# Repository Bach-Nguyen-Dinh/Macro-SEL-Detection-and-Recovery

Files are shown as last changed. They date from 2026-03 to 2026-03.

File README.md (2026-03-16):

# Macro-SEL Detection and Recovery

A **hardware-only, autonomous protection system** for an ARM Cortex-A72 Edge Computer in LEO orbit. Detects and recovers from Macro Single Event Latchup (MacroSEL) events across 6 power rails — no firmware, no supervisory controller.

---

## Functional Overview

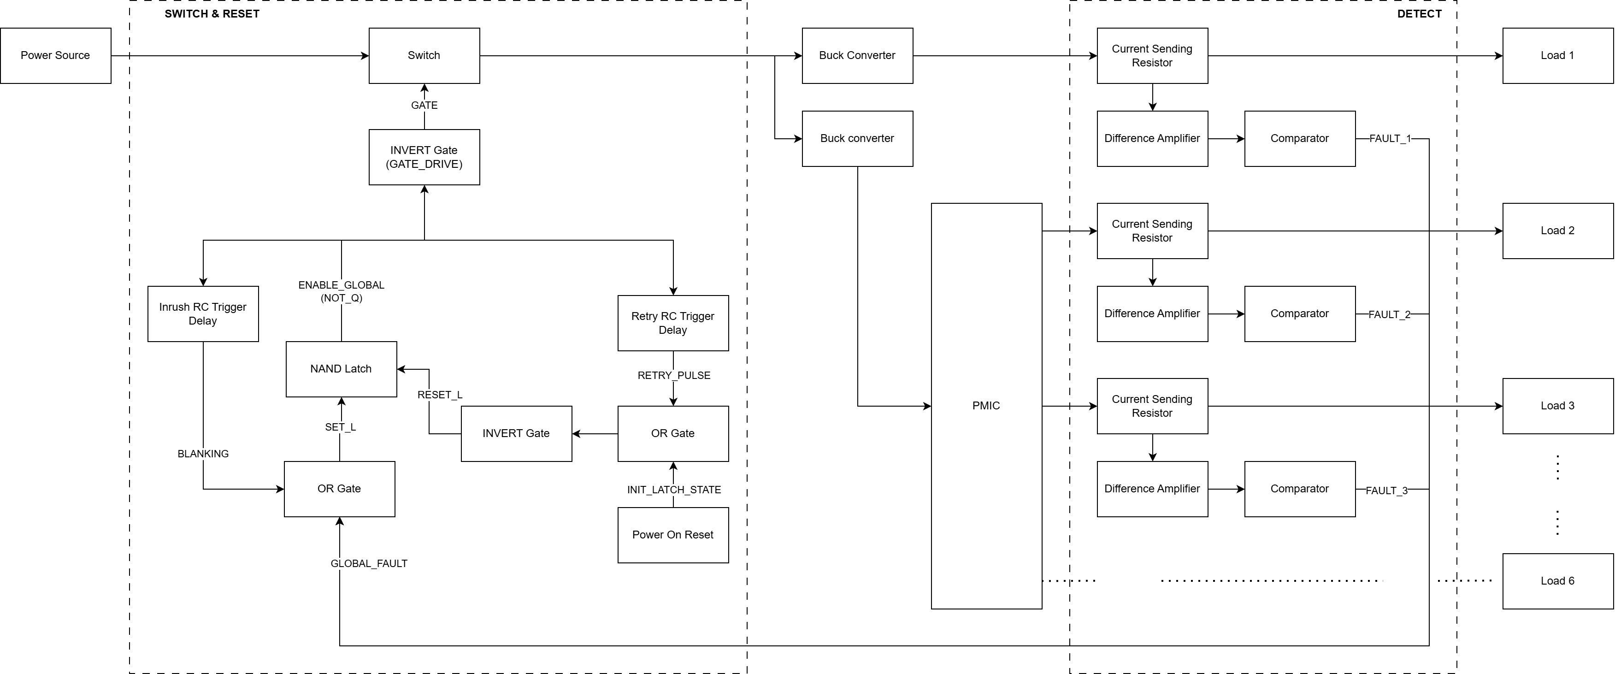
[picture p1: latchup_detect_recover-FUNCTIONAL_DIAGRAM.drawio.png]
Functional Diagram


On a latchup event, current on any protected rail exceeds 150% of its rated value. The protection system detects this within **3.64 µs**, latches the fault, cuts power via a master P-FET, and automatically retries after ~1 second.

---

## Mission Profile

| Parameter | Value |
|---|---|
| Orbit | LEO ~400 km |
| Mission life | 3-year minimum |
| TID environment | ~3–15 krad/year (shielding-dependent) |
| All-IC TID rating | ≥ 30 krad(Si) |
| LET hardness | 43–46 MeV·cm²/mg |

---

## Protected Power Rails

Trip threshold: **150% of rated current** on each rail.

| Rail | Voltage | Rated Current | Load | Shunt | Trip Current |
|---|---|---|---|---|---|
| 1 | 3.3 V | 5 A | AI Core #1 | 10 mΩ | 7.5 A |
| 2 | 3.3 V | 5 A | AI Core #2 | 10 mΩ | 7.5 A |
| 3 | 1.2 V | 3 A | CPU + DDR4 | 10 mΩ | 4.5 A |
| 4 | 1.35 V | 400 mA | CPU | 50 mΩ | 0.6 A |
| 5 | 1.8 V | 2 A | CPU + eMMC | 10 mΩ | 3.0 A |
| 6 | 2.5 V | 1 A | CPU + DDR4 | 10 mΩ | 1.5 A |

> Rail 4 uses 50 mΩ instead of 10 mΩ to achieve 300 kHz bandwidth (1.16 µs rise time) without excessive amplifier gain.

---

## Signal Flow

1. **Shunt resistor** — converts rail current to a millivolt-level differential voltage
2. **Stage 1: Difference amplifiers** (OPA4H838-SEP) — amplify shunt voltage to ~988 mV at trip point
3. **Stage 2: Comparators** (TLV1704-SEP, open-drain) — compare amplified signal to V_ref; pull shared wired-AND bus LOW on fault
4. **Wired-AND bus** — any single fault drives GLOBAL_FAULT LOW
5. **Blanking timer** (SN54SC6T17-SEP, 12–18 ms) — masks inrush false faults at startup
6. **SR latch** (SN54SC4T00-SEP) — latches fault state; holds ENABLE_GLOBAL LOW even after rails collapse
7. **Retry timer** (SN54SC6T17-SEP, τ = 2.2 s) — fires RETRY_PULSE ~0.79 s after fault, resets latch, attempts recovery
8. **Gate driver** (SN54SC6T14-SEP) — drives master P-FET gate; fail-safe OFF if driver loses power
9. **Master FET** (BUP06CP038F-01, P-channel) — switches all protected rails simultaneously

### Total Fault Response Time: 3.64 µs

| Stage | Delay |
|---|---|
| Amplifier rise (worst case, Rail 6) | 2.30 µs |
| Comparator propagation | 0.56 µs |
| Logic gates (OR + SR latch + inverter) | ~0.03 µs |
| P-FET turn-off (worst-case 3τ) | 0.75 µs |

---

## Bill of Materials

| Ref | Part | Function | Qty |
|-----|---|---|-----|
| Q1 | BUP06CP038F-01 | Master P-FET (−35 A cont., −140 A pulsed, 38 mΩ R_DS(on)) | 1 |
| U_AMP_A/B | OPA4H838-SEP | Quad op-amp — current sense amplifier | 2 |
| U_CMP_A/B | TLV1704-SEP | Quad comparator — open-drain output | 2 |
| U_LATCH | SN54SC4T00-SEP | Quad NAND — SR latch | 1 |
| U_OR | SN54SC4T32-SEP | Quad OR — SET_L + RESET_L logic | 1 |
| U_SCH | SN54SC6T17-SEP | Hex Schmitt — blanking timer + retry timer | 1 |
| U_INV | SN54SC6T14-SEP | Hex Schmitt inverter — gate driver + reset logic | 1 |
| Q_dis | JANSR2N3700UB | NPN — retry timer capacitor discharge | 1 |
| R_shunt (×5) | WSL2512R0100FEA | 10 mΩ ±1%, 2 W, Kelvin 4-wire | 5 |
| R_shunt (×1) | WSL2512R0500FEA | 50 mΩ ±1%, 2 W, Kelvin 4-wire (Rail 4) | 1 |

**Power**: Single 5 V spacecraft bus rail. Total consumption ~6.5 mA @ 5 V = **33 mW** (0.13% of 25 W system budget).

---

## Repository Structure

```
latchup_design/
├── AICRAFT_latchup_detect_recover.pdf       # Formal design document (authoritative)
├── MacroSEL_v4_Complete.docx                # Supporting reference
├── latchup_detect_recover.drawio            # draw.io source
├── latchup_detect_recover-*.drawio.png      # Sub-block diagrams
├── latchup_v4.0/                            # Component datasheets (flight parts)
│   ├── application_notes/                   # Referenced app notes
│   └── prototype_commercial_parts/          # Commercial equivalents for lab testing
└── latchup_v3.1/                            # Historical datasheets (v3.1)
```

### Circuit Diagrams

| File | Sub-block |
|---|---|
| `latchup_detect_recover-FUNCTIONAL_DIAGRAM.drawio.png` | Top-level system overview |
| `latchup_detect_recover-current_sense_amplifier.drawio.png` | Stage 1 difference amplifier |
| `latchup_detect_recover-comparator.drawio.png` | Stage 2 comparator |
| `latchup_detect_recover-Wired_AND_bus.drawio.png` | Open-drain fault aggregation |
| `latchup_detect_recover-NAND_SR_latch.drawio.png` | Fault state memory |
| `latchup_detect_recover-reference_voltage.drawio.png` | V_ref resistor divider |
| `latchup_detect_recover-power_on_reset.drawio.png` | Power-on reset |
| `latchup_detect_recover-delay_startup.drawio.png` | Startup blanking timer |
| `latchup_detect_recover-delay_retry.drawio.png` | Retry timer |
| `latchup_detect_recover-retry_pulse_gen.drawio.png` | Retry pulse generator |
| `latchup_detect_recover-set_fault_latched.drawio.png` | Set/reset OR logic |
| `latchup_detect_recover-gate_driver.drawio.png` | P-FET gate driver |
| `latchup_detect_recover-test_bench.drawio.png` | Test bench |

---

## Design Philosophy

- **Hardware-only** — no microcontroller, no firmware, no single point of software failure
- **Fail-safe OFF** — master FET turns off if gate driver loses power (10 kΩ pull-up to 5 V)
- **Every component justifies its existence** — no redundant logic, no speculative features
- **Single power domain** — all protection circuits powered from 5 V spacecraft bus, independent of protected rails

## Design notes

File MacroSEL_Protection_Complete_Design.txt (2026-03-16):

================================================================================
MACRO-SEL PROTECTION SYSTEM - COMPLETE DESIGN PACKAGE
Space-Qualified Edge Computer for LEO Orbit
================================================================================

Document Version: 1.0
Date: February 2026
Application: ARM Cortex-A72 Edge Computer with AI Cores, DDR4, eMMC
Mission Profile: LEO, 1+ year, 10 krad/year TID
Design Philosophy: Hardware-only, interconnected shutdown, 5 retry attempts

================================================================================
TABLE OF CONTENTS
================================================================================

1. SYSTEM ARCHITECTURE OVERVIEW
2. DETAILED SCHEMATIC: SINGLE RAIL PROTECTION CIRCUIT
3. GLOBAL LOGIC & RETRY CONTROLLER SCHEMATIC
4. FULL 6-RAIL SYSTEM INTEGRATION
5. COMPLETE BILL OF MATERIALS (BOM)
6. PCB LAYOUT GUIDELINES
7. TESTING & VALIDATION PROCEDURES
8. FAILURE MODE & EFFECTS ANALYSIS (FMEA)
9. DESIGN VERIFICATION CHECKLIST

================================================================================
1. SYSTEM ARCHITECTURE OVERVIEW
================================================================================

PROTECTION STRATEGY:
- 6 independent protection circuits (one per power rail)
- Interconnected shutdown: ANY rail fault → ALL rails shut down
- Hardware-only auto-retry: 5 attempts with 100ms delay
- After 5 failures: Permanent latch-off until power cycle
- 300ms startup delay from PMIC PGOOD signal

PROTECTED RAILS:
Rail #1: 3.3V @ 5A  (AI Core #1)
Rail #2: 3.3V @ 5A  (AI Core #2)
Rail #3: 1.2V @ 3A  (CPU + DDR4 RAM)
Rail #4: 1.35V @ 400mA (CPU)
Rail #5: 1.8V @ 2A  (CPU + eMMC)
Rail #6: 2.5V @ 1A  (CPU + DDR4 RAM)

RESPONSE TIME TARGET: <20µs (well within macro-SEL damage threshold of ~100µs)

RADIATION TOLERANCE: All protection components rated 50-100+ krad TID

================================================================================
2. DETAILED SCHEMATIC: SINGLE RAIL PROTECTION CIRCUIT (TYPICAL)
================================================================================

This schematic applies to ONE rail. Replicate 6 times with component values
adjusted per rail specifications.

Example: Rail #3 (1.2V @ 3A - CPU + DDR4 RAM)

┌────────────────────────────────────────────────────────────────────────┐
│                     SINGLE RAIL PROTECTION CIRCUIT                      │
│                          (Typical - 1.2V 3A Rail)                       │
└────────────────────────────────────────────────────────────────────────┘

INPUT (from PMIC)                                   OUTPUT (to Load - CPU/RAM)
    │                                                        │
    ├─────[R_SENSE: 20mΩ, 2W]─────┬──────[P_FET]──────────┤
    │                              │       Q1               │
    │                              │                        │
    │  ┌──[R1: 10kΩ]──┬──────────┤GATE                    │
    │  │              │            │                        │
    │  │              │            │SOURCE                  │
    │  │              └────────────┤                        │
    │  │                           │                        │
    │  │                           │DRAIN                   │
    │  │                           └────────────────────────┤
    │  │                                                    │
    │  │  CURRENT SENSE AMPLIFIER (OP07)                   │
    │  │                                                    │
    │  │      V_SENSE+              V_SENSE-               │
    │  │          │                     │                  │
    │  │          ↓                     ↓                  │
    │  │      ┌───────────────────────────┐               │
    │  │      │         OP07              │               │
    │  │      │    (Diff Amplifier)       │               │
    │  │      │      Gain = 20            │               │
    │  │      └──────────┬────────────────┘               │
    │  │                 │ V_AMP (0-2V range)             │
    │  │                 │                                │
    │  │                 │                                │
    │  │      COMPARATOR & LATCH                          │
    │  │                 │                                │
    │  │                 ↓                                │
    │  │      ┌───────────────────────┐                   │
    │  │      │     LM139AJ           │                   │
    │  │  ┌───┤+  (Threshold: 70mV×20 │                   │
    │  │  │   │      = 1.4V)          │                   │
    │  │  │V_REF -                    │                   │
    │  │  │   └─────────┬─────────────┘                   │
    │  │  │             │ FAULT_RAW                       │
    │  │  │             │                                 │
    │  │  │             ↓                                 │
    │  │  │   ┌──────────────────────┐                   │
    │  │  │   │   CD4013BE           │                   │
    │  │  │   │   D Flip-Flop        │                   │
    │  │  └───┤D                     Q├───┐               │
    │  │      │                       │   │ FAULT_LATCHED │
    │  │  ┌───┤CLK              /Q    │   │ (to Global OR)│
    │  │  │   │                       │   │               │
    │  │  │   │         RESET ────────┤───┘               │
    │  │  │   └───────────────────────┘   │               │
    │  │  │                               │               │
    │  │  │                               │               │
    │  │  │   GATE DRIVER LOGIC           │               │
    │  │  │                               │               │
    │  │  │   ENABLE_GLOBAL ──┐           │               │
    │  │  │                   │           │               │
    │  │  │                   ↓           │               │
    │  │  │            ┌─────────────┐    │               │
    │  │  │            │  CD4081BE   │    │               │
    │  │  │            │  (AND gate) │    │               │
    │  │  └────────────┤             │    │               │
    │  │               └──────┬──────┘    │               │
    │  │                      │ GATE_CTRL │               │
    │  │                      └───────────┴───[R2: 100Ω]──┘
    │  │
    │  └──────────────────────────────────────────────[R3: 10kΩ to VIN]
    │
    └───────────────────────────[Bulk Cap: 100µF]─────────GND

COMPONENT VALUES FOR RAIL #3 (1.2V @ 3A):

R_SENSE:  20mΩ, 2W (Vishay WSL2512 or equivalent)
          Normal: 3A × 20mΩ = 60mV
          Trip: 3.5A × 20mΩ = 70mV

Q1:       IRHLUC7970Z4 (P-channel MOSFET, rad-hard, 100V, 30mΩ RDS(on))
          or IRH8S9N50R (alternative)

U1:       OP07CP (Bipolar op-amp, 100+ krad TID, QML available)
          Configured as differential amplifier, Gain = 20
          Output: 60mV × 20 = 1.2V (normal), 70mV × 20 = 1.4V (trip)

U2:       LM139AJ/883C (Quad comparator, 100+ krad TID, QML)
          V_REF = 1.3V (set by voltage divider)
          Hysteresis: 50mV via positive feedback

U3:       CD4013BE/883B (Dual D Flip-Flop, 100+ krad TID, CMOS)
          Latches fault condition until RESET pulse

U4:       CD4081BE/883B (Quad 2-input AND gate, 100+ krad TID, CMOS)
          Gates ENABLE with latched fault signal

R1:       10kΩ (pull-up for P-FET gate)
R2:       100Ω (gate drive resistor, limits dI/dt)
R3:       10kΩ (pull-down when FET should be off)

All resistors: Metal film, 1%, 0.1W minimum
All capacitors: Ceramic C0G/NP0 or tantalum, space-qualified

SENSE RESISTOR & TRIP THRESHOLD TABLE FOR ALL 6 RAILS:

┌─────────┬────────────┬────────┬─────────┬──────────┬────────────┬──────────┐
│  Rail   │  Voltage   │ Normal │  Trip   │ R_SENSE  │  V_SENSE   │  V_AMP   │
│         │            │ Current│ Current │          │  @ Trip    │  @ Trip  │
├─────────┼────────────┼────────┼─────────┼──────────┼────────────┼──────────┤
│ AI #1   │ 3.3V       │ 5.0A   │ 5.8A    │ 10mΩ, 2W │ 58mV       │ 1.16V    │
│ AI #2   │ 3.3V       │ 5.0A   │ 5.8A    │ 10mΩ, 2W │ 58mV       │ 1.16V    │
│ CPU/RAM │ 1.2V       │ 3.0A   │ 3.5A    │ 20mΩ, 2W │ 70mV       │ 1.40V    │
│ CPU     │ 1.35V      │ 0.4A   │ 0.5A    │ 100mΩ, 1W│ 50mV       │ 1.00V    │
│ CPU/eMMC│ 1.8V       │ 2.0A   │ 2.3A    │ 30mΩ, 1W │ 69mV       │ 1.38V    │
│ CPU/RAM │ 2.5V       │ 1.0A   │ 1.2A    │ 50mΩ, 1W │ 60mV       │ 1.20V    │
└─────────┴────────────┴────────┴─────────┴──────────┴────────────┴──────────┘

Note: Amplifier gain = 20 for all rails
      Comparator V_REF adjusted per rail (trip voltage × 20)

SIGNAL NAMES & INTERCONNECTIONS:

Per-Rail Signals:
- FAULT_LATCHED_n (where n = 1 to 6): Goes to Global OR gate
- ENABLE_GLOBAL: Comes from Global Logic, enables all protection circuits

Power Connections:
- VIN_n: Input from PMIC for each rail
- VOUT_n: Output to load for each rail
- VDD_LOGIC: +5V for logic ICs (from main 5V bus)
- GND: Common ground

================================================================================
3. GLOBAL LOGIC & RETRY CONTROLLER SCHEMATIC
================================================================================

This circuit manages:
1. 300ms startup delay from PMIC PGOOD
2. Fault aggregation from all 6 rails
3. Retry counter (5 attempts)
4. 100ms inter-retry delay
5. Permanent latch-off after 5 failures

┌────────────────────────────────────────────────────────────────────────┐
│                   GLOBAL LOGIC & RETRY CONTROLLER                       │
└────────────────────────────────────────────────────────────────────────┘

SECTION A: STARTUP DELAY (300ms from PMIC PGOOD)

PMIC_PGOOD ──┬─────[R4: 1MΩ]───┬───────┐
             │                  │       │
             │                  │       ↓
             │              [C1: 330nF] │  ┌──────────────────┐
             │                  │       │  │   CD4093BE       │
             │                  │       └──┤  Schmitt Trigger │
             │                  │          │   (Buffer)       │
             └──────────────────┴──────────┤                  ├──→ PGOOD_DELAYED
                                            └──────────────────┘

Time constant: τ = R4 × C1 = 1MΩ × 330nF = 330ms

SECTION B: FAULT AGGREGATION (6-input OR gate)

FAULT_LATCHED_1 ──┐
FAULT_LATCHED_2 ──┤
FAULT_LATCHED_3 ──┤  ┌──────────────────┐
FAULT_LATCHED_4 ──┼──┤   CD4072BE       │
FAULT_LATCHED_5 ──┤  │   (Dual 4-input  │
FAULT_LATCHED_6 ──┘  │    OR gate)      ├───→ GLOBAL_FAULT
                     └──────────────────┘

Note: Use 2× CD4072BE to implement 6-input OR
      (each CD4072BE has dual 4-input OR gates)

SECTION C: RETRY TIMER (100ms delay generator)

GLOBAL_FAULT ──→ Trigger

                 ┌──────────────────────┐
                 │      LM555CN         │
                 │  (Monostable timer)  │
                 │                      │
   VDD ──[R5]────┤DISCH        OUT      ├───→ RETRY_PULSE (100ms pulse)
          │      │                      │
          │      │                      │
       [C2]──────┤THRESH         GND    │
          │      │                      │
          │      │TRIG                  │
          │      └──────────────────────┘
          │          ↑
          │          │
        [R6]─────────┴──── GLOBAL_FAULT (inverted trigger)
          │
         GND

Component Values:
R5 = 1MΩ
C2 = 100nF
R6 = 10kΩ (trigger resistor)

Time delay: t = 1.1 × R5 × C2 = 1.1 × 1MΩ × 100nF = 110ms

SECTION D: RETRY COUNTER (counts fault events, max = 5)

RETRY_PULSE ──→ CLK

                 ┌──────────────────────┐
                 │      CD4017BE        │
                 │   (Decade Counter)   │
                 │                      │
   RETRY_PULSE ──┤CLK              Q0   ├───→ (unused)
                 │                 Q1   ├───→ (unused)
                 │                 Q2   ├───→ (unused)
                 │                 Q3   ├───→ (unused)
                 │                 Q4   ├───→ (unused)
                 │                 Q5   ├───→ COUNT_5 (5th retry)
                 │                 Q6-9 ├───→ (unused)
                 │                      │
   POWER_CYCLE ──┤RESET                 │
                 └──────────────────────┘

SECTION E: PERMANENT LATCH (after 5 retries, latch off)

COUNT_5 ──→ SET

                 ┌──────────────────────┐
                 │      CD4013BE        │
                 │     (D Flip-Flop)    │
                 │                      │
      VDD ───────┤D                  Q  ├───→ LATCH_OFF
                 │                      │
   COUNT_5 ──────┤SET                   │
                 │                      │
   POWER_CYCLE ──┤RESET                 │
                 └──────────────────────┘

SECTION F: GLOBAL ENABLE GENERATION

Combines all enable/disable conditions:

ENABLE_GLOBAL = PGOOD_DELAYED AND (NOT LATCH_OFF) AND (NOT RETRY_IN_PROGRESS)

                 ┌──────────────────────┐
PGOOD_DELAYED ───┤                      │
                 │    CD4081BE          │
(NOT LATCH_OFF)──┤    (3-input AND)     ├───→ ENABLE_GLOBAL
                 │    (configured)      │     (to all 6 protection circuits)
(NOT RETRY_PROG.)┤                      │
                 └──────────────────────┘

RETRY_IN_PROGRESS = RETRY_PULSE (active during 100ms retry delay)

SECTION G: RESET PULSE GENERATOR (resets all D flip-flops after retry delay)

RETRY_PULSE (falling edge) triggers a short pulse to reset fault latches

                 ┌──────────────────────┐
RETRY_PULSE ─────┤     Edge Detector    │
  (falling) ─────┤   (R-C differentiator)├───→ RESET_PULSE (to all fault latches)
                 └──────────────────────┘

Circuit: Simple RC high-pass filter + diode
         Rising edge blocks, falling edge passes through as short pulse

POWER SUPPLY FOR LOGIC:
- VDD_LOGIC: +5V (from main 5V power bus)
- All logic ICs powered from this rail
- Decouple each IC with 0.1µF + 10µF tantalum local to each IC

COMPLETE SIGNAL FLOW:

1. Power-on: PMIC_PGOOD goes high
2. After 300ms: PGOOD_DELAYED goes high
3. ENABLE_GLOBAL = HIGH (all protection circuits enabled)
4. If latchup occurs on any rail → FAULT_LATCHED_n goes HIGH
5. GLOBAL_FAULT = HIGH (OR of all 6 fault signals)
6. LM555 triggers: RETRY_PULSE = HIGH for 100ms
7. During RETRY_PULSE: ENABLE_GLOBAL = LOW (all rails shut down)
8. After 100ms: RETRY_PULSE falling edge generates RESET_PULSE
9. RESET_PULSE clears all fault latches, ENABLE_GLOBAL = HIGH (retry)
10. Retry counter increments (CD4017BE)
11. Repeat steps 4-10 up to 5 times
12. On 5th retry: COUNT_5 sets LATCH_OFF permanently
13. ENABLE_GLOBAL = LOW forever (until power cycle)

================================================================================
4. FULL 6-RAIL SYSTEM INTEGRATION DIAGRAM
================================================================================

                        ┌──────────────────────────────────┐
                        │      PMIC (MC33PF8100EAES)       │
                        │                                  │
     5V Input ──────────┤VIN                          PGOOD├──→ To Global Logic
                        │                                  │
                        │    1.2V ──────────────────────── ├──→ Rail #3 Input
                        │    1.35V ─────────────────────── ├──→ Rail #4 Input
                        │    1.8V ──────────────────────── ├──→ Rail #5 Input
                        │    2.5V ──────────────────────── ├──→ Rail #6 Input
                        └──────────────────────────────────┘
                                         │
                                         │
      ┌──────────────────────────────────┴──────────────────────────────┐
      │                                                                  │
      │         Buck Converter #1 (LTC3310S)                             │
      │         3.3V 10A (for both AI cores)                             │
      │                                                                  │
      │    3.3V AI ────────────────────────────────────────────────────→ Rail #1 Input
      │    3.3V AI ────────────────────────────────────────────────────→ Rail #2 Input
      └──────────────────────────────────────────────────────────────────┘

                   ┌─────────────────────────────────────┐
                   │     GLOBAL LOGIC & RETRY CONTROLLER │
                   │                                     │
    PMIC_PGOOD ────┤Input                                │
                   │                                     │
    FAULT_1 ───────┤──┐                                  │
    FAULT_2 ───────┤  │                                  │
    FAULT_3 ───────┤  ├──→ OR Gate                      │
    FAULT_4 ───────┤  │                                  │
    FAULT_5 ───────┤  │                                  │
    FAULT_6 ───────┤──┘                                  │
                   │         ↓                           │
                   │    Retry Logic                      │
                   │         ↓                           │
                   │   ENABLE_GLOBAL ────────────────────┼──→ To all 6 protection circuits
                   │   RESET_PULSE ──────────────────────┼──→ To all 6 fault latches
                   └─────────────────────────────────────┘

        ┌───────────────────────────────────────────────────────────┐
        │                    6 PROTECTION CIRCUITS                  │
        │                       (One per rail)                      │
        ├───────────────────────────────────────────────────────────┤
        │                                                           │
        │  Rail #1: 3.3V 5A (AI Core #1)    ──→ Sense → Compare ──┼──→ FAULT_1
        │  Rail #2: 3.3V 5A (AI Core #2)    ──→ Sense → Compare ──┼──→ FAULT_2
        │  Rail #3: 1.2V 3A (CPU + RAM)     ──→ Sense → Compare ──┼──→ FAULT_3
        │  Rail #4: 1.35V 400mA (CPU)       ──→ Sense → Compare ──┼──→ FAULT_4
        │  Rail #5: 1.8V 2A (CPU + eMMC)    ──→ Sense → Compare ──┼──→ FAULT_5
        │  Rail #6: 2.5V 1A (CPU + RAM)     ──→ Sense → Compare ──┼──→ FAULT_6
        │                                                           │
        │  Each circuit contains:                                  │
        │  - Sense resistor + amplifier                            │
        │  - Comparator + latch                                    │
        │  - P-FET load switch                                     │
        └───────────────────────────────────────────────────────────┘
                            ↓            ↓
                      Outputs to:   Outputs to:
                    Protected Loads  Global Logic

SYSTEM BEHAVIOR SUMMARY:

Normal Operation:
- All 6 rails powered and monitored
- Current < threshold → No faults
- ENABLE_GLOBAL = HIGH

Latchup Event (e.g., on Rail #3):
1. Current spikes above 3.5A threshold
2. FAULT_3 goes HIGH
3. GLOBAL_FAULT = HIGH (via OR gate)
4. ALL 6 protection circuits disable (ENABLE_GLOBAL = LOW)
5. Wait 100ms
6. Reset all latches, ENABLE_GLOBAL = HIGH (1st retry)
7. Increment retry counter
8. If latchup recurs → repeat up to 5 times total
9. After 5th retry → LATCH_OFF permanently until power cycle

================================================================================
5. COMPLETE BILL OF MATERIALS (BOM)
================================================================================

PER-RAIL COMPONENTS (×6 sets):

┌──────┬─────────────────────┬──────────┬──────────────────────┬──────────┬────────┐
│ Qty  │ Part Number         │ Function │ Description          │ Rad Tol. │ Cost   │
├──────┼─────────────────────┼──────────┼──────────────────────┼──────────┼────────┤
│  6   │ WSL2512 (various)   │ R_SENSE  │ Current sense        │ Passive  │ $3 ea  │
│      │   10mΩ, 20mΩ, etc.  │          │ resistor, 1-2W       │ (rad-hard)│       │
├──────┼─────────────────────┼──────────┼──────────────────────┼──────────┼────────┤
│  6   │ OP07CP or           │ U1       │ Precision op-amp     │ 100+ krad│ $25 ea │
│      │ OP07CP/883B (QML)   │          │ for sense amplifier  │          │        │
├──────┼─────────────────────┼──────────┼──────────────────────┼──────────┼────────┤
│  2   │ LM139AJ/883C        │ U2       │ Quad comparator      │ 100+ krad│ $30 ea │
│      │ (each has 4 comps)  │          │ (need 6 total)       │          │        │
├──────┼─────────────────────┼──────────┼──────────────────────┼──────────┼────────┤
│  6   │ IRHLUC7970Z4 or     │ Q1       │ P-channel MOSFET     │ 100 krad │ $50 ea │
│      │ IRH8S9N50R          │          │ load switch          │          │        │
├──────┼─────────────────────┼──────────┼──────────────────────┼──────────┼────────┤
│  3   │ CD4013BE/883B       │ U3       │ Dual D flip-flop     │ 100+ krad│ $20 ea │
│      │ (each has 2 FFs)    │          │ (need 6 total)       │          │        │
├──────┼─────────────────────┼──────────┼──────────────────────┼──────────┼────────┤
│  2   │ CD4081BE/883B       │ U4       │ Quad 2-input AND     │ 100+ krad│ $18 ea │
│      │ (each has 4 ANDs)   │          │ (need 6 total)       │          │        │
└──────┴─────────────────────┴──────────┴──────────────────────┴──────────┴────────┘

Subtotal per-rail components: ~$146 × 6 = $876

GLOBAL LOGIC COMPONENTS (×1 set):

┌──────┬─────────────────────┬──────────┬──────────────────────┬──────────┬────────┐
│ Qty  │ Part Number         │ Function │ Description          │ Rad Tol. │ Cost   │
├──────┼─────────────────────┼──────────┼──────────────────────┼──────────┼────────┤
│  2   │ CD4072BE/883B       │ U5       │ Dual 4-input OR      │ 100+ krad│ $22 ea │
│      │                     │          │ (for 6-input OR)     │          │        │
├──────┼─────────────────────┼──────────┼──────────────────────┼──────────┼────────┤
│  1   │ CD4093BE/883B       │ U6       │ Quad Schmitt trigger │ 100+ krad│ $20    │
│      │                     │          │ NAND buffer          │          │        │
├──────┼─────────────────────┼──────────┼──────────────────────┼──────────┼────────┤
│  1   │ LM555CN/883C        │ U7       │ Timer IC             │ 100+ krad│ $28    │
│      │                     │          │ (retry delay)        │          │        │
├──────┼─────────────────────┼──────────┼──────────────────────┼──────────┼────────┤
│  1   │ CD4017BE/883B       │ U8       │ Decade counter       │ 100+ krad│ $22    │
│      │                     │          │ (retry counter)      │          │        │
├──────┼─────────────────────┼──────────┼──────────────────────┼──────────┼────────┤
│  1   │ CD4013BE/883B       │ U9       │ Dual D flip-flop     │ 100+ krad│ $20    │
│      │                     │          │ (latch-off FF)       │          │        │
├──────┼─────────────────────┼──────────┼──────────────────────┼──────────┼────────┤
│  1   │ CD4081BE/883B       │ U10      │ Quad AND gate        │ 100+ krad│ $18    │
│      │                     │          │ (enable logic)       │          │        │
├──────┼─────────────────────┼──────────┼──────────────────────┼──────────┼────────┤
│  1   │ CD4049UBE/883B      │ U11      │ Hex inverter/buffer  │ 100+ krad│ $18    │
│      │                     │          │ (logic inversion)    │          │        │
└──────┴─────────────────────┴──────────┴──────────────────────┴──────────┴────────┘

Subtotal global logic: $170

PASSIVE COMPONENTS:

┌──────┬─────────────────────┬──────────┬──────────────────────┬──────────┬────────┐
│ Qty  │ Description         │ Function │ Specifications       │ Notes    │ Cost   │
├──────┼─────────────────────┼──────────┼──────────────────────┼──────────┼────────┤
│  40  │ Resistors (various) │ Biasing  │ 1/8W to 1/4W,        │ Metal    │ $1 ea  │
│      │ 100Ω - 1MΩ          │ timing   │ 1%, metal film       │ film     │        │
├──────┼─────────────────────┼──────────┼──────────────────────┼──────────┼────────┤
│  20  │ Capacitors 0.1µF    │ Decoupl. │ Ceramic C0G/NP0      │ Local to │ $2 ea  │
│      │                     │          │ 50V, space-qual      │ each IC  │        │
├──────┼─────────────────────┼──────────┼──────────────────────┼──────────┼────────┤
│  15  │ Capacitors 10µF     │ Bulk     │ Tantalum or ceramic  │ Power    │ $5 ea  │
│      │                     │ decoupl. │ 16V min              │ supply   │        │
├──────┼─────────────────────┼──────────┼──────────────────────┼──────────┼────────┤
│  6   │ Capacitors 100µF    │ Output   │ Tantalum or ceramic  │ Per rail │ $8 ea  │
│      │                     │ filter   │ Low ESR, rated for   │ output   │        │
│      │                     │          │ rail voltage         │          │        │
├──────┼─────────────────────┼──────────┼──────────────────────┼──────────┼────────┤
│  3   │ Timing capacitors   │ 555,RC   │ 100nF, 330nF         │ Timing   │ $3 ea  │
│      │ (330nF, 100nF)      │ networks │ C0G/NP0 ceramic      │ critical │        │
└──────┴─────────────────────┴──────────┴──────────────────────┴──────────┴────────┘

Subtotal passives: ~$200

GRAND TOTAL BOM COST: $876 + $170 + $200 = **$1,246**

Note: Costs are estimates. QML/QMLV space-qualified parts may vary.
      Long-lead items: MOSFET switches (~12-16 weeks), QML logic ICs (~8-12 weeks)

ALTERNATIVE COMPONENT SELECTIONS:

If IRHLUC7970Z4 unavailable:
- Alternative 1: SI4425DDY-T1-GE3 (vishay, lower cost, ~30 krad)
- Alternative 2: Custom discrete with bipolar transistors (100% rad-hard)

If OP07CP unavailable:
- Alternative: LM124A/883 (quad op-amp, lower precision but adequate)

All CD4000 series logic:
- Widely available in QML/QMLV grades
- Multiple suppliers (TI, Intersil/Renesas, ON Semi)

================================================================================
6. PCB LAYOUT GUIDELINES
================================================================================

CRITICAL LAYOUT REQUIREMENTS FOR SPACE ENVIRONMENT:

A. GENERAL PCB STACK-UP
   - 4-layer minimum (Signal-Ground-Power-Signal)
   - 6-layer preferred (S-G-S-P-G-S) for better EMI control
   - FR-4 acceptable for LEO (consider polyimide for harsher environments)
   - Copper weight: 2oz minimum for power traces, 1oz for signals
   - Conformal coating: Yes (required for space, use silicone or acrylic)

B. POWER PATH LAYOUT (CRITICAL!)

   For each protection circuit:

   1. SENSE RESISTOR PLACEMENT:
      - Place R_SENSE as close as possible to input connector/via
      - Use 4-wire (Kelvin) connection:
         * Force+ and Force- carry load current (wide, short traces)
         * Sense+ and Sense- are thin traces directly to op-amp inputs
      - Keep sense traces away from switching nodes and high-current paths
      - Minimum trace width for sense lines: 10 mils (0.25mm)
      - Guard ring around sense traces (optional, for extra noise immunity)

      Layout example (top view):
      
      VIN ══════════[Force+]══════[R_SENSE]══════[Force-]════════ VOUT
                         │                          │
                    [Sense+]                   [Sense-]
                         │                          │
                         └─────→ To OP07 ←──────────┘
                         (thin traces, 10-15 mils)

   2. P-FET MOSFET PLACEMENT:
      - Place immediately after sense resistor (<5mm spacing if possible)
      - Minimize trace inductance in drain-source path (use wide, short traces)
      - Gate trace: Keep <50mm long, use series resistor (100Ω) near gate pin
      - Source connection: Star-point ground reference for gate driver
      - Heatsinking: Ensure thermal pad connected to ground plane (or dedicated)

   3. POWER TRACE WIDTHS (for 3A continuous, 5A peak):
      - 1.2V rail @ 3A: 80 mils (2mm) minimum width, 2oz copper
      - 3.3V rail @ 5A: 120 mils (3mm) minimum width, 2oz copper
      - Formula: I_max = 0.048 × dT^0.44 × A^0.725
        (where dT = temperature rise in °C, A = cross-sectional area in mils²)
      - For space: Derate by 50% (vacuum cooling is worse than air)

   4. DECOUPLING CAPACITOR PLACEMENT:
      - 0.1µF ceramic: <5mm from each IC VDD pin
      - 10µF tantalum: <10mm from each IC
      - 100µF bulk: At each rail output, near load connection
      - Via-in-pad for decoupling caps when possible (low inductance)

C. SIGNAL INTEGRITY (COMPARATOR & LOGIC)

   1. V_REF GENERATION:
      - Use precision voltage divider for comparator reference
      - Add 0.1µF bypass cap at V_REF node (local to comparator)
      - Keep V_REF trace <20mm long, away from switching nodes

   2. DIGITAL LOGIC TRACES:
      - Keep clock and pulse signals <50mm long
      - Use ground guard traces around critical signals (RETRY_PULSE, RESET_PULSE)
      - Minimize stub lengths on clock inputs (<5mm)

   3. FAULT SIGNAL ROUTING:
      - FAULT_LATCHED_1 to FAULT_LATCHED_6: Route together as bus
      - Use consistent spacing (50-100 mils between traces)
      - Avoid crossing power planes or high-current traces
      - Shielded by ground traces on either side if EMI is concern

D. GROUNDING STRATEGY

   Single-point star ground vs. ground plane:
   - Use ground plane (Layer 2) as primary reference
   - Create "analog island" for sense amplifier circuits:
      * Local ground pour for OP07 and comparator
      * Connect analog island to main ground at ONE point (star)
   - Digital logic: Use main ground plane (no isolation needed)
   - Power ground: Separate heavy current return paths from signal ground

   Ground plane stitching:
   - Place vias every 200-300 mils around perimeter of board
   - Additional vias near every decoupling capacitor (direct path to plane)

E. COMPONENT PLACEMENT STRATEGY

   Zone separation:
   ┌─────────────────────────────────────────────────┐
   │  ZONE 1: Input Filtering & Delay                │
   │  (PGOOD, RC delay, Schmitt trigger)             │
   │                                                 │
   ├─────────────────────────────────────────────────┤
   │  ZONE 2: Protection Circuits (6× identical)     │
   │  Rail 1 │ Rail 2 │ Rail 3 │ Rail 4 │ Rail 5 │ 6│
   │  (Sense)(Sense)(Sense)(Sense)(Sense)(Sense)   │
   │  (each 20×30mm footprint, total ~100×30mm)     │
   │                                                 │
   ├─────────────────────────────────────────────────┤
   │  ZONE 3: Global Logic                           │
   │  (OR gate, timer, counter, latch)               │
   │  (Keep compact, ~30×40mm)                       │
   └─────────────────────────────────────────────────┘

   Keep protection circuits identical and aligned for easy debug/rework.

F. THERMAL MANAGEMENT

   1. P-FET MOSFET:
      - Power dissipation: P = I²·RDS(on)
        Example: 5A² × 30mΩ = 0.75W per FET
      - Use thermal vias under FET thermal pad (array of 3×3 vias, 12 mil drill)
      - Connect to internal ground/power plane for heat spreading
      - Consider adding external heatsink or larger copper pour if >1W

   2. SENSE RESISTORS:
      - Power dissipation during latchup: I²·R (can be 1-2W briefly)
      - Use wide thermal relief connections (not thin "spider" reliefs)
      - Large copper pour around resistor body for heat spreading

   3. LM555 TIMER:
      - Can dissipate 100-200mW, provide thermal relief via bottom pad

G. EMI/EMC CONSIDERATIONS

   1. Switching transients (P-FET turn-off):
      - Use snubber across FET drain-source: 100Ω + 100nF in series
      - Minimize loop area between FET, sense resistor, and output capacitor

   2. Radiated emissions:
      - Route all high-frequency traces (comparator outputs, clock signals)
         on inner layers when possible
      - Keep traces >50 mils away from board edges

   3. Conducted emissions:
      - Input filtering: Add ferrite bead + 10µF cap on PMIC_PGOOD signal
      - Use common-mode chokes on power inputs if EMI is critical

H. CONFORMAL COATING CONSIDERATIONS

   - Mask off: Sense resistors (for thermal dissipation)
   - Mask off: Test points and rework areas
   - Ensure coating thickness: 50-100µm (2-4 mils)
   - Cure per space specifications (vacuum bake-out required)

I. TEST POINTS & DEBUG ACCESS

   Required test points (place on accessible layer):
   - TP1: PMIC_PGOOD
   - TP2: PGOOD_DELAYED
   - TP3: ENABLE_GLOBAL
   - TP4-TP9: FAULT_LATCHED_1 through FAULT_LATCHED_6
   - TP10: GLOBAL_FAULT
   - TP11: RETRY_PULSE
   - TP12: LATCH_OFF
   - TP13-TP18: V_AMP outputs (one per rail, for calibration)

   Use castellated holes or small vias (not plated) for semi-permanent access.

J. SPACE-SPECIFIC REQUIREMENTS

   1. Tin whisker mitigation:
      - Use matte tin plating (NOT bright tin)
      - Or use ENIG (Electroless Nickel Immersion Gold) finish

   2. Outgassing compliance:
      - PCB material: TML <1.0%, CVCM <0.1% (NASA ASTM E595)
      - Conformal coating: Space-qualified silicone (DC 1-2577) or acrylic

   3. Vibration/shock mounting:
      - Use edge-mounted support brackets
      - Avoid large, unsupported component bodies (>10mm tall)
      - Add potting to large capacitors (epoxy underfill)

   4. Thermal cycling:
      - Design for -40°C to +85°C operation (or wider if required)
      - Avoid mismatched CTE materials near critical junctions

K. DESIGN FOR TESTABILITY (DFT)

   - Break-out pads for each rail input/output (allow isolation testing)
   - Enable/disable jumpers for each protection circuit (debug one rail at a time)
   - LED indicators for FAULT_LATCHED signals (optional, for ground testing)

================================================================================
7. TESTING & VALIDATION PROCEDURES
================================================================================

PHASE 1: COMPONENT-LEVEL TESTING (Before PCB Assembly)
-------------------------------------------------------

Test 1.1: Sense Resistor Verification
   Objective: Verify resistance value and power rating
   Equipment: 4-wire ohmmeter, power supply, electronic load
   Procedure:
   1. Measure resistance with 4-wire ohmmeter (target: ±1% tolerance)
   2. Apply rated current for 10 minutes, measure temperature rise
   3. Verify temperature rise <50°C at full current
   Pass/Fail: Resistance within ±1%, temp rise <50°C

Test 1.2: P-FET MOSFET Characterization
   Objective: Verify RDS(on), gate threshold voltage, switching time
   Equipment: Curve tracer or parametric analyzer, oscilloscope
   Procedure:
   1. Measure RDS(on) at VGS = -5V, VDS = 1V, ID = 1A (target: <50mΩ)
   2. Measure VGS(th) with ID = 1mA (target: -1 to -3V)
   3. Apply 10Hz square wave to gate, measure turn-on/off times
   Pass/Fail: RDS(on) <50mΩ, VGS(th) within datasheet limits, tON/tOFF <1µs

Test 1.3: Op-Amp Offset Voltage
   Objective: Ensure low offset for accurate current sensing
   Equipment: Precision voltmeter, power supply
   Procedure:
   1. Power op-amp with ±5V
   2. Short inputs together, measure output voltage
   3. Calculate input offset: VOS = VOUT / Gain
   Pass/Fail: VOS <2mV (ideally <500µV for OP07)

Test 1.4: Comparator Propagation Delay
   Objective: Verify comparator response time
   Equipment: Function generator, oscilloscope
   Procedure:
   1. Apply slow ramp to comparator input (crossing threshold)
   2. Measure time from input crossing to output transition
   Pass/Fail: Propagation delay <500ns

PHASE 2: PROTECTION CIRCUIT FUNCTIONAL TESTING (Single Rail)
-------------------------------------------------------------

Test 2.1: Normal Operation (Below Threshold)
   Objective: Verify protection circuit does not false-trip
   Equipment: Power supply, electronic load, oscilloscope
   Procedure:
   1. Set input voltage to nominal (e.g., 1.2V for Rail #3)
   2. Apply load current at 90% of trip threshold (e.g., 2.7A for 3A rail)
   3. Monitor FAULT_LATCHED signal (should remain LOW)
   4. Observe output voltage (should equal input minus sense drop)
   Pass/Fail: FAULT_LATCHED = LOW, VOUT stable

Test 2.2: Overcurrent Trip (Above Threshold)
   Objective: Verify detection and isolation within response time
   Equipment: Power supply, electronic load (pulsed), oscilloscope
   Procedure:
   1. Set input voltage to nominal
   2. Configure load to pulse from 0A to 120% of trip threshold (e.g., 4.2A)
   3. Trigger oscilloscope on load pulse rising edge
   4. Measure time from load current exceeding threshold to P-FET turn-off
   5. Verify FAULT_LATCHED goes HIGH
   Pass/Fail: Response time <20µs, FAULT_LATCHED = HIGH

Test 2.3: Latch & Hold
   Objective: Verify fault remains latched until RESET
   Equipment: Same as Test 2.2
   Procedure:
   1. Trigger overcurrent event
   2. Verify FAULT_LATCHED = HIGH
   3. Reduce load current to zero
   4. Verify FAULT_LATCHED remains HIGH (latched)
   5. Apply RESET pulse (manually)
   6. Verify FAULT_LATCHED clears to LOW
   Pass/Fail: Fault latches and holds until RESET

Test 2.4: P-FET Safe Shutdown
   Objective: Verify load is isolated during fault
   Equipment: Power supply, electronic load, oscilloscope
   Procedure:
   1. Monitor output voltage during overcurrent trip
   2. Verify output voltage drops to <0.1V within 10µs of trip
   Pass/Fail: VOUT <0.1V within 10µs

PHASE 3: GLOBAL LOGIC & RETRY CONTROLLER TESTING
-------------------------------------------------

Test 3.1: Startup Delay (300ms from PGOOD)
   Objective: Verify enable delay prevents false trips during startup
   Equipment: Power supply, oscilloscope
   Procedure:
   1. Apply PMIC_PGOOD signal (simulate PMIC power-good)
   2. Trigger oscilloscope on PGOOD rising edge
   3. Measure time from PGOOD rising to PGOOD_DELAYED rising
   Pass/Fail: Delay = 300ms ±10%

Test 3.2: Fault Aggregation (6-input OR gate)
   Objective: Verify any single rail fault triggers global response
   Equipment: Function generator, oscilloscope
   Procedure:
   1. Apply LOW to all 6 FAULT_LATCHED inputs
   2. Verify GLOBAL_FAULT = LOW
   3. Set FAULT_LATCHED_n = HIGH (one at a time, n=1 to 6)
   4. Verify GLOBAL_FAULT = HIGH for each case
   Pass/Fail: GLOBAL_FAULT responds correctly to any input

Test 3.3: Retry Timer (100ms delay)
   Objective: Verify timer generates 100ms pulse
   Equipment: Function generator, oscilloscope
   Procedure:
   1. Trigger timer with GLOBAL_FAULT pulse
   2. Measure RETRY_PULSE duration
   Pass/Fail: RETRY_PULSE = 100ms ±10%

Test 3.4: Retry Counter (5 attempts)
   Objective: Verify counter increments and latches off after 5 retries
   Equipment: Function generator, oscilloscope, frequency counter
   Procedure:
   1. Apply 5 pulses to retry counter input (simulate 5 faults)
   2. Verify LATCH_OFF goes HIGH after 5th pulse
   3. Apply 6th pulse, verify LATCH_OFF remains HIGH
   Pass/Fail: LATCH_OFF = HIGH after exactly 5 pulses

Test 3.5: Global Enable Logic
   Objective: Verify ENABLE_GLOBAL combines all conditions correctly
   Equipment: Logic analyzer or multi-channel oscilloscope
   Procedure:
   1. Monitor PGOOD_DELAYED, LATCH_OFF, RETRY_IN_PROGRESS, ENABLE_GLOBAL
   2. Verify ENABLE_GLOBAL = HIGH only when:
      PGOOD_DELAYED = HIGH AND LATCH_OFF = LOW AND RETRY_IN_PROGRESS = LOW
   3. Test all combinations of input states
   Pass/Fail: Logic table verified for all states

PHASE 4: FULL SYSTEM INTEGRATION TESTING
-----------------------------------------

Test 4.1: Normal Operation (All 6 Rails)
   Objective: Verify system operates under normal load conditions
   Equipment: Multiple power supplies and electronic loads, DAQ system
   Procedure:
   1. Power up system (PMIC_PGOOD asserted)
   2. Wait for 300ms enable delay
   3. Apply nominal loads to all 6 rails (50-90% of rated current)
   4. Monitor all 6 outputs for 1 hour continuous operation
   5. Verify no false trips, all voltages stable
   Pass/Fail: No faults, all rails within ±2% of nominal voltage

Test 4.2: Single Rail Fault (Interconnected Shutdown)
   Objective: Verify one rail fault shuts down entire system
   Equipment: Same as Test 4.1
   Procedure:
   1. Operate system under normal load (all 6 rails active)
   2. Force overcurrent on Rail #3 (use programmable load)
   3. Verify ALL 6 protection circuits disable simultaneously
   4. Verify GLOBAL_FAULT = HIGH
   5. Wait for retry (100ms delay)
   6. Verify all rails re-enable together
   Pass/Fail: All rails shut down and restart together

Test 4.3: Retry Sequence (5 attempts)
   Objective: Verify system retries up to 5 times before permanent latch-off
   Equipment: Same as Test 4.1, data logger
   Procedure:
   1. Configure one rail (e.g., Rail #3) to persistently fault (constant overcurrent)
   2. Power up system, wait for enable
   3. Count number of retry cycles before permanent shutdown
   4. Verify LATCH_OFF = HIGH after 5th retry
   5. Verify system does not re-enable until power cycle
   Pass/Fail: Exactly 5 retries before permanent latch-off

Test 4.4: Power Cycle Recovery
   Objective: Verify system recovers after power cycle
   Equipment: Same as Test 4.1
   Procedure:
   1. After Test 4.3 (system latched off)
   2. Remove load that was causing fault
   3. Cycle PMIC_PGOOD (or main power)
   4. Verify system re-enables and operates normally
   Pass/Fail: System recovers after power cycle

Test 4.5: Thermal Cycling
   Objective: Verify operation over full temperature range
   Equipment: Thermal chamber, same as Test 4.1
   Procedure:
   1. Place system in thermal chamber
   2. Cycle temperature: -40°C → +25°C → +85°C → +25°C
   3. At each temperature extreme, run Test 4.1 (normal operation)
   4. Verify trip thresholds remain within ±5% across temperature
   Pass/Fail: System operates correctly at all temperatures

PHASE 5: RADIATION TESTING (Heavy Ion Beam)
--------------------------------------------

Test 5.1: TID Testing (Cumulative Dose)
   Objective: Verify protection circuit survives 10 krad TID
   Equipment: Co-60 gamma source or proton beam
   Procedure:
   1. Bias system during irradiation (powered and monitoring)
   2. Apply cumulative dose up to 15 krad (1.5× mission requirement)
   3. Measure trip threshold at 0, 5, 10, 15 krad dose points
   4. Verify functionality at each dose level
   Pass/Fail: Trip threshold remains within ±10% at 15 krad

Test 5.2: SEE Testing (Single Event Effects)
   Objective: Verify no single event latchup in protection circuit itself
   Facility: LBNL 88-Inch Cyclotron or TAMU Cyclotron (heavy ion beam)
   Procedure:
   1. Configure system in normal operating mode (all rails powered)
   2. Expose to heavy ion beam (Kr, Xe ions at LET = 40-75 MeV·cm²/mg)
   3. Monitor for SEL events in protection circuit components
   4. If SEL detected, verify protection circuit recovers or isolates
   5. Test at multiple ion species and energies
   Pass/Fail: No destructive SEL, any transient SEU recovers within 100ms

Test 5.3: Latchup Injection (Simulated SEL on Load)
   Objective: Verify protection system responds correctly to real latchup
   Equipment: Heavy ion beam, high-speed data acquisition
   Procedure:
   1. Expose CPU, AI cores, or RAM to heavy ion beam
   2. Wait for latchup event to occur naturally
   3. Monitor protection circuit response:
      - Detection time from latchup onset
      - Isolation time
      - Successful recovery after retry
   4. Verify no damage to load or protection circuit
   Pass/Fail: Protection system isolates latchup, system recovers

PHASE 6: QUALIFICATION & ACCEPTANCE TESTING
--------------------------------------------

Test 6.1: Vibration Testing (Sine & Random)
   Standard: MIL-STD-810 or NASA-GEVS
   Procedure:
   1. Mount board to vibration table
   2. Apply sine sweep (5-2000 Hz) at 1-20g
   3. Apply random vibration (20 Hz-2 kHz) at 14.1 g_rms for 1 minute per axis
   4. Inspect for:
      - Solder joint cracks
      - Component body cracks
      - Delamination
   5. Perform functional test (Phase 4) after vibration
   Pass/Fail: No mechanical failures, functional test passes

Test 6.2: Thermal Vacuum (TVAC) Testing
   Objective: Verify operation in vacuum at temperature extremes
   Equipment: Thermal vacuum chamber
   Procedure:
   1. Place system in TVAC chamber
   2. Pump down to <10^-5 Torr
   3. Cycle temperature: -40°C → +85°C (4 cycles)
   4. Run functional tests (Phase 4.1, 4.2) at each temperature
   5. Monitor for corona discharge or arcing (none expected at these voltages)
   Pass/Fail: System operates correctly in vacuum at all temperatures

Test 6.3: Burn-in (Accelerated Life Testing)
   Objective: Screen for early-life failures
   Procedure:
   1. Operate system at +85°C ambient, full load, 168 hours (1 week)
   2. Cycle load every 1 hour (0% → 100% → 0%)
   3. Monitor for:
      - Drift in trip thresholds
      - False trips
      - Component failures
   4. Perform functional test (Phase 4) after burn-in
   Pass/Fail: No failures, trip thresholds remain within ±5%

TEST DOCUMENTATION:
-------------------
For each test, record:
- Test setup (schematic, equipment list, software version)
- Measured values (timestamp, voltage, current, timing)
- Pass/fail criteria
- Operator name, date, witness (for space qualification)
- Any anomalies or deviations

Create test report package with:
- Test plan (this document)
- Test procedures (detailed step-by-step)
- Test results (data tables, waveforms, photos)
- Failure analysis (if any)
- Qualification summary

================================================================================
8. FAILURE MODE & EFFECTS ANALYSIS (FMEA)
================================================================================

PURPOSE:
Identify potential failure modes in protection system and analyze impact on
mission-critical edge computer. Determine criticality and mitigation strategies.

SEVERITY SCALE:
1 = Minor (no impact on mission)
2 = Moderate (degraded operation, mission continues)
3 = Major (loss of protected rail, partial system failure)
4 = Critical (loss of entire system)
5 = Catastrophic (loss of spacecraft/mission)

OCCURRENCE SCALE:
1 = Remote (<0.01% per year)
2 = Low (0.01-0.1% per year)
3 = Moderate (0.1-1% per year)
4 = High (1-10% per year)
5 = Very high (>10% per year)

DETECTION SCALE:
1 = Always detected (built-in monitoring)
2 = High probability of detection (test reveals)
3 = Moderate (may be detected during operations)
4 = Low (unlikely to detect before failure)
5 = Cannot detect (latent failure)

RISK PRIORITY NUMBER (RPN) = Severity × Occurrence × Detection

FMEA TABLE:

┌────┬──────────────────────┬─────────────────┬─────────────────┬───┬───┬───┬────┬────────────────────┐
│ ID │ Component/Function   │ Failure Mode    │ Effect          │ S │ O │ D │RPN │ Mitigation         │
├────┼──────────────────────┼─────────────────┼─────────────────┼───┼───┼───┼────┼────────────────────┤
│ 1  │ Sense Resistor       │ Open circuit    │ No current      │ 3 │ 1 │ 1 │ 3  │ Use high-reliability│
│    │ (R_SENSE)            │                 │ sensing, FET    │   │   │   │    │ wirewound, 2× rated│
│    │                      │                 │ stays on,       │   │   │   │    │ power              │
│    │                      │                 │ no protection   │   │   │   │    │                    │
├────┼──────────────────────┼─────────────────┼─────────────────┼───┼───┼───┼────┼────────────────────┤
│ 2  │ Sense Resistor       │ Short circuit   │ No voltage      │ 3 │ 1 │ 2 │ 6  │ Kelvin connection  │
│    │                      │                 │ drop, no        │   │   │   │    │ allows detection   │
│    │                      │                 │ sensing         │   │   │   │    │ (V_SENSE = 0)      │
├────┼──────────────────────┼─────────────────┼─────────────────┼───┼───┼───┼────┼────────────────────┤
│ 3  │ Sense Resistor       │ Value drift     │ Incorrect trip  │ 2 │ 2 │ 3 │ 12 │ Use metal film or  │
│    │                      │ (+20% from TID) │ threshold       │   │   │   │    │ wirewound (stable) │
│    │                      │                 │ (false trip or  │   │   │   │    │ Periodic cal check │
│    │                      │                 │ late trip)      │   │   │   │    │                    │
├────┼──────────────────────┼─────────────────┼─────────────────┼───┼───┼───┼────┼────────────────────┤
│ 4  │ Op-Amp (OP07)        │ Latchup (SEL)   │ Loss of sense   │ 3 │ 2 │ 2 │ 12 │ Use rad-hard bipolar│
│    │                      │                 │ amplifier,      │   │   │   │    │ op-amp (OP07 is    │
│    │                      │                 │ no protection   │   │   │   │    │ latchup immune)    │
├────┼──────────────────────┼─────────────────┼─────────────────┼───┼───┼───┼────┼────────────────────┤
│ 5  │ Op-Amp               │ Offset drift    │ Inaccurate      │ 2 │ 3 │ 3 │ 18 │ Use low-drift part │
│    │                      │ (TID > 10 krad) │ current sensing │   │   │   │    │ (OP07), design     │
│    │                      │                 │ (±10-20%)       │   │   │   │    │ margin into thresh.│
├────┼──────────────────────┼─────────────────┼─────────────────┼───┼───┼───┼────┼────────────────────┤
│ 6  │ Op-Amp               │ Output stuck    │ Comparator      │ 3 │ 1 │ 2 │ 6  │ Use rad-hard part, │
│    │                      │ high/low        │ always trips or │   │   │   │    │ redundant sensing  │
│    │                      │                 │ never trips     │   │   │   │    │ (dual op-amps)     │
├────┼──────────────────────┼─────────────────┼─────────────────┼───┼───┼───┼────┼────────────────────┤
│ 7  │ Comparator (LM139)   │ False trip      │ Spurious        │ 2 │ 2 │ 1 │ 4  │ Add hysteresis,    │
│    │                      │ (noise)         │ shutdown,       │   │   │   │    │ filter V_AMP signal│
│    │                      │                 │ system restarts │   │   │   │    │                    │
├────┼──────────────────────┼─────────────────┼─────────────────┼───┼───┼───┼────┼────────────────────┤
│ 8  │ Comparator           │ No trip (stuck  │ Load not        │ 4 │ 1 │ 3 │ 12 │ Redundant comparator│
│    │                      │ output low)     │ isolated during │   │   │   │    │ (dual threshold)   │
│    │                      │                 │ latchup → DAMAGE│   │   │   │    │                    │
├────┼──────────────────────┼─────────────────┼─────────────────┼───┼───┼───┼────┼────────────────────┤
│ 9  │ Comparator           │ Slow response   │ Delayed trip,   │ 3 │ 2 │ 2 │ 12 │ Use fast comparator│
│    │                      │ (>10µs)         │ possible load   │   │   │   │    │ (LM139 typ 300ns)  │
│    │                      │                 │ damage          │   │   │   │    │                    │
├────┼──────────────────────┼─────────────────┼─────────────────┼───┼───┼───┼────┼────────────────────┤
│ 10 │ D Flip-Flop (CD4013) │ SEU (bit flip)  │ Spurious fault  │ 2 │ 3 │ 1 │ 6  │ CMOS CD4000 series │
│    │                      │                 │ latch or clear  │   │   │   │    │ has low SEU rate   │
│    │                      │                 │                 │   │   │   │    │ (~10^-10/bit-day)  │
├────┼──────────────────────┼─────────────────┼─────────────────┼───┼───┼───┼────┼────────────────────┤
│ 11 │ D Flip-Flop          │ Latchup (SEL)   │ Loss of latch   │ 3 │ 1 │ 2 │ 6  │ Use rad-hard CMOS  │
│    │                      │                 │ function, no    │   │   │   │    │ (CD4000/883 series)│
│    │                      │                 │ fault memory    │   │   │   │    │                    │
├────┼──────────────────────┼─────────────────┼─────────────────┼───┼───┼───┼────┼────────────────────┤
│ 12 │ P-FET MOSFET (Q1)    │ Gate oxide      │ FET always on   │ 4 │ 1 │ 3 │ 12 │ Use rad-hard FET   │
│    │                      │ rupture (SEGR)  │ (shorted), no   │   │   │   │    │ rated SEGR immune  │
│    │                      │                 │ isolation → DAM.│   │   │   │    │ (IRHLUC7970Z4)     │
├────┼──────────────────────┼─────────────────┼─────────────────┼───┼───┼───┼────┼────────────────────┤
│ 13 │ P-FET MOSFET         │ Single Event    │ FET destroyed,  │ 4 │ 1 │ 3 │ 12 │ Use SEB-immune FET │
│    │                      │ Burnout (SEB)   │ load not        │   │   │   │    │ (rated >43 MeV·cm²)│
│    │                      │                 │ protected       │   │   │   │    │                    │
├────┼──────────────────────┼─────────────────┼─────────────────┼───┼───┼───┼────┼────────────────────┤
│ 14 │ P-FET MOSFET         │ RDS(on) increase│ Voltage drop,   │ 2 │ 3 │ 2 │ 12 │ Derate FET (use    │
│    │                      │ (TID > 10 krad) │ heat dissipation│   │   │   │    │ 50% of rated specs)│
│    │                      │                 │ increases       │   │   │   │    │                    │
├────┼──────────────────────┼─────────────────┼─────────────────┼───┼───┼───┼────┼────────────────────┤
│ 15 │ P-FET MOSFET         │ Stuck on (gate  │ Cannot isolate  │ 4 │ 1 │ 2 │ 8  │ Add series diode or│
│    │                      │ shorted to      │ load, latchup   │   │   │   │    │ backup FET in series│
│    │                      │ source)         │ continues → DAM.│   │   │   │    │                    │
├────┼──────────────────────┼─────────────────┼─────────────────┼───┼───┼───┼────┼────────────────────┤
│ 16 │ LM555 Timer          │ Timing drift    │ Retry delay off │ 1 │ 2 │ 3 │ 6  │ Use precision R/C, │
│    │                      │ (±20%)          │ (80-120ms)      │   │   │   │    │ acceptable for app │
├────┼──────────────────────┼─────────────────┼─────────────────┼───┼───┼───┼────┼────────────────────┤
│ 17 │ LM555 Timer          │ No output pulse │ No retry, system│ 3 │ 1 │ 2 │ 6  │ Use rad-hard 555   │
│    │                      │                 │ latches off on  │   │   │   │    │ (LM555/883)        │
│    │                      │                 │ first fault     │   │   │   │    │                    │
├────┼──────────────────────┼─────────────────┼─────────────────┼───┼───┼───┼────┼────────────────────┤
│ 18 │ CD4017 Counter       │ SEU (count error│ Incorrect retry │ 2 │ 2 │ 2 │ 8  │ Acceptable (CMOS   │
│    │                      │ ±1)             │ count (4 or 6   │   │   │   │    │ SEU rate low)      │
│    │                      │                 │ instead of 5)   │   │   │   │    │                    │
├────┼──────────────────────┼─────────────────┼─────────────────┼───┼───┼───┼────┼────────────────────┤
│ 19 │ CD4072 OR Gate       │ Stuck output    │ GLOBAL_FAULT    │ 3 │ 1 │ 2 │ 6  │ Use rad-hard CMOS, │
│    │                      │ low             │ never trips,    │   │   │   │    │ redundant OR path  │
│    │                      │                 │ no shutdown     │   │   │   │    │                    │
├────┼──────────────────────┼─────────────────┼─────────────────┼───┼───┼───┼────┼────────────────────┤
│ 20 │ CD4081 AND Gate      │ Stuck output    │ ENABLE_GLOBAL   │ 3 │ 1 │ 2 │ 6  │ Use rad-hard CMOS  │
│    │                      │ low             │ never enables,  │   │   │   │    │                    │
│    │                      │                 │ system dead     │   │   │   │    │                    │
├────┼──────────────────────┼─────────────────┼─────────────────┼───┼───┼───┼────┼────────────────────┤
│ 21 │ Power Supply (5V bus)│ Loss of VDD     │ All protection  │ 5 │ 1 │ 1 │ 5  │ Redundant power    │
│    │ for logic ICs        │                 │ circuits fail,  │   │   │   │    │ supply, monitoring │
│    │                      │                 │ loads unprotect.│   │   │   │    │                    │
├────┼──────────────────────┼─────────────────┼─────────────────┼───┼───┼───┼────┼────────────────────┤
│ 22 │ PCB Trace            │ Open circuit    │ Loss of sense   │ 3 │ 1 │ 3 │ 9  │ Use wide traces,   │
│    │ (sense signal)       │ (crack from vib)│ signal, no      │   │   │   │    │ conformal coating, │
│    │                      │                 │ protection      │   │   │   │    │ inspect after vib. │
├────┼──────────────────────┼─────────────────┼─────────────────┼───┼───┼───┼────┼────────────────────┤
│ 23 │ PCB Trace            │ Short to ground │ False trip      │ 2 │ 1 │ 2 │ 4  │ Design clearances, │
│    │ (V_AMP or FAULT_n)   │                 │ (spurious       │   │   │   │    │ solder mask, insp. │
│    │                      │                 │ shutdown)       │   │   │   │    │                    │
├────┼──────────────────────┼─────────────────┼─────────────────┼───┼───┼───┼────┼────────────────────┤
│ 24 │ Solder Joint         │ Crack (thermal  │ Intermittent    │ 3 │ 2 │ 3 │ 18 │ Use J-lead/gullwing│
│    │ (BGA or lead)        │ cycling, vib)   │ connection,     │   │   │   │    │ packages, no BGA,  │
│    │                      │                 │ false trips     │   │   │   │    │ X-ray inspection   │
├────┼──────────────────────┼─────────────────┼─────────────────┼───┼───┼───┼────┼────────────────────┤
│ 25 │ Conformal Coating    │ Voids or        │ Conductive      │ 2 │ 2 │ 3 │ 12 │ Proper application,│
│    │                      │ delamination    │ whiskers grow,  │   │   │   │    │ vacuum bake-out,   │
│    │                      │                 │ shorts possible │   │   │   │    │ matte tin finish   │
└────┴──────────────────────┴─────────────────┴─────────────────┴───┴───┴───┴────┴────────────────────┘

CRITICAL FAILURE MODES (RPN > 15):
-----------------------------------

FM #5: Op-Amp Offset Drift (RPN = 18)
- Mitigation: Use OP07CP (ultra-low drift), calibrate trip thresholds with margin
- Monitoring: Periodic ground testing to verify threshold accuracy

FM #24: Solder Joint Cracking (RPN = 18)
- Mitigation: Avoid BGA packages, use leaded components when possible
- Testing: X-ray inspection after TVAC and vibration testing

FM #8: Comparator No-Trip (RPN = 12)
- Mitigation: Redundant comparator with slightly lower threshold as backup
- Monitoring: Built-in self-test (BIST) circuit to verify comparator function

SINGLE POINT FAILURES (NO MITIGATION):
---------------------------------------

1. P-FET Gate Oxide Rupture (FM #12)
   - Use SEGR-immune FET (IRHLUC7970Z4 rated to 75 MeV·cm²/mg)
   - Acceptable risk: <0.1% over 1 year mission

2. Sense Resistor Open Circuit (FM #1)
   - Use high-reliability wirewound resistor
   - Consider redundant sense path (dual resistors in parallel)
   - Acceptable risk: <0.01% over 1 year mission

3. Power Supply Loss (FM #21)
   - System-level redundancy (dual power supply for critical functions)
   - Outside scope of this protection system

DESIGN IMPROVEMENTS TO REDUCE RPN:
-----------------------------------

1. Add redundant sensing (dual sense resistors + dual op-amps)
   - Reduces RPN for FM #1, #4, #5 by factor of 10
   - Cost: +6 resistors, +6 op-amps (~$200)
   - Recommended for mission-critical applications

2. Add backup P-FET in series per rail
   - Reduces RPN for FM #15 by factor of 10
   - Cost: +6 FETs (~$300)
   - Recommended for highest reliability

3. Add Built-In Self-Test (BIST) circuit
   - Periodically injects known current to verify protection response
   - Detects failures in FM #2, #6, #8 before actual latchup event
   - Cost: +1 microcontroller + mux (~$100)
   - Recommended for long-duration missions (>1 year)

================================================================================
9. DESIGN VERIFICATION CHECKLIST
================================================================================

Before finalizing design and proceeding to fabrication, verify:

SCHEMATIC REVIEW:
☐ All component values calculated correctly (sense resistors, R/C timing)
☐ All power pins connected (VDD, GND on every IC)
☐ Decoupling capacitors present on every IC (0.1µF + 10µF)
☐ Gate drive resistors on all P-FETs (prevents ringing)
☐ Hysteresis on all comparators (prevents oscillation)
☐ Pull-up/pull-down resistors on all logic inputs (no floating pins)
☐ Reset circuitry functional (RESET pulse generator verified)
☐ Enable logic correct (Boolean algebra verified)
☐ Interconnections between 6 rails verified (FAULT_n to OR gate)
☐ Test points accessible for all critical signals

COMPONENT SELECTION:
☐ All ICs available in QML/QMLV grades (check lead time)
☐ Radiation tolerance verified (TID rating > 50 krad for all parts)
☐ P-FET rated for SEGR/SEB immunity (LET > 43 MeV·cm²/mg)
☐ Sense resistors power rating adequate (2× normal power dissipation)
☐ All passives suitable for space (ceramic C0G, metal film resistors)
☐ Alternate components identified (in case of obsolescence)
☐ BOM cost within budget ($1,000-2,500 target)

PCB LAYOUT:
☐ 4-wire Kelvin connection on all sense resistors
☐ Power trace widths adequate (>80 mils for 3A, derated for vacuum)
☐ Sense signal traces shielded from high-current paths
☐ Ground plane continuity verified (no splits under analog circuits)
☐ Decoupling capacitors <5mm from IC pins
☐ P-FET placement allows heatsinking (thermal vias under pad)
☐ Thermal analysis performed (worst-case power dissipation)
☐ Design rules verified (trace width, spacing, via size)
☐ Conformal coating clearances (mask off sense resistors)
☐ Test points accessible with spring-loaded probes

ANALYSIS & SIMULATION:
☐ Response time calculated (detection + isolation < 20µs)
☐ Power dissipation calculated (P-FET, sense resistor, op-amp)
☐ Worst-case trip threshold verified (component tolerance ±5%)
☐ Retry timing verified (100ms ±10%)
☐ Startup delay verified (300ms ±10%)
☐ Thermal cycling range verified (-40°C to +85°C)
☐ EMI/EMC compliance (if required, CISPR25 for conducted/radiated)

TESTING PREPARATION:
☐ Test procedures written (Phase 1-6)
☐ Test equipment identified and available
☐ Heavy ion beam facility scheduled (6-12 month lead time)
☐ Test fixtures designed (allow access to test points)
☐ Data acquisition system prepared (high-speed oscilloscope, DAQ)
☐ Pass/fail criteria defined for each test
☐ Failure analysis plan prepared (for any test failures)

DOCUMENTATION:
☐ Schematic finalized (PDF + CAD files)
☐ BOM generated (with part numbers, suppliers, lead times)
☐ PCB layout files exported (Gerber, drill files)
☐ Assembly drawings created (component placement, orientation)
☐ Test plan finalized (this document)
☐ FMEA completed (RPN calculated for all failure modes)
☐ Design review meeting scheduled (peer review)

FABRICATION READINESS:
☐ PCB vendor selected (space-qualified fabrication process)
☐ Assembly house selected (capable of QML/QMLV component handling)
☐ Component procurement started (long lead items ordered)
☐ Tooling prepared (stencils, fixtures)
☐ Quality control plan established (inspection, X-ray, functional test)
☐ Schedule prepared (fabrication → assembly → test → qualification)

================================================================================
END OF DOCUMENT
================================================================================

Document prepared by: Claude (Anthropic AI Assistant)
For: Space-Qualified Edge Computer Latchup Protection System
Application: LEO orbit, 1+ year mission, 10 krad/year TID environment
Design Philosophy: Hardware-only, interconnected shutdown, 5 retry attempts

NEXT STEPS:
1. Review this document with system engineer and peer reviewers
2. Finalize component selection (confirm QML/QMLV availability)
3. Generate detailed schematics in CAD tool (Altium, OrCAD, KiCAD)
4. Perform PCB layout following guidelines in Section 6
5. Order components (start with long-lead items: MOSFETs, QML ICs)
6. Fabricate PCB and assemble prototype
7. Execute test plan (Phases 1-6)
8. Perform radiation testing (heavy ion beam)
9. Qualify for flight

ESTIMATED TIMELINE:
- Design review: 2 weeks
- PCB layout: 4 weeks
- Fabrication: 4 weeks
- Assembly: 2 weeks
- Testing (Phase 1-5): 8 weeks
- Radiation testing: 2 weeks (plus facility scheduling)
- Qualification: 4 weeks
TOTAL: ~6 months (excluding component procurement lead time)

For questions or clarifications, refer to project knowledge base or consult
with radiation effects specialist.

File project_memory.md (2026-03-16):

# MacroSEL Protection System — Project Memory

_Last updated: March 2026. Merges online Claude web memory with local design documents._
_Authoritative local source: `AICRAFT_latchup_detect_recover.pdf` (formal doc v0.1) — supersedes all `.txt` design files._

---

## Purpose & Context

Bach is designing a radiation-hardened macro single-event latchup (macro-SEL) protection system for a space-qualified edge computer targeting Low Earth Orbit missions with a minimum 3-year operational requirement. The system protects COTS components (ARM Cortex-A72 CPUs, AI cores, DDR4 RAM, eMMC storage) built on advanced process nodes across six power rails.

**Core design philosophy:** Hardware-only, autonomous protection using discrete rad-tolerant components. Commercial eFuse ICs were evaluated and found inadequate for the current and voltage requirements — no single commercial IC meets all requirements (RHRPMICL1A, 3DPM0168 fail on voltage range, current rating, or response time), validating the discrete custom approach.

Bach collaborates with one PCB engineer. The project has a client-facing component with cost and timeline considerations.

---

## Design Evolution

| Version | Key Change |
|---|---|
| v1.0 | Initial: per-rail P-FET switches, 5 retries × 100ms, 6-input OR gate |
| v2.1 | RC snubber on gate driver, single master switch |
| v3.1 | IRHLUC7970Z4 FET (later found undersized), OP07 op-amps |
| v3.2 | BUP06CP038F-01 FET, LMP7704-SP quad op-amps, SN54SC logic |
| v3.3 | **Critical fix:** SR latch for fault memory; split 3.3V/5V power domains; fixed retry-reset flaw where timer reset when Buck #1 collapsed |
| v4.0 (txt) | OPA4H838-SEP; single 5V domain; wired-AND bus; 10ms blanking; 9 components |
| **v0.1 (PDF)** | **Formal design document — current authoritative source.** Added POR RC circuit, Q_dis analysis, per-rail gain/BW table, full response time breakdown. Response time: 3.64 µs. |

v3.x used per-rail P-FET switches and LMP7704-SP op-amps on a 3.3V supply. v4.0 is a fundamental redesign: single master P-channel MOSFET on the 5V upstream rail, wired-AND comparator bus, single 5V power domain.

---

## System Architecture

### Protected Power Rails
Trip threshold: **150% of rated current** on each rail.

| Rail | Voltage | Rated Current | Load | Shunt | Trip Current |
|---|---|---|---|---|---|
| 1 | 3.3V | 5A | AI Core #1 | 10 mΩ | 7.5A |
| 2 | 3.3V | 5A | AI Core #2 | 10 mΩ | 7.5A |
| 3 | 1.2V | 3A | CPU + DDR4 | 10 mΩ | 4.5A |
| 4 | 1.35V | 400mA | CPU | 50 mΩ | 0.6A |
| 5 | 1.8V | 2A | CPU + eMMC | 10 mΩ | 3.0A |
| 6 | 2.5V | 1A | CPU + DDR4 | 10 mΩ | 1.5A |

Rail 4 uses 50 mΩ (changed from 100 mΩ in v3.x, then from the initially proposed 10 mΩ in v4.0): a 10 mΩ shunt at 0.6A trip needs gain 167 → BW 59.9 kHz, rise time 5.84 µs. The 50 mΩ shunt drops gain to 33.3 → BW 300 kHz, rise time 1.16 µs (5× faster), with only 20 mV drop consuming 30% of the ±67.5 mV CPU rail tolerance budget.

### Signal Flow

**1. Shunt Resistor**
- Part: WSL2512R0100FEA, 10 mΩ ±1%, 2W, 2512 SMD, 4-wire Kelvin connection
- Note: consider ±0.1% tolerance for tighter threshold accuracy

**2. Difference Amplifier — Stage 1** (OPA4H838-SEP, 2× quad, TSSOP-14, powered from 5V_IN)
- Topology: 4-resistor difference amplifier. R1 = R3 = 10 kΩ (E96); R2 varies per rail
- Rp protection resistors removed in final design
- All rails target ~988 mV at trip (uniform V_ref simplifies comparator stage)
- OPA4H838-SEP differential input limit ±0.2V — protective diodes may conduct on transients. Mitigated by R1 = 10 kΩ limiting input current to 330 µA max (well within safe continuous rating)

| Rail | R2 | Gain | BW | Rise time (t_rise = 0.35/BW) |
|---|----|---|----|---|
| 1 | 133 kΩ | 13.18 | 759 kHz | 0.46 µs |
| 2 | 133 kΩ | 13.18 | 759 kHz | 0.46 µs |
| 3 | 221 kΩ | 21.90 | 457 kHz | 0.77 µs |
| 4 | 332 kΩ | 33.20 | 301 kHz | 1.16 µs |
| 5 | 332 kΩ | 33.20 | 301 kHz | 1.16 µs |
| 6 | 665 kΩ | 65.89 | 152 kHz | 2.30 µs |

**3. Voltage Reference** (V_ref ≈ 0.996 V)
- R_top = 40.2 kΩ, R_bot = 10 kΩ, from 5V_IN
- **Rails 1 & 2 share one divider** → 5 total V_ref dividers (not 6)
- 100 nF X7R 0402 decoupling cap at each V_ref node, within 2 mm of comparator IN+ pin (~40 Hz LPF, rejects supply noise)
- V_ref tracks supply linearly: ±5% supply variation shifts trip threshold ±7.5% of rated current (acceptable given 150% margin)

**4. Comparator Stage — Stage 2** (TLV1704-SEP, 2× quad, TSSOP-14, open-drain output, 5V supply)
- **IN+ = V_ref (non-inverting); IN- = V_AMP_n (inverting)**
- Normal: V_AMP_n < V_ref → output Hi-Z
- Fault: V_AMP_n > V_ref → output drives LOW
- Propagation delay: 560 ns typical
- No internal hysteresis — external hysteresis is an open item (see below)

**5. Wired-AND Bus**
- All 6 comparator open-drain outputs on one wire; single 10 kΩ pull-up to 5V_IN
- All Hi-Z → GLOBAL_FAULT = HIGH; any LOW → GLOBAL_FAULT = LOW
- During shutdown: V_AMP collapses → comparators release → bus returns HIGH (false "no fault") — this is the fundamental reason an SR latch is required rather than a direct comparator-to-gate connection

**6. Set Latch Logic** (SN54SC4T32-SEP OR gate)
- OR(GLOBAL_FAULT_L, BLANKING) → SET_L
- During blanking: BLANKING = HIGH forces SET_L = HIGH (inactive), masking inrush false faults

**7. Blanking Timer** (SN54SC6T17-SEP Schmitt, R_blank = 1 MΩ, C_blank = 10 nF)
- Triggered by AC-coupled rising edge of ENABLE_GLOBAL (at retry time, ~1 s — not at T=0)
- Capacitor acts as AC short at the edge, then discharges through R_blank over RC = 10 ms
- Window: 12.2 ms (min) to 18.0 ms (max), typ 15.3 ms
- V_initial ≈ 3.5 V (AC-coupled spike, not full 5V) — timing formula uses V_initial as starting point, decaying to zero

**8. SR Latch** (SN54SC4T00-SEP, 2× NAND gates, active-LOW SET_L / RESET_L)
- Fault: SET_L LOW → FAULT_LATCHED HIGH → ENABLE_GLOBAL LOW → FET off
- Holds state while 5V_IN present, even after all downstream rails collapse to 0V
- Power-on state is indeterminate → resolved by Power on Reset circuit (see below)

**9. Retry Timer** (SN54SC6T17-SEP Schmitt, R_timer = 1.0 MΩ, C_timer = 2.2 µF, τ = 2.2 s)
- Q_dis (JANSR2N3700UB NPN, R_lim_b = 10 kΩ, R_lim_c = 100 Ω) shorts C_timer during normal op
- Fault: ENABLE_GLOBAL LOW → Q_dis OFF → C_timer charges toward 5V
- RETRY_PULSE fires when C_timer crosses Schmitt V_T+: **0.56 s (min), 0.79 s (typ), 1.21 s (max)**
- Timing formula: t = RC × ln(VCC / (VCC − V_T+)) — capacitor charges *toward* rail (asymptote = VCC), contrast with blanking which decays *from* spike to zero
- RETRY_PULSE → inverter (U_INV) → RESET_L (active-LOW) → resets SR latch → retry

**10. Power on Reset** (C_por = 100 nF, R_por = 100 kΩ, RC = 10 ms)
- Couples 5V_IN rising edge → INIT_LATCH_STATE HIGH pulse → inverter → RESET_L LOW → latch reset to safe state
- Fallback: if supply has soft start (edge too slow to couple sufficient voltage spike), retry timer takes over after ~0.56–1.21 s automatically
- INIT_LATCH_STATE and RETRY_PULSE share OR gate → combined RESET_L via inverter

**11. Reset Logic** (SN54SC4T32-SEP OR gate, same IC as SET_L)
- OR(RETRY_PULSE, INIT_LATCH_STATE) → inverter → RESET_L

**12. Enable Logic**
- Single inverter gate: ENABLE_GLOBAL = NOT(FAULT_LATCHED)

**13. Gate Driver** (SN54SC6T14-SEP hex Schmitt inverter)
- ENABLE_GLOBAL HIGH → GATE_DRIVE LOW → Vgs = −5V → FET ON
- ENABLE_GLOBAL LOW → GATE_DRIVE HIGH → Vgs = 0V → FET OFF
- R1 = 10 kΩ pull-up to 5V (fail-safe: FET OFF if driver loses power)
- R2 = 100 Ω series gate resistor (limits dV/dt)
- C_GS = 2.5 nF → τ = R2 × C_GS = 250 ns
- Turn-on: ~128 ns to threshold; turn-off: ~229 ns to threshold; worst case (3τ): 750 ns
- R1 and C2 (AC snubber) are electrically in parallel at the gate node; C2 must be physically routed close to FET body, not back to power input — long traces add parasitic inductance that defeats snubber function

**14. Master FET** (BUP06CP038F-01, P-channel, DPAK/TO-252AA)
- V_DSS: −55V; I_D: −35A continuous, −140A pulsed; R_DS(on): 38 mΩ @ Vgs = −4.5V

### Total Fault Response Time: **3.64 µs**

| Stage | Delay |
|---|---|
| Amplifier rise (worst case, Rail 6) | 2.30 µs |
| Comparator propagation | 0.56 µs |
| Logic gates (OR + SR latch + inverter) | ~0.03 µs |
| P-FET turn-off (worst case 3τ) | 0.75 µs |

Dominant contributors: amplifier (Rail 6 has highest gain → lowest BW → slowest rise) and FET switching (~84% combined). Logic gates are negligible.

Note: the 10 ms rail collapse time (bulk capacitor discharge) is irrelevant to protection — the circuit has already acted within 3.64 µs.

### Power Domain

Single **5V_IN** domain — all protection circuits always powered from spacecraft bus regardless of downstream rail state. Total: ~6.5 mA @ 5V = **~33 mW** (0.13% of 25W system budget).

| Block | Current |
|---|---|
| 2× OPA4H838-SEP | 5.2 mA |
| 2× TLV1704-SEP | 0.3 mA |
| 4× SN54SC logic ICs | 0.1 mA |
| V_ref dividers (5×) | 0.5 mA |
| Wired-AND pull-up | 0.5 mA |

**Decoupling rule:** 100 nF X7R 0402 ceramic cap on every IC power pin, placed as close to package as possible.

OPA4H838-SEP at 5V_IN provides >1.7 V common-mode headroom above the 3.3V rails — eliminates the common-mode constraint that existed in v3.x (LMP7704-SP at 3.3V).

---

## Bill of Materials

| Ref | Part | Function | Qty |
|-----|---|---|-----|
| Q1 | BUP06CP038F-01 | Master P-FET | 1 |
| U_AMP_A/B | OPA4H838-SEP | Quad op-amp, current sense, TSSOP-14 | 2 |
| U_CMP_A/B | TLV1704-SEP | Quad comparator, open-drain, TSSOP-14 | 2 |
| U_LATCH | SN54SC4T00-SEP | Quad NAND (SR latch) | 1 |
| U_OR | SN54SC4T32-SEP | Quad OR (SET_L + RESET_L logic) | 1 |
| U_SCH | SN54SC6T17-SEP | Hex Schmitt trigger (blanking + retry timer) | 1 |
| U_INV | SN54SC6T14-SEP | Hex Schmitt inverter (gate driver + reset inversion) | 1 |
| Q_dis | JANSR2N3700UB | NPN transistor (retry timer capacitor discharge) | 1 |

U_INV gate usage: gate driver (1), RESET_L inversion of combined OR output (1) = **2 of 6 gates used — 4 gates spare.**
Note: RETRY_PULSE and INIT_LATCH_STATE are first combined by the OR gate (U_OR), then a single inverter drives RESET_L — not two separate inverters.

---

## Radiation Requirements

- Mission: LEO ~400 km, 3-year minimum, ~3–15 krad/year depending on shielding
- SN54SC series logic, TLV1704-SEP comparators: 30 krad TID RLAT, LET 43 MeV·cm²/mg
- **OPA4H838-SEP: 30 krad(Si) RLAT, LET 43 MeV·cm²/mg** _(not 100 krad — that figure was incorrect in earlier txt versions)_
- BUP06CP038F-01 master FET: 30–50 krad TID, LET 46 MeV·cm²/mg
- 30 krad provides comfortable margin for 3-year LEO mission

---

## Open Items

| Item | Status | Notes |
|---|---|---|
| Comparator hysteresis | **Open** | TLV1704-SEP has no internal hysteresis; external hysteresis needed for false-trip immunity on wired-AND bus |
| Q_dis qualification level | **Open** | JANSR2N3700UB (JANS-level) evaluated as drop-in for JANTXV2N2222A (JANTXV-level) — electrically equivalent; verify program quality plan requirements |
| OPA4H838-SEP package in docs | **Resolved** | TSSOP-14 confirmed (not CFP-14 as stated in v4.0 open items). Assembly notes, footprint, land pattern corrected |
| Retry pulse simplification | **Resolved in PDF** | RETRY_PULSE → inverter → RESET_L directly; RC differentiator (C_pulse + R_pull) removed as unnecessary |
| U_INV gate usage | **Resolved** | 2 of 6 gates used (gate driver + RESET_L); 4 spare |
| Power-on reset | **Resolved in PDF** | C_por = 100 nF + R_por = 100 kΩ RC approach implemented (replaces earlier pullup-on-Q proposal) |
| LTspice simulation | **Planned** | With component model substitutions for space-grade parts |
| Prototype functional testing | **Planned** | Consumer-grade equivalent components for logic/function verification across all 6 rails |

---

## Prototype Parts Assessment

For bench testing circuit logic and functionality. All 8 parts are usable.

| Prototype Part | Replaces (Space-Grade) | Verdict | Key Notes |
|---|---|---|---|
| IPD380P06NM | BUP06CP038F-01 | ✅ Use | Near-identical: VDS −60V, ID −35A, RDS(on) 38 mΩ, same D-PAK/TO-252 package, Ciss = 2500 pF matches design value |
| OPA4325 (OPA4325) | OPA4H838-SEP | ✅ Use | Same GBW (10 MHz), slew rate (5 V/µs), supply range, TSSOP-14. Higher offset (150 µV vs ±2.25 µV) acceptable for prototype |
| TLV1704 | TLV1704-SEP | ✅ Use | Same part family (commercial vs space-grade). Identical 560 ns propagation delay, open-drain output, TSSOP-14 |
| SN74HC00 (TSSOP-14) | SN54SC4T00-SEP | ✅ Use | Same quad 2-input NAND function, 2–6V supply |
| SN54HC32 (TSSOP-14) | SN54SC4T32-SEP | ✅ Use | Same quad 2-input OR function, 2–6V supply |
| SN74LV6T17 (TSSOP-14) | SN54SC6T17-SEP | ✅ Use | Schmitt thresholds at 5V nearly identical — computed retry delay 0.54–1.18 s (design: 0.56–1.21 s), blanking 11.8–18.8 ms (design: 12.2–18.0 ms). Within ~5% |
| SN74HC14 (TSSOP-14) | SN54SC6T14-SEP | ✅ Use | Only used for logic inversion (gate driver + RESET_L), not RC timing — threshold differences irrelevant |
| BCP56T1 (SOT-223) | JANSR2N3700UB (ceramic UB SMD) | ✅ Use | Both are SMD, **different footprints**: JANSR2N3700UB uses ceramic UB (~3×2.7 mm); BCP56T1 uses SOT-223 (~6.5×7 mm). Prototype PCB must use SOT-223 pads. hFE min 40 at 150 mA vs 100 for space-grade part — marginal at the ~50 mA discharge peak but acceptable for functional verification |

**U_INV (SN54SC6T14-SEP / prototype SN74HC14) gate usage:** 2 of 6 gates used — 4 spare.
- Gate 1: INVERT(ENABLE_GLOBAL) → GATE_DRIVE (P-FET gate driver)
- Gate 2: INVERT(OR output of RETRY_PULSE + INIT_LATCH_STATE) → RESET_L

RETRY_PULSE and INIT_LATCH_STATE are OR-combined first (U_OR), then a single inverter drives RESET_L — confirmed by functional diagram.

**JANSR2N3700UB package note:** The "UB" suffix designates a ceramic surface-mount package (Microchip/Microsemi), not through-hole. It is a surface-mount equivalent to the JEDEC 2N3700. The BCP56T1 (SOT-223) is also SMD but uses a different, larger footprint.

---

## Key Learnings & Principles

**Circuit topology drives math structure.** Timing formulas must reflect actual circuit topology — blanking uses V_initial (AC-coupled spike, ~3.5V) decaying to zero; retry uses Vcc as asymptote charging from 0V. Using the wrong reference voltage produces wrong results even if the formula looks similar.

**Passive RC networks cannot override actively driven nodes.** Power-on reset must act on a node the passive network can actually influence. The RC differentiator couples into RESET_L via an inverter — it does not try to pull an actively driven NAND gate output.

**Wired-AND bus requires SR latch.** When fault occurs and rails collapse, V_AMP drops to 0V, comparators release the bus, GLOBAL_FAULT returns HIGH — this false "no fault" condition would immediately re-enable the FET. The SR latch decouples fault memory from the sensing signal, holding the system off for the full ~1s retry period.

**Blanking fires at retry (~1s), not at power-on.** The AC-coupled edge-differentiator only fires on ENABLE_GLOBAL LOW→HIGH transitions, which occurs at retry time. Power-on sequencing relies on the POR circuit (or fallback retry delay), not the blanking timer.

**Physical routing matters for high-frequency components.** C2 snubber effectiveness depends on proximity to FET gate/source pads. Long PCB traces add parasitic inductance that defeats the snubber function regardless of component value.

**V_ref supply dependence is a known and accepted trade-off.** V_ref tracks 5V_IN linearly while V_AMP is supply-independent, so supply variation shifts trip threshold: ±5% supply → ±7.5% trip current variation. Acceptable given 150% nominal margin.

**Rail 6 dominates response time.** Highest gain (65.89×) → lowest BW (152 kHz) → slowest amplifier rise time (2.30 µs). This is the worst-case figure used in total system response time.

**Cross-checking against source documents is essential.** Multiple documented instances where Claude responses contained errors (pin designations, component ratings, version-specific data). Bach catches these by referencing the actual design document and expects explicit acknowledgment and correction, not hedged language. Errors to watch for: mixing v3.x and v4.0 specs, incorrect OPA4H838-SEP radiation figures (30 krad, not 100 krad).

---

## Approach & Patterns

- Bach actively cross-references Claude's technical claims against source documents and directly challenges errors, expecting explicit correction rather than hedged language.
- Design decisions are documented with written technical justifications that Bach drafts and submits for review — Claude's role includes identifying factual errors, logic errors, and imprecise language in those drafts.
- Analysis proceeds component by component and signal-path by signal-path, with careful attention to which design version is being discussed — v3.x and v4.0 data must not be mixed.
- Bach demonstrates strong circuit intuition and frequently arrives at correct conclusions independently, using Claude to verify reasoning and fill in derivations.

---

## Tools & Resources

- **Authoritative design doc:** `AICRAFT_latchup_detect_recover.pdf` (formal v0.1) — supersedes `MacroSEL_Protection_v4_0_FINAL.txt`
- **Diagrams:** `latchup_detect_recover.drawio` (source) + `latchup_detect_recover-*.drawio.png` (exports per sub-block)
- **Datasheets:** `./latchup_v4.0/` (space-grade parts); `./latchup_v4.0/prototype_commercial_parts/` (commercial equivalents for prototyping)
- **Application notes:** `snoaa71.pdf` (space-grade 3-op-amp instrumentation amplifier circuit), `01332b.pdf` (current sensing fundamentals)
- **Simulation:** LTspice (planned, with component model substitutions)
- **Key components:** OPA4H838-SEP, TLV1704-SEP, SN54SC4T00-SEP, SN54SC6T17-SEP, SN54SC6T14-SEP, BUP06CP038F-01, JANSR2N3700UB, WSL2512R0100FEA shunt resistors

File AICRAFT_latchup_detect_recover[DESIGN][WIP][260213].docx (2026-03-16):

Macro-SEL Protection System

Version 0.1

Radiation-Tolerant Latch-up Detection and Recovery

Edge Computer for LEO Orbit

3-Year Minimum Mission Requirement

February 2026

Table of Contents

# Part 1: Macro-SEL Protection Design Overview

## 1. Introduction

This document describes the Macro-SEL (macro single-event latch-up) protection system for a space-qualified edge computer designed for Low Earth Orbit (LEO) missions with a minimum 3-year operational requirement.

The system protects ARM Cortex-A72 CPUs, AI cores, DDR4 RAM, and eMMC storage built on advanced process nodes using commercial off-the-shelf (COTS) components rather than radiation-hardened alternatives.

## 2. System Architecture

### 2.1 Protection Strategy

The system employs a hardware-only autonomous protection approach:

• One master P-channel MOSFET (high-side, 5V input rail)

• Six independent current-sensing channels (one per downstream rail)

• Wired-AND comparator bus (any fault triggers global fault)

• Hardware-only infinite retry: ~1 second off between attempts

• 10ms blanking window after FET turn-on (masks inrush)

• SR latch maintains fault state during power loss

## 3. Power Budget

### 3.1 Input Power

5V @ 5A maximum from the power source (25W total system budget)

### 3.2 Protected Rails

Rail | Voltage | Current | Load | Shunt | Trip Threshold
1 | 3.3V | 5A | AI Core 1 | 10 mΩ | 7.5A (150%)
2 | 3.3V | 5A | AI Core 2 | 10 mΩ | 7.5A (150%)
3 | 1.2V | 3A | CPU + DDR4 | 10 mΩ | 4.5A (150%)
4 | 1.35V | 0.4A | CPU | 50 mΩ | 0.6A (150%)
5 | 1.8V | 2A | CPU + eMMC | 10 mΩ | 3.0A (150%)
6 | 2.5V | 1A | CPU + DDR4 | 10 mΩ | 1.5A (150%)

Note: Rail 4 uses 50mΩ shunt (v4.0 change) to reduce voltage drop from 40mV to 20mV, saving critical margin for 1.35V rail.

### 3.3 Protection Circuit Power Consumption

All protection circuits powered from 5V_IN (single power domain):

• 2× OPA4H838-SEP op-amps: 5.2 mA

• 2× TLV1704-SEP comparators: 0.3 mA

• 5× Logic ICs (SN54SC series): 0.1 mA

• V_ref dividers (5 total): 0.5 mA

• Wired-AND pull-up resistor: 0.5 mA

• Total: ~6.6 mA @ 5V = 33 mW (0.13% of system budget)

## 4. Major Components

### 4.1 Master Protection Switch

Q1: BUP06CP038F-01 P-channel MOSFET

• Package: DPAK (TO-252AA)

• V_DSS: -55V

• I_D: -35A continuous, -140A pulsed

• R_DS(on): 38 mΩ typ @ Vgs = -4.5V

• TID: 30-50 krad(Si)

• SEE LET: 46 MeV·cm²/mg

### 4.2 Op-Amps

U_AMP_A, U_AMP_B: OPA4H838-SEP (quad op-amp)

• Package: CFP-14 hermetic flatpack

• Supply: 2.5V - 5.5V (powered at 5V from 5V_IN)

• GBW: 10 MHz (4× improvement over LMP7704-SP)

• Slew rate: 5 V/µs (5× improvement)

• Input offset: ±2.25 µV (200× better than LMP7704-SP)

• Offset drift: ±0.005 µV/°C (zero-drift technology)

• Input CM range: -0.1V to 5.1V (excellent headroom for 3.3V rails)

• TID: 30 krad(Si) RLAT

• SEE LET: 43 MeV·cm²/mg

### 4.3 Comparators

U_CMP_A, U_CMP_B: TLV1704-SEP (quad comparator)

• Package: TSSOP-14

• Supply: 2.2V - 24V (powered at 5V from 5V_IN)

• Propagation delay: 560 ns typical

• Output type: Open-drain (critical for wired-AND operation)

• TID: 30 krad(Si) RLAT

• SEE LET: 43 MeV·cm²/mg

## 5. Wired-AND Architecture

The design employs a critical architectural simplification using open-drain comparator outputs in a wired-AND configuration.

### 5.1 Principle of Operation

All six comparator outputs are tied together to a single bus wire with one 10kΩ pull-up resistor to 5V. This creates an inherent AND function:

• When ALL comparators are Hi-Z (no faults): Bus pulled HIGH by resistor → GLOBAL_FAULT = HIGH

• When ANY comparator drives LOW (fault detected): Bus pulled to GND → GLOBAL_FAULT = LOW

## 6. Control Logic

### 6.1 Blanking Window (10ms Inrush Masking)

A critical feature to properly handle input capacitor charging inrush:

• Triggered by ENABLE_GLOBAL rising edge (when FET turns ON)

• Duration: 9.5ms - 15.5ms (RC timing with component variation)

• Implementation: 10nF capacitor + 1MΩ resistor + Schmitt trigger

• Function: Masks fault detection during inrush period

### 6.2 SR Latch (Fault State Memory)

Remembers fault occurrence even after rails collapse to 0V:

• IC: SN54SC4T00-SEP (quad 2-input NAND)

• Active-LOW inputs: SET_L and RESET_L

• Output: ENABLE GLOBAL (fault remembered)

• Critical function: Prevents immediate restart when rails collapse

### 6.3 Retry Timer

Holds system off for ~1 second after fault shutdown:

• RC circuit: 1.0MΩ + 2.2µF

• Delay range: 0.7s - 1.7s (component variation)

• Discharge transistor: Q_dis (JANSR2N3700UB NPN)

• Controlled by ENABLE_GLOBAL output

### 6.4 Enable Logic

Matches logic coming out of the latch to the logic driving P-MOSFET gate

• Just one inverter gate

## 7. Bill of Materials Summary

### 7.1 Active Components (9 ICs total)

Component | Part Number | Function | Qty
Q1 | BUP06CP038F-01 | Master P-FET | 1
U_AMP | OPA4H838-SEP | Quad op-amp | 2
U_CMP | TLV1704-SEP | Quad comparator | 2
U_LATCH | SN54SC4T00-SEP | Quad NAND (latch) | 1
U_OR | SN54SC4T32-SEP | Dual OR (blanking) | 1
U_SCH | SN54SC6T17-SEP | Hex Schmitt buffer | 1
U_INV | SN54SC6T14-SEP | Hex Schmitt inverter | 1
Q_dis | JANSR2N3700UB | NPN transistor | 1

## 8. Default power tree

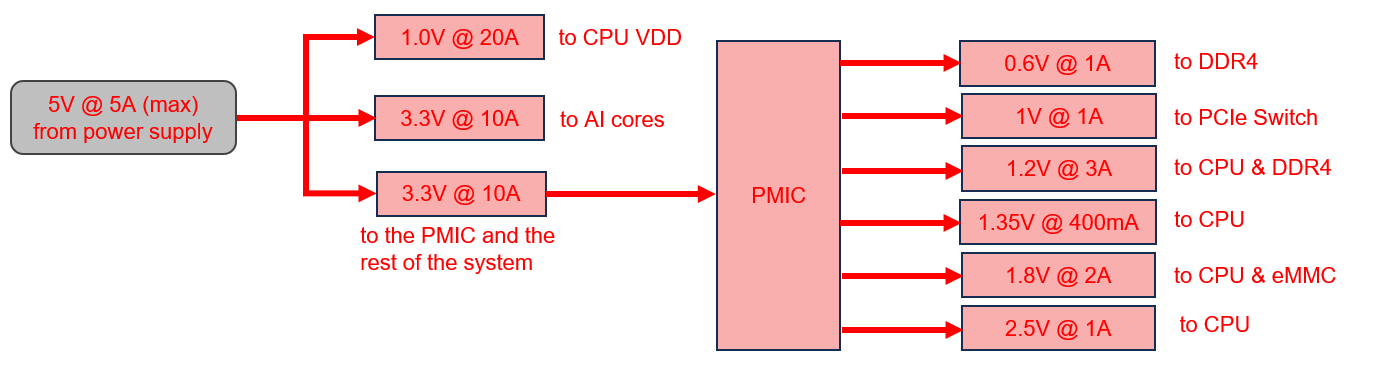
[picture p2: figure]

## 9. Proposed power tree

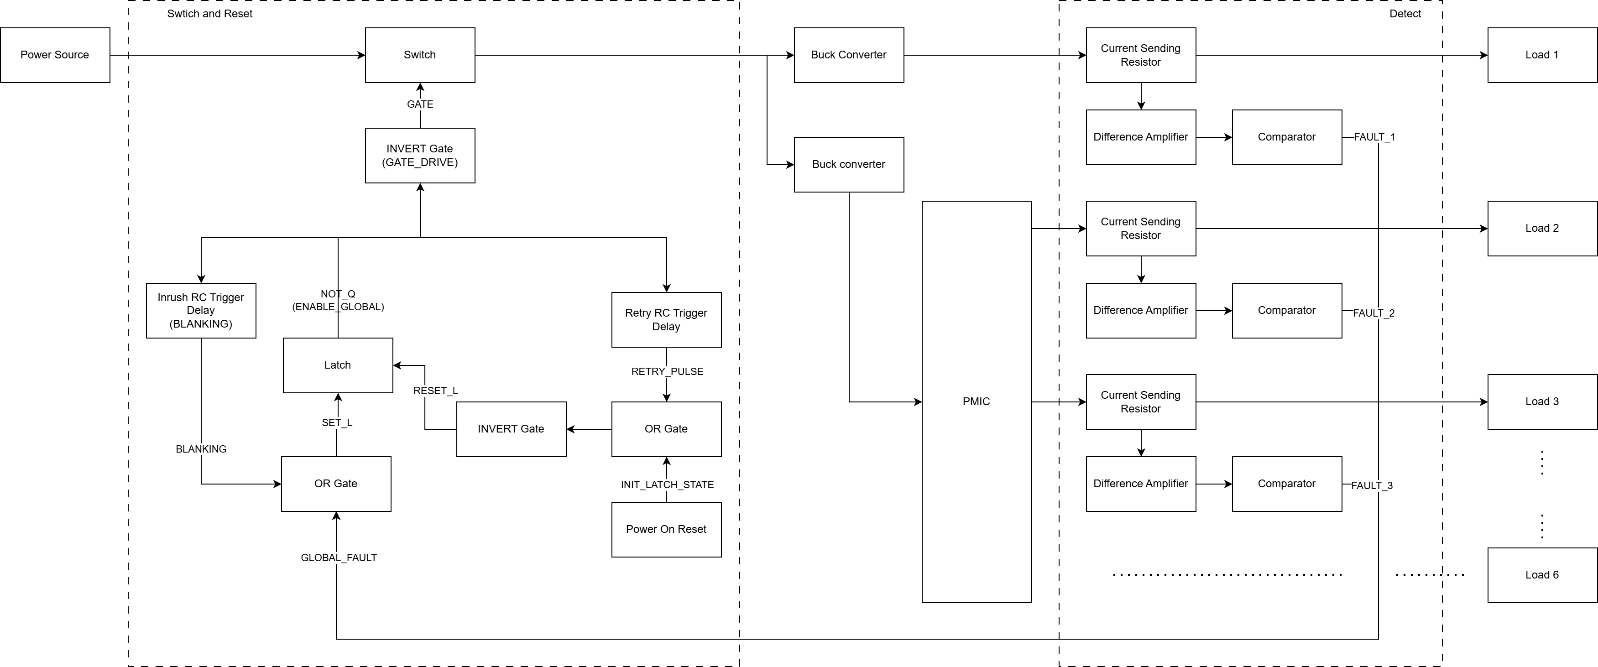
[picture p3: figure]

# Part 2: Complete Single Rail Diagram

This section provides a complete detailed diagram for one rail showing the entire signal path from power input to the P-FET gate driver.

Rail specifications:
• Voltage: 3.3V

• Rated current: 5A

• Trip threshold: 7.5A (150% of rated)

## 10. Current Sensing Stage

### 10.1 Shunt Resistor

The shunt resistor converts rail current into a measurable voltage drop:

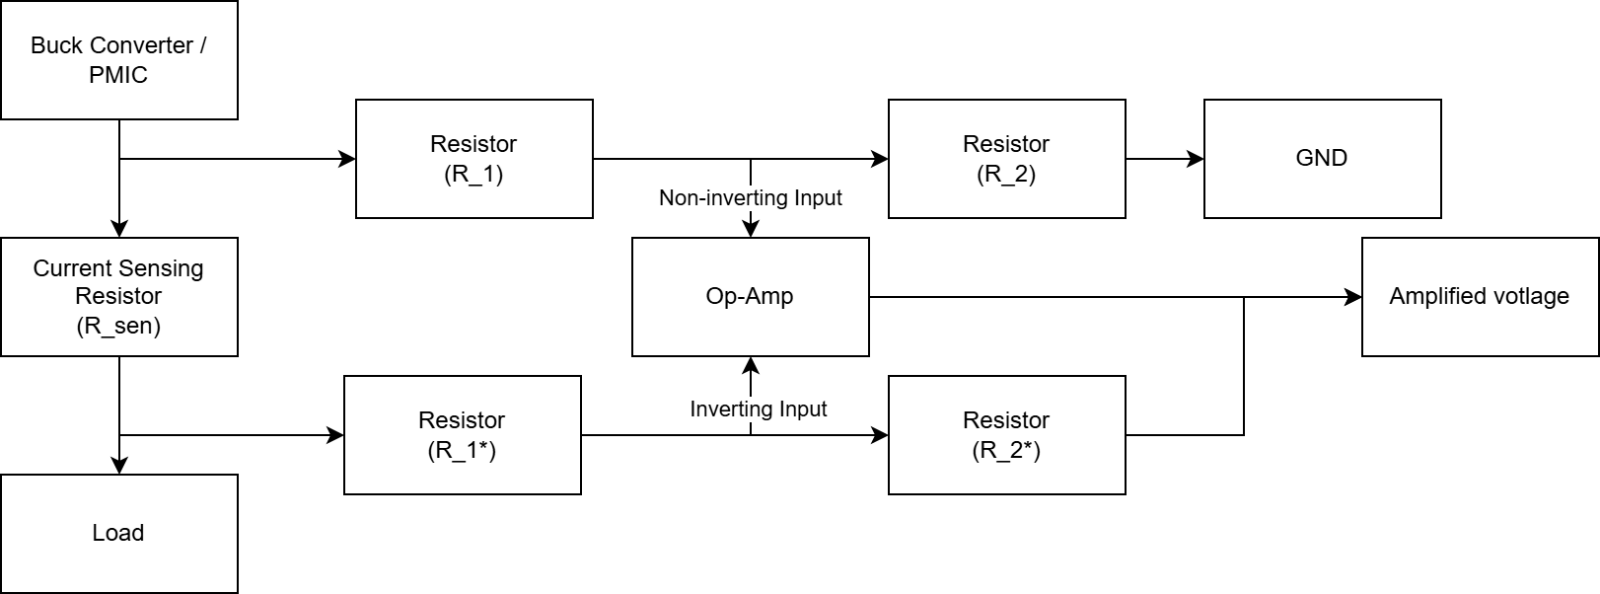
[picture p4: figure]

Component: WSL2512R0100FEA

- Resistance: 10 mΩ ± 1%
- Power rating: 2W
- Package: 2512 SMD with 4-wire Kelvin connection

Voltage drops:

• Normal (5A): V_drop = 5A × 10mΩ = 50mV (1.5% of 3.3V rail)

• Trip threshold (7.5A): V_drop = 7.5A × 10mΩ = 75mV

NOTE: consider using 0.1% tolerant resister

### 10.2 Difference Amplifier

4-resistor instrumentation amplifier topology converts small differential voltage into larger single-ended signal:

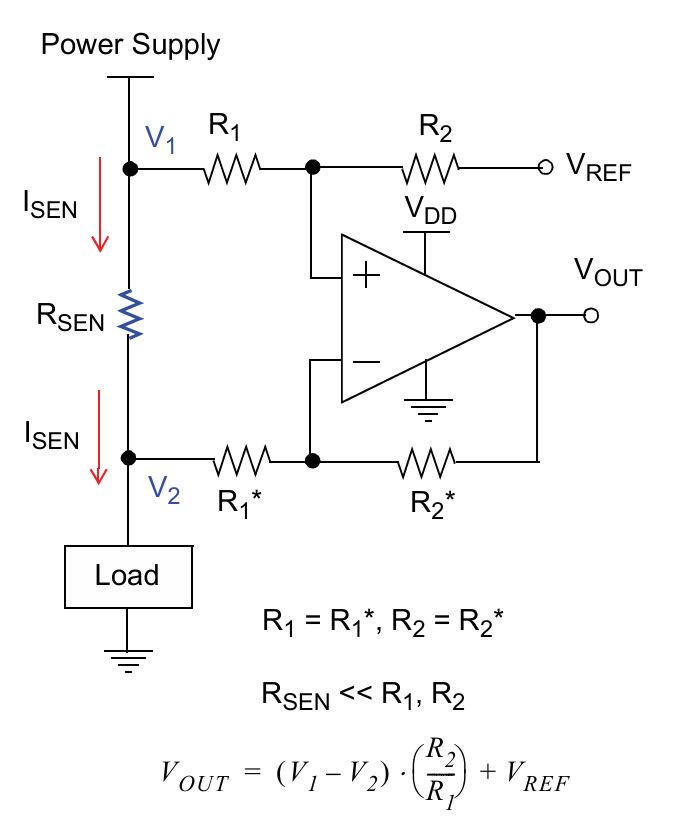
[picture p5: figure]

Component: OPA4H838-SEP

The main concern of using the op-amp is the rated differential voltage between its two inputs. The OPA4H838-SEP is rated at +-0.2V differential limit. The concern is that op-amp inputs might exceed +-0.2V during transients. In those cases, the protective diode inside the op-amp fails and start conducting. So, it’s imperative that the currents flowing into those inputs are limited to prevent melting the op-amp.

In the worst case, the voltage at the op-amp inputs is 3.3V and with R_1 is 10kOhm, the maximum current is only 330uA and the dissipating power is 1.1mW. That is negligible. The protective structures in op-amps are typically rated to handle several milliamps continuously, and the transient duration here is microseconds, so the thermal stress is even smaller than the steady-state calculation implies.

To simplify the design of the comparison circuitry, all amplified current sensing voltage will be compared to the same reference voltage which is set to roughly 1V. So, the gain between different rails needs to be set differently.

Rail | I_trip | R_sen | V_sen | Gain_ideal | R2 (selected) | Gain_actual | V_trip
1 | 7.5A | 10mΩ | 75mV | 13.33 | 133kΩ | 13.18 | 988mV
2 | 7.5A | 10mΩ | 75mV | 13.33 | 133kΩ | 13.18 | 988mV
3 | 4.5A | 10mΩ | 45mV | 22.22 | 221kΩ | 21.90 | 985mV
4 | 0.6A | 50mΩ | 30mV | 33.33 | 332kΩ | 32.90 | 987mV
5 | 3.0A | 10mΩ | 30mV | 33.33 | 332kΩ | 32.90 | 987mV
6 | 1.5A | 10mΩ | 15mV | 67.67 | 665kΩ | 65.89 | 988mV

Rail 4 supplies 1.35V to the CPU. The CPU is sensitive to supply voltage and requires that the delivered voltage stay within ±5% of nominal, which is a tolerance window of ±67.5mV. Between the PMIC output and the CPU, voltage is dropped by three series elements: the shunt resistor, PCB trace resistance, and connector resistance. Unlike the shunt resistor, trace and connector resistance can be minimised through careful PCB layout, so the shunt resistor's contribution should be kept as small as possible.

A 10mΩ shunt on a 0.6A trip current produces only 6mV at the sense input, requiring a difference amplifier gain of 167 to reach the 1.0V comparator threshold. With the OPA4H838-SEP's 10 MHz GBW, this gives a bandwidth of 59.9 kHz and a theoretical output rise time of 5.84µs, a significant delay for a circuit whose purpose is to detect and interrupt fast macro-SEL events.

A 50mΩ shunt on the same 0.4A rated current produces a 20mV voltage drop at the load, consuming 30% of the ±67.5mV tolerance budget and leaving 47.5mV for trace and connector resistance. The required gain drops to 33.3 theoretically, giving a bandwidth of 300 kHz and an output rise time of 1.17µs, a 5× improvement in detection speed over the 10mΩ option.

Bandwidth and response time:

• GBW = 10 MHz (OPA4H838-SEP)

• BW = GBW / Gain

• t_rise = 0.35 / BW

Rail | Gain_actual | BW | T_rise
1 | 13.18 | 759kHz | 0.46µs
2 | 13.18 | 759kHz | 0.46µs
3 | 21.90 | 457kHz | 0.77µs
4 | 32.90 | 304kHz | 1.15µs
5 | 32.90 | 304kHz | 1.15µs
6 | 65.89 | 152kHz | 2.3µs

The op-amps are powered directly from the power source, the always-on domain upstream of the master P-FET. This ensures the sensing and detection logic remains active and in a deterministic state throughout both shutdown and the recovery hold period.

## 11. Voltage Reference Generation

V_ref provides the threshold voltage for fault detection. Target is ~1.0V to match V_AMP at 150% current.

NOTE: Rails 1 & 2 share ONE V_ref divider (both are 3.3V/5A with identical trip points).

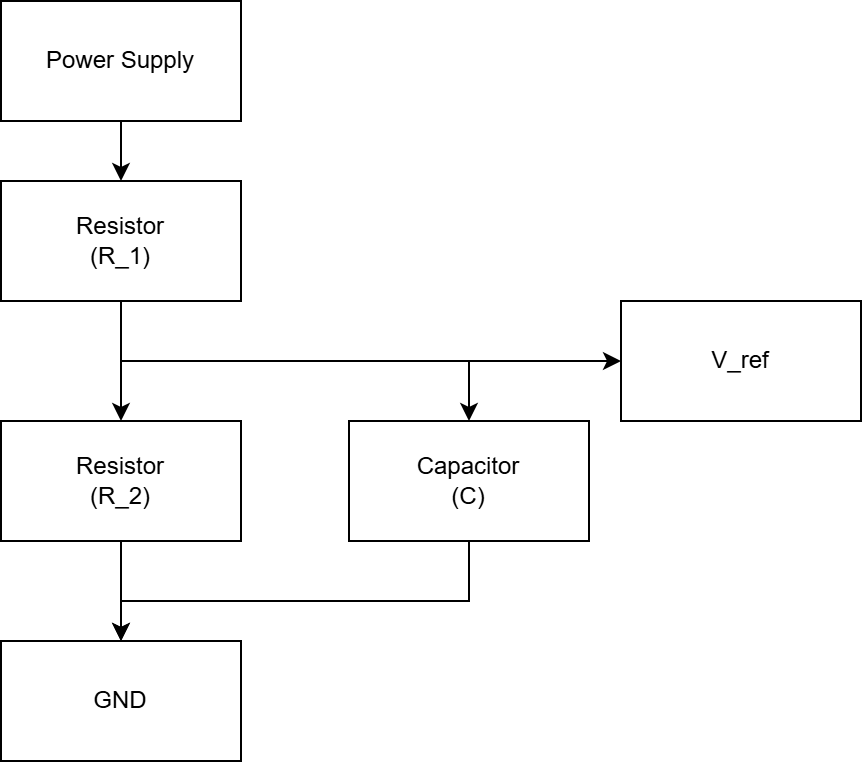
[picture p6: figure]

## 12. Comparator Stage

TLV1704-SEP comparator with open-drain output detects when amplified signal exceeds threshold:

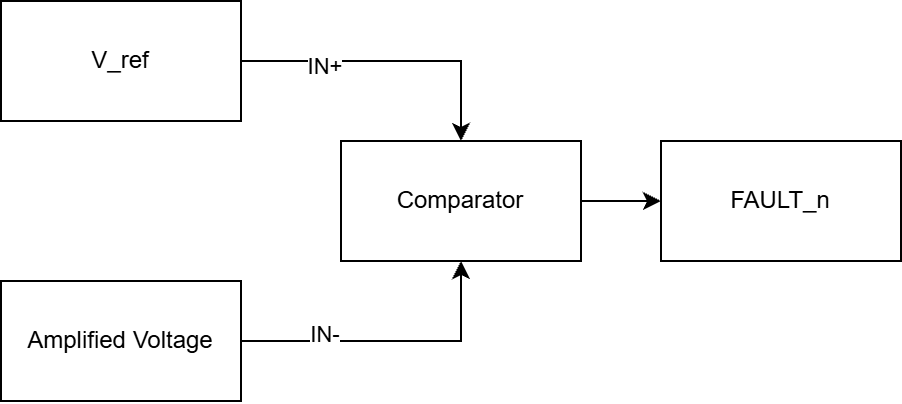
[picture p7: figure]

Comparator logic:

• IN+ = V_ref

• IN- = V_AMP_1 (variable, tracks rail current)

Operation:

• Normal: V_AMP_1 < V_ref → IN+ > IN- → Output Hi-Z

• Fault: V_AMP_1 > V_ref → IN+ < IN- → Output drives LOW

## 13. Wired-AND Bus

All 6 comparator outputs tied together with single 10kΩ pull-up resistor:

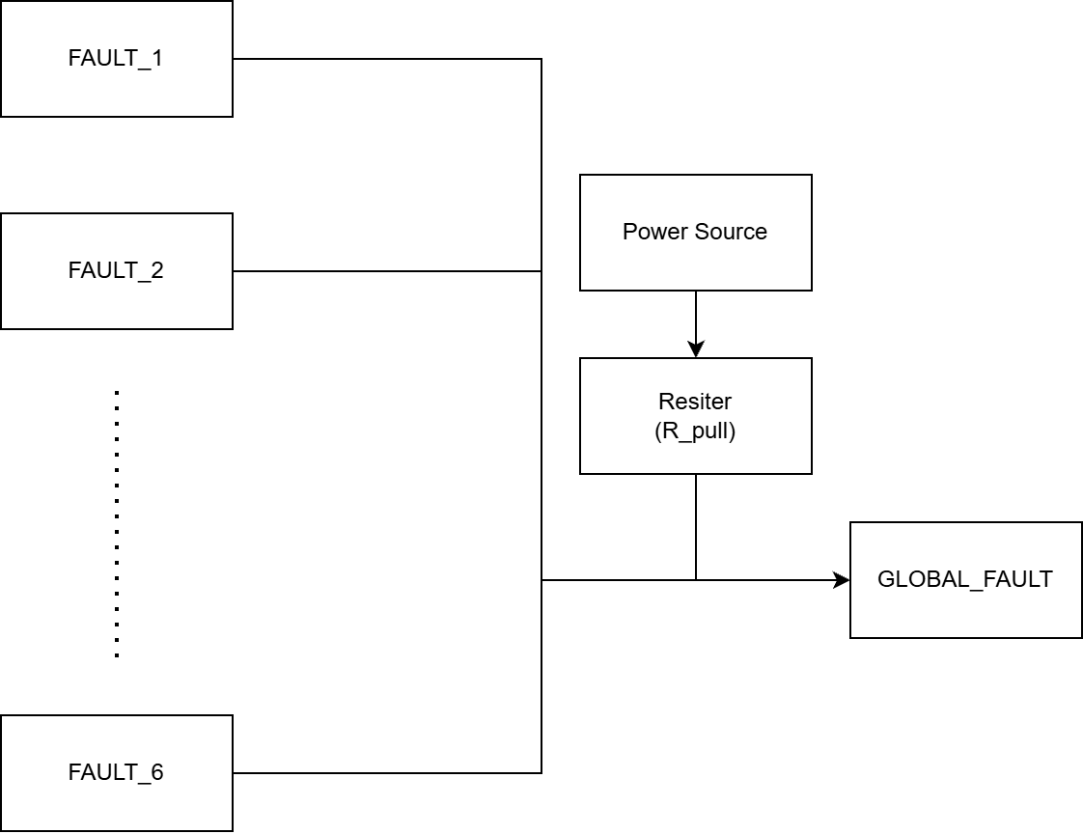
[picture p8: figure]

Bus signal states:

• ALL rails normal (all 6 comparators Hi-Z): Bus = HIGH (~5V)

• Rail 1 faults (comparator 1 drives LOW): Bus = LOW (~0V)

• Multiple rails fault: All share pull-down current, bus = LOW

• During shutdown (all V_AMP = 0V): Comparators Hi-Z, bus = HIGH (false indication, but SR latch remembers fault)

## 14. Blanking Gate

OR gate combines fault signal with blanking timer to mask faults during inrush:

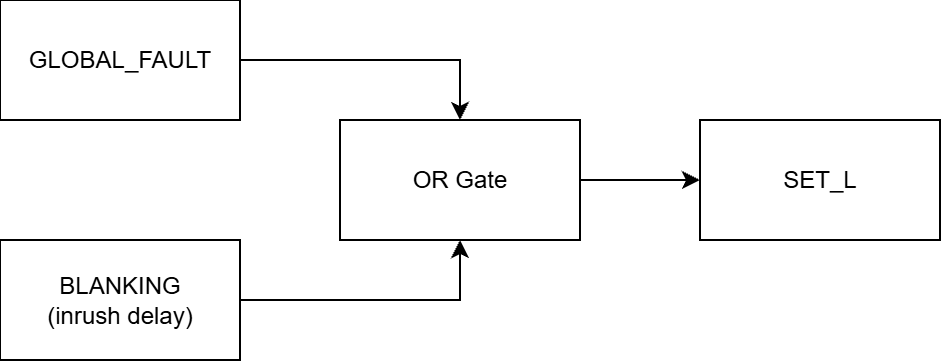
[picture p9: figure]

Truth table:

GLOBAL_FAULT | BLANKING | SET_L
HIGH | HIGH | HIGH (Startup: faults masked)
HIGH | LOW | HIGH (Normal: no fault)
LOW | HIGH | HIGH (Inrush fault: MASKED)
LOW | LOW | LOW (Real fault: trigger latch)

Critical function: During 10ms blanking window, even if inrush triggers GLOBAL_FAULT = LOW, the OR gate keeps SET_L = HIGH (inactive), preventing false shutdown.

## 15. Blanking Timer

Generates 10ms HIGH pulse starting when ENABLE_GLOBAL rises (FET turns ON):

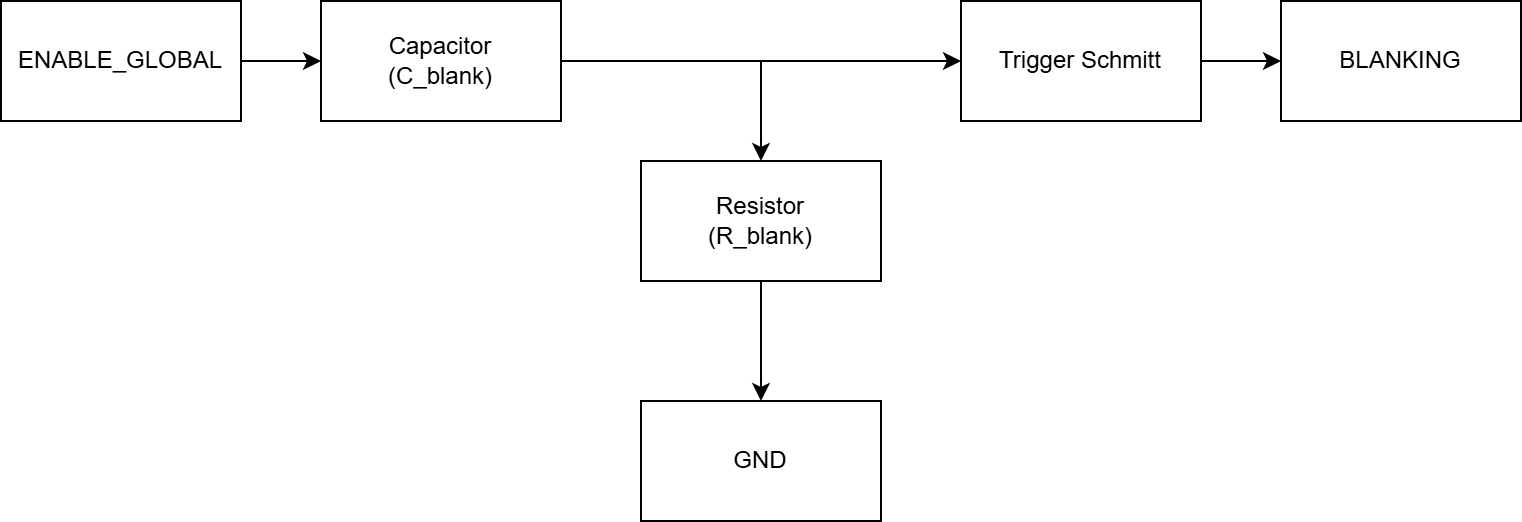
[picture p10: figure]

Operation:

- The Rising Edge (FET Turns ON): When ENABLE_GLOBAL transitions from LOW to HIGH, the fast-rising edge contains high-frequency AC components. The 10nF capacitor acts momentarily as a short circuit to this edge, coupling the voltage spike directly to Trigger Schmitt input.
- Triggering: Trigger Schmitt’s input instantly spikes high (around 3.5V). Because this is well above the Schmitt buffer's positive-going threshold V_T+, the buffer's output (BLANKING) snaps HIGH immediately.
- The Discharge Phase: Once ENABLE_GLOBAL settles at a steady 5V (DC), the capacitor blocks the DC current. The voltage at input of the Trigger Schmitt now discharges down to 0V through the 1 MΩ resistor. The RC time constant is 10ms (1 MΩ * 10nF).
- The Falling Edge (Window Closes): As the voltage at the input of the Trigger Schmitt decays, it eventually crosses the Schmitt trigger's negative-going threshold V_T-, roughly 1.06V). The buffer's output (BLANKING) snaps LOW, effectively ending the blanking window after approximately 9.5ms to 15.5ms.

When ENABLE_GLOBAL goes from HIGH to LOW (FET turns OFF), the capacitor couples that negative edge. However, Trigger Schmitt’s input is already resting at 0V. The negative spike has no effect on the Schmitt trigger's positive-logic output, so no false blanking pulse is generated during shutdown.

Logic Integration:

This active-HIGH BLANKING pulse is fed into an OR gate alongside the active-LOW GLOBAL_FAULT signal. During the ~10ms window, the HIGH BLANKING signal forces the OR gate's output (SET_L) to remain HIGH, completely overriding any LOW fault signals triggered by the inrush current.

## 16. SR Latch

Cross-coupled NAND gates remember fault state during power loss:

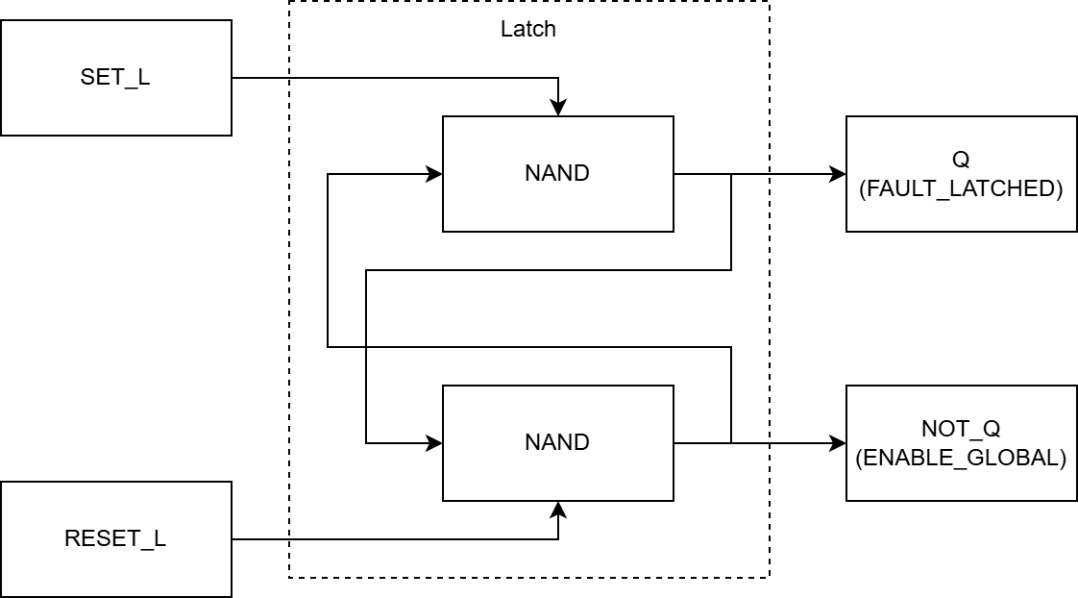
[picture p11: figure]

IC: SN54SC4T00-SEP (quad 2-input NAND), uses gates 1 and 2

Operation:

2 NAND gates make an active LOW SR latch

SET_L | RESET_L | Action | FAULT_LATCHED | ENABLE_GLOBAL
HIGH | HIGH | Hold (no change) | Previous state | Previous state
LOW | HIGH | SET (latch fault) | HIGH | LOW
HIGH | LOW | RESET (clear fault) | LOW | HIGH
LOW | LOW | Invalid (avoid) | Undefined | Undefined

Logic integration:

When rails collapse to 0V, GLOBAL_FAULT goes HIGH, but latch holds FAULT_LATCHED = HIGH or ENABLE_GLOBAL = LOW, keeping system off until retry timer resets it.

## 17. Retry Timer

Holds system off for roughly 1 second after fault shutdown then the system turns on:

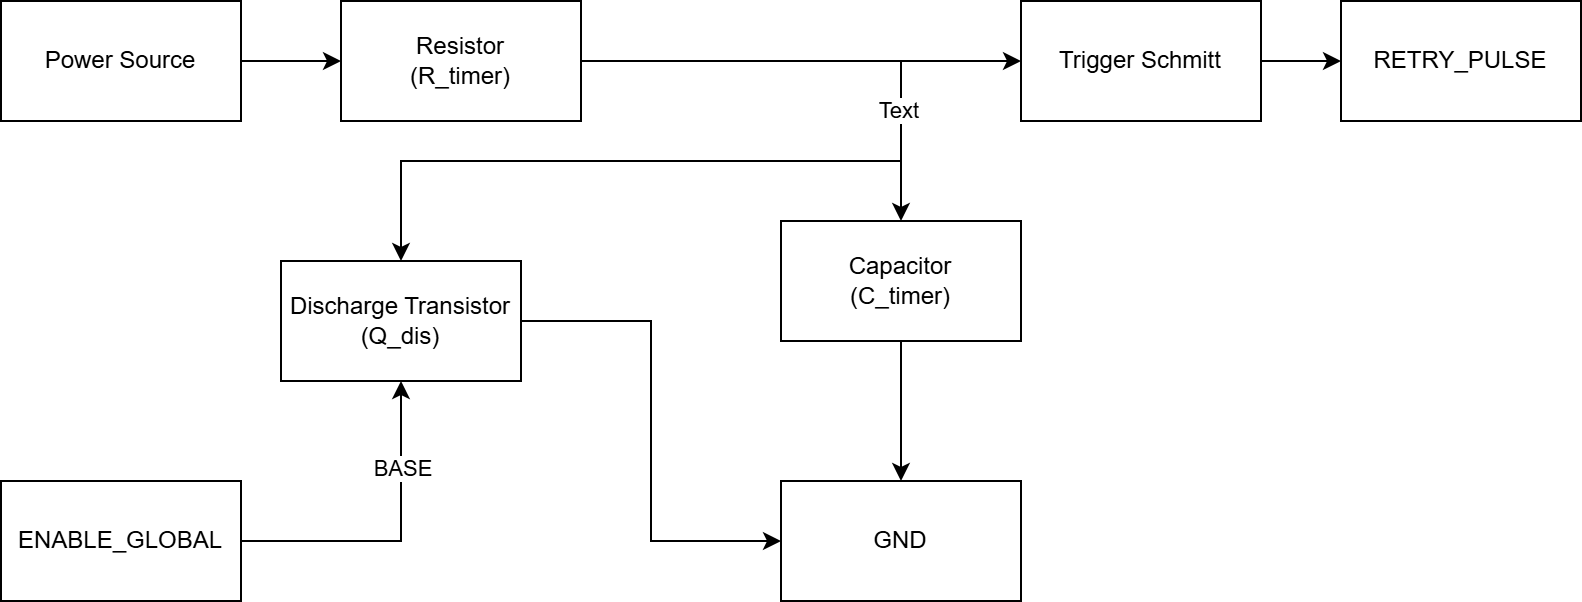
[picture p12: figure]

Operation:

The RC Timing

The idea of this delay is a simple analog RC timing circuit, controlled by the logic state of the system.

- The Timer: Formed by R_timer (1.0 MΩ) and C_timer (2.2 µF) making a RC differentiator.
- The Switch: Q_dis (the NPN transistor) acts as an electronic valve that either holds the timer at zero or lets it run.
- The Reader: The Trigger Schmitt buffer (SN54SC6T17-SEP) monitors the capacitor's voltage and snaps cleanly to a HIGH logic state only when a specific voltage threshold is reached.

Phase 1: Normal Operation (System is running)

During normal operation, the timer should be disabled so it isn't constantly trying to reset the system.

- ENABLE_GLOBAL is HIGH (no fault).
- This HIGH signal hits the base of the discharge transistor (Q_dis), turning it ON.
- The transistor shorts the capacitor directly to GND. The voltage at the Schmitt trigger input stays clamped at 0V, keeping RETRY_PULSE LOW.

Phase 2: A Fault Occurs (The Delay Starts)

When a latch-up event is detected, the system shuts down and needs to wait for the latch-up current to dissipate before turning back on.

- ENABLE_GLOBAL snaps LOW.
- The LOW signal turns the discharge transistor OFF.
- With the short to ground removed, the 5V power source begins charging the 2.2uF capacitor through the 1.0MΩ resistor.
- The Math: the RC time constant is R_timer x C_timer = 2.2s. The voltage rises slowly along the RC charge curve.

Phase 3: The Threshold is Reached (The Retry)

- The Schmitt trigger is watching the rising voltage on the capacitor.
- Depending on the exact IC tolerances, its positive-going threshold V_T+ will be somewhere between 1.43V and 2.71V (typically 2.00V).
- It takes roughly 0.7 to 1.7 seconds for the charging capacitor to hit this voltage.
- The instant it crosses V_T+, the Schmitt trigger's output (RETRY_PULSE) snaps HIGH.

Logic Integration:

The RETRY_PULSE signal then passes through an INVERT gate before feeding into the RESET_L of the SR latch. This is because that the latch is active low.

- RETRY_PULSE (HIGH pulse) → Inverter → RESET_L (LOW pulse)
- SR latch sees LOW on RESET_L → resets to ENABLE_GLOBAL = HIGH

## 18. Power on Reset

Sets the initial state of the latch as when first powering on, the output of the latch is indeterministic, and the latch’s output is used to control the blanking window and the retry reset. In the ideal case, the ENABLE_GLOBAL should snap from LOW to HIGH, which turns on the FET, stops the retry circuit from restarting the system and triggers the blanking. If the ENABLE_GLOBAL stays LOW, the FET stays off, the system won’t turn on, however, since the ENABLE_GLOBAL is LOW, the retry reset starts charging and after roughly 1s, it will send the reset signal to the latch and let the system on.

For a reliable way to turn on the system, the Power on Reset circuitry will send a pulse to RESET_L of the latch to properly reset the latch every time power is first delivered to the system.

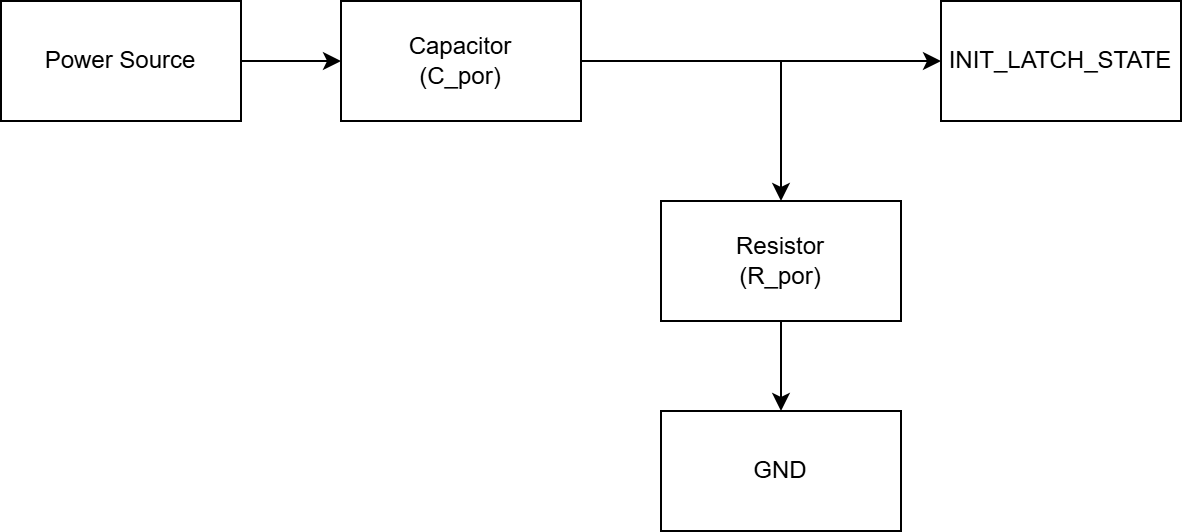
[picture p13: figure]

Operation:

- Before plugging in the system to the power source, INIT_LATCH_STATE = 0V.
- When power is connected and starts rising, the fast-rising edge contains high-frequency AC components. The 100nF capacitor acts momentarily as a short circuit to this edge, coupling the voltage spike directly. INIT_LATCH_STATE spikes HIGH.
- Once power settle, the capacitor blocks the DC current. 100nF C_por discharges through 100kΩ R_por, making INIT_LATCH_STATE decays to 0V
- The RC time constant is R_por x C_por = ~10ms (much longer than needed for latch reset)

Logic Integration:

The INIT_LATCH_STATE signal then passes through an INVERT gate before feeding into the RESET_L of the SR latch. This is because that the latch is active low.

- INIT_LATCH_STATE (HIGH pulse) → Inverter → RESET_L (LOW pulse)
- SR latch sees LOW on RESET_L → resets to ENABLE_GLOBAL = HIGH

## 19. Reset Logic

An OR gate to combine the 2 reset signals from the retry delay and the power on reset.

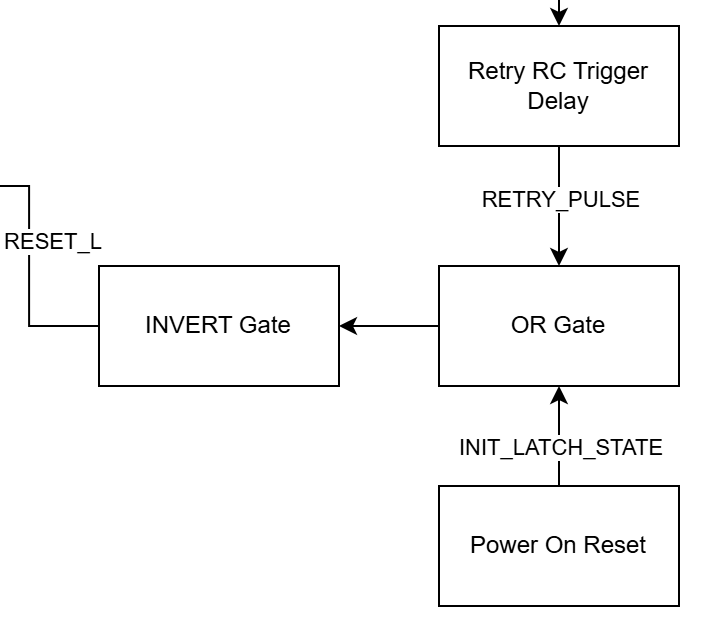
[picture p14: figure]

Operation:

RETRY_PULSE | INIT_LATCH_STATE | RESET_L
LOW (no fault) | LOW (stable power) | HIGH (work normal)
HIGH (turn on after fault) | LOW (stable power) | LOW (restart after fault)
LOW (no fault) | HIGH (first power up) | LOW (first power up)
HIGH (turn on after fault) | HIGH (first power up) | LOW (first power up)

Logic integration:

On power up, the latch gets reset and during that window, all the fault signals are masked, once power becomes stable, the power on reset circuitry is essentially disable. The masking window during first power up matches with the blanking window, so the logic is unchanged.
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

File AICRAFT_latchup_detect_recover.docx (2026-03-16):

Macro SEL Protection System

Version 0.1

Radiation-Tolerant Latch-up Detection and Recovery

Edge Computer for LEO Orbit

3-Year Mission Requirement

February 2026

Table of Contents

# 1. Introduction

This document describes the Macro SEL (macro single-event latch-up) protection system for a space-qualified edge computer designed for Low Earth Orbit (LEO) missions with a minimum 3-year operational requirement.
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

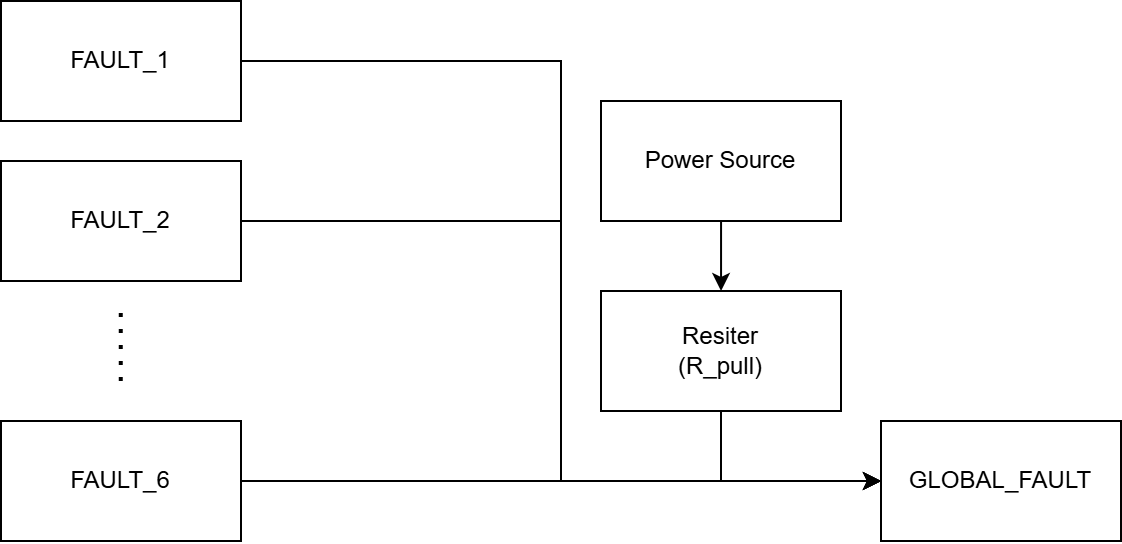
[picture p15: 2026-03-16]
latchup_detect_recover-Wired_AND_bus.drawio.png

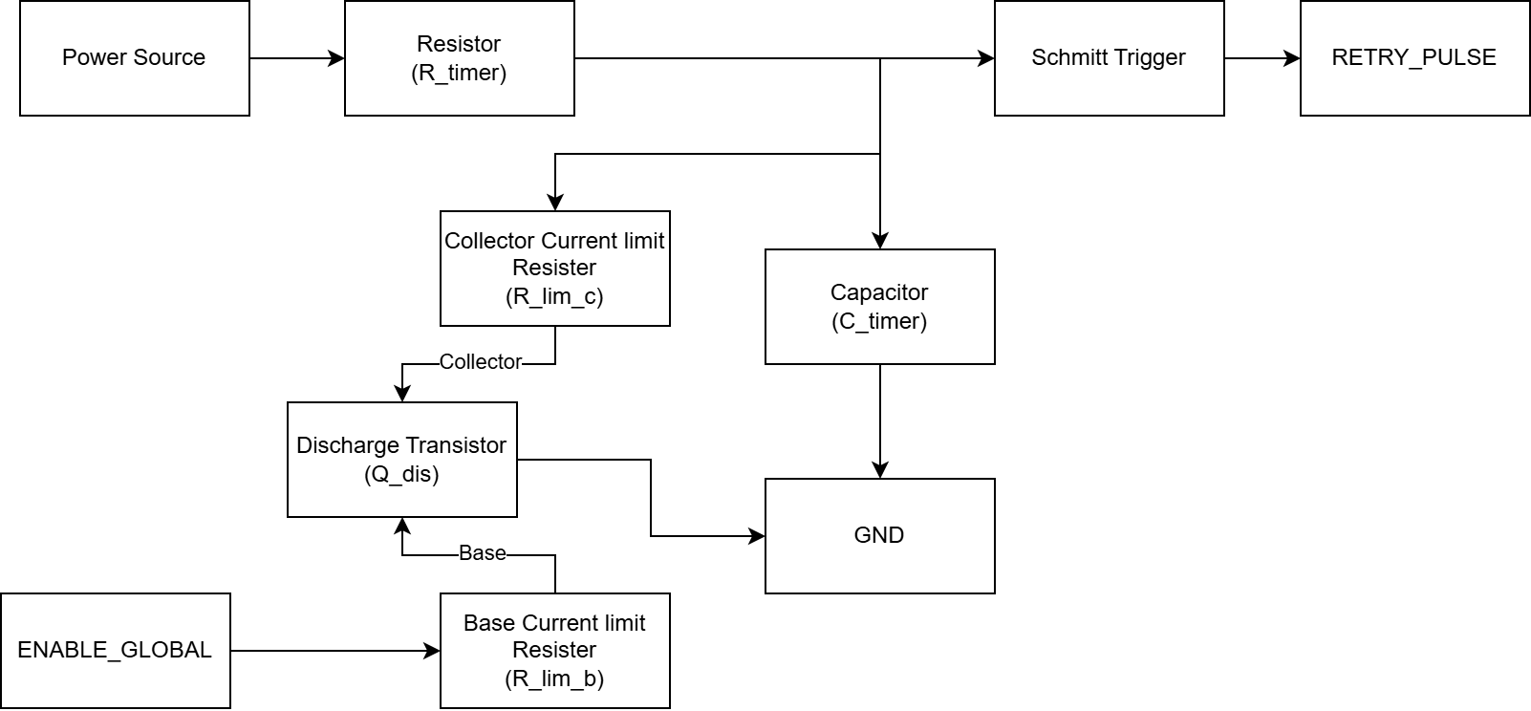
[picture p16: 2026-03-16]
latchup_detect_recover-delay_retry.drawio.png

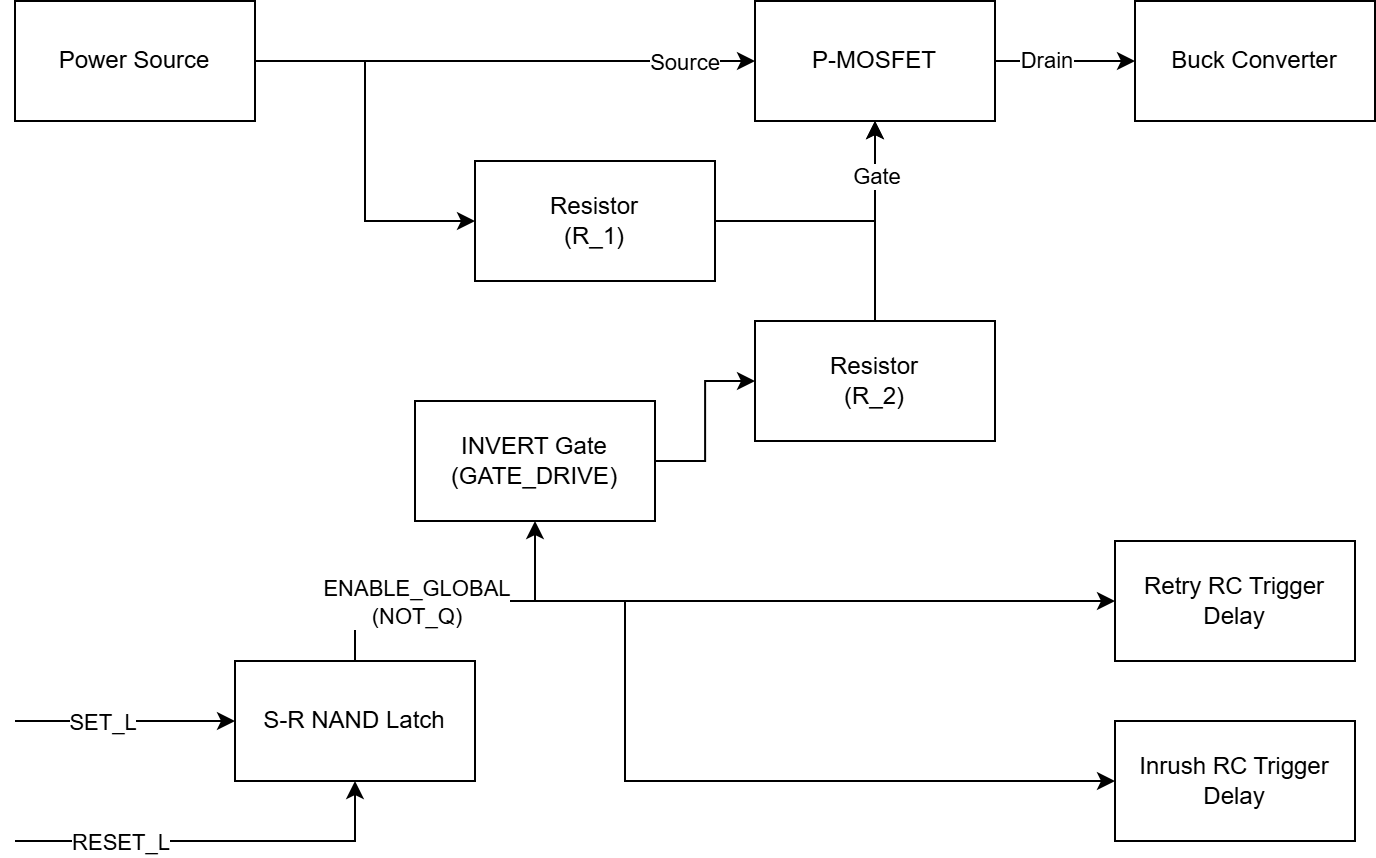
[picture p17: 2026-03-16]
latchup_detect_recover-gate_driver.drawio.png

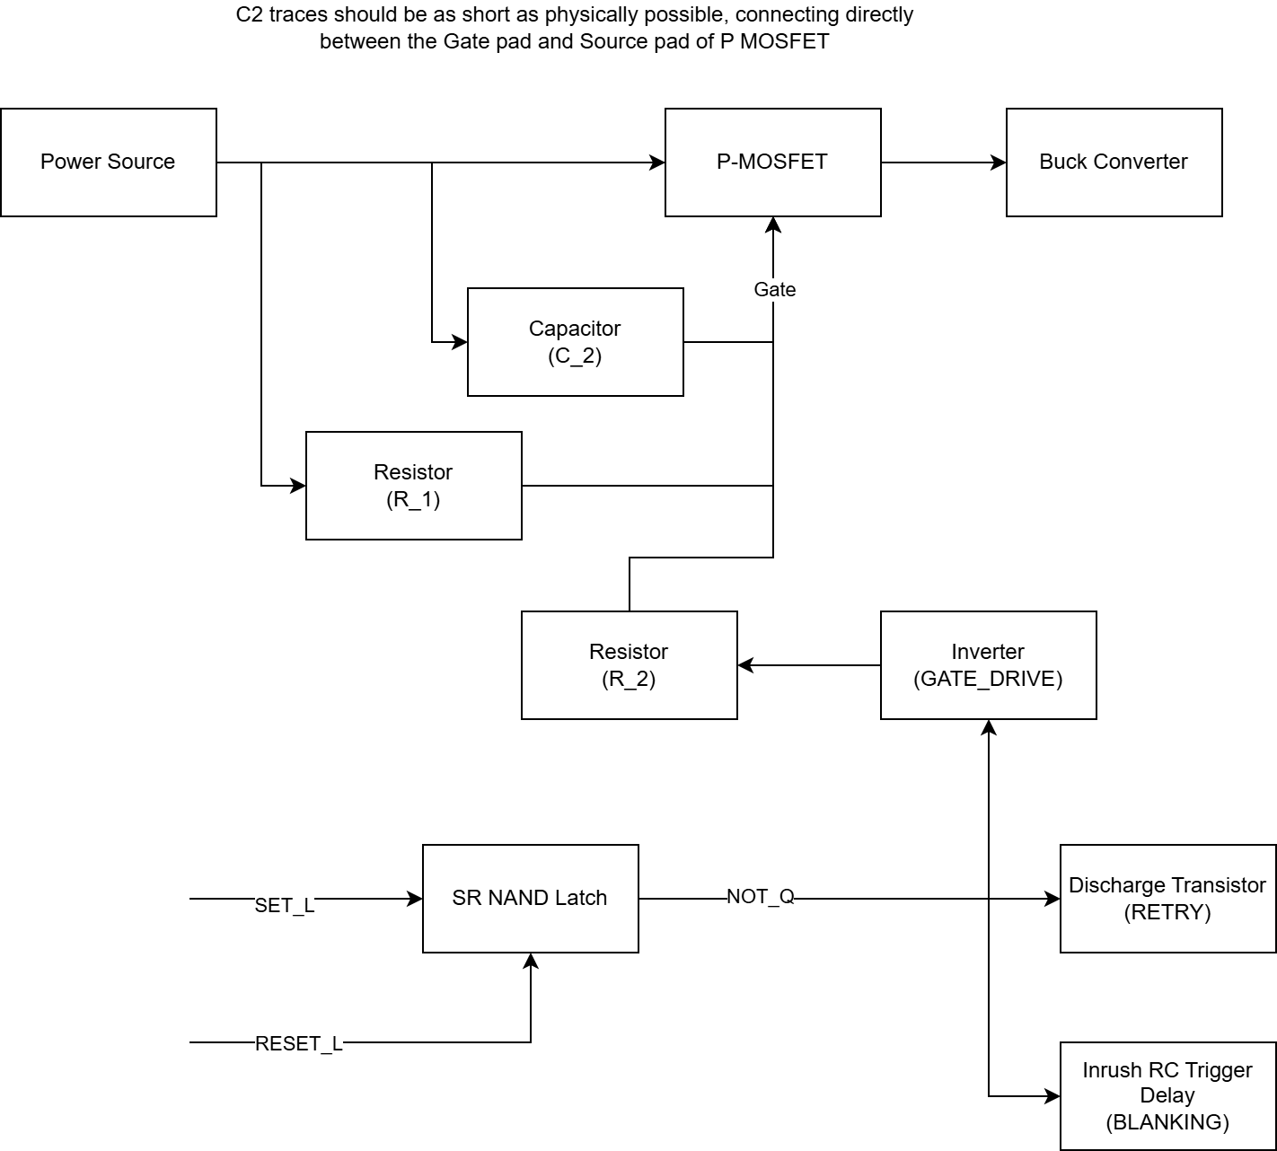
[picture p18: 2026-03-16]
latchup_detect_recover-gate_driver_direct_latch_out.drawio.png

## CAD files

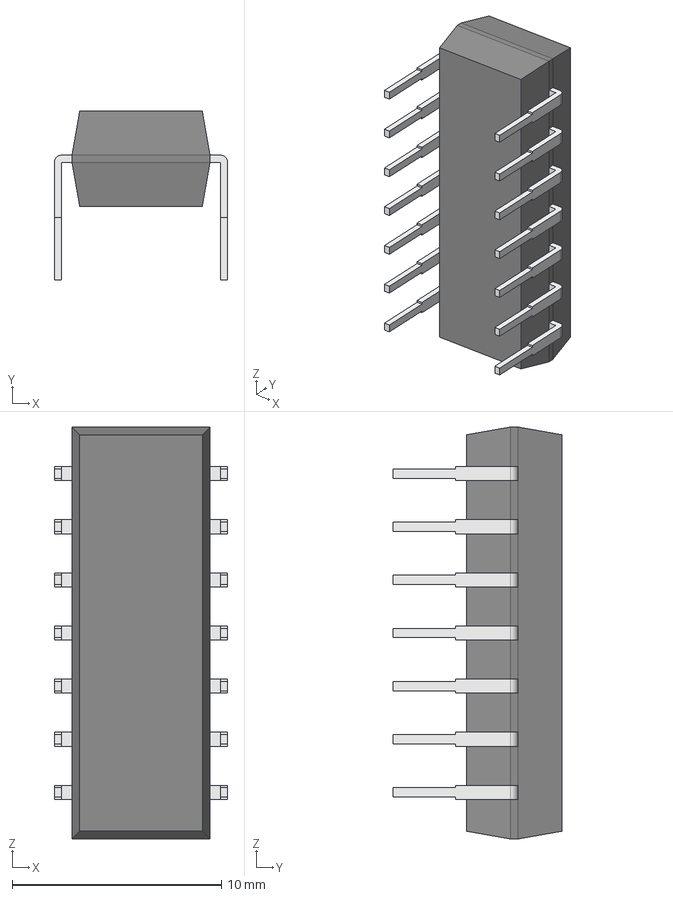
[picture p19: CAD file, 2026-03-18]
pcb/kicad_lib/SN74HC32N/SN74HC32N.step
8.29 x 8.08 x 19.7 mm
Body001 (Mirror #1) x 8

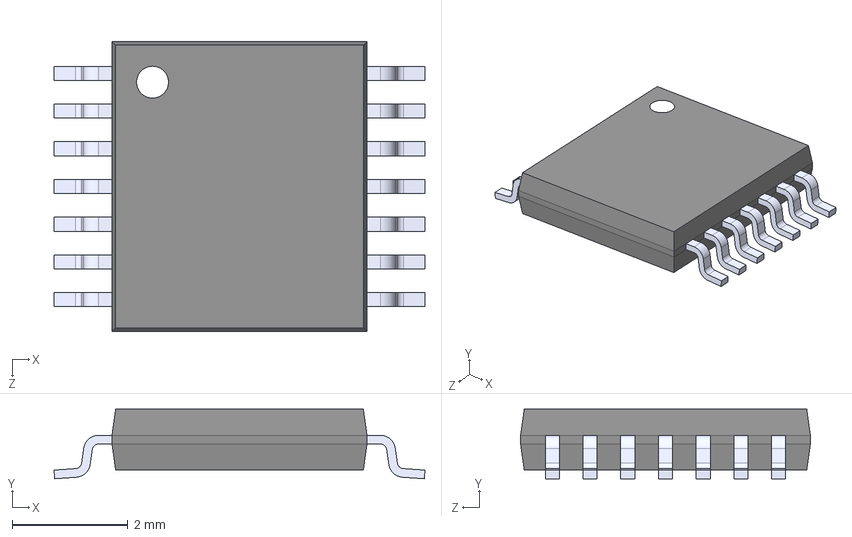
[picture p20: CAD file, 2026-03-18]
pcb/kicad_lib/SN74HC32PWR/SN74HC32PWR.step
6.40 x 1.20 x 5.00 mm

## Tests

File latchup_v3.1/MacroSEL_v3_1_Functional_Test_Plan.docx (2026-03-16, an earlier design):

MacroSEL Protection System v3.1

Functional Test Plan — Consumer-Grade Prototype

ARM Cortex-A72 Edge Computer | LEO Orbit Preparation

February 2026 | Document v1.0

# 1. Purpose and Scope

This test plan verifies the functional correctness of the MacroSEL Protection System v3.1 using consumer-grade equivalent components on a hand-assembled prototype board. The goal is to confirm that the protection logic — current sense, comparator threshold, global fault aggregation, master switch shutdown, 1-second retry timer, and infinite retry behavior — operates correctly before committing to space-grade components.

This is not a qualification test. Radiation tolerance, thermal cycling, vibration, and EMC are out of scope. Pass criteria here means the circuit logic is correct and timing is within spec.

⚠ WARNING: Consumer-grade substitutes are used throughout. Do not interpret passing results as flight readiness. These tests only validate the circuit topology and timing.

# 2. Consumer-Grade Component Substitutions

All /883B and /883C space-grade parts are replaced with commercial equivalents for this prototype. Electrical behavior is essentially identical; only radiation tolerance and screening differ.

Flight Part | Commercial Substitute | Package | Key Parameter Match
OP07CSZ/883B | OP07CP (TI/AD) | SOIC-8 or DIP-8 | Vos, Gain identical
LM139AMWC/883C | LM339 (any vendor) | SOIC-14 | Threshold, propagation delay identical
CD4049UM/883B | CD4049UBE or 74HCU04 | SOIC-16 | Logic levels, drive current matched
CD4072BM/883B | CD4072BE or 74HC4072 | SOIC-14 | OR logic identical
CD4093BM/883B | CD4093BE or 74HC132 | SOIC-14 | Schmitt thresholds similar
LM555CM/883C | NE555 or LM555 (commercial) | SOIC-8 or DIP-8 | Timing equation identical
CD4081BM/883B | CD4081BE or 74HC08 | SOIC-14 | AND logic identical
IRHLUC7970Z4 (D2PAK) | IRF9540N or FQP27P06 (D2PAK) | D2PAK | Rds(on), Vgs(th) close enough
WSL2512 (all values) | WSL2512 commercial (same part) | 2512 | Exact match — keep same part

NOTE: The WSL2512 sense resistors are not space-graded items — the commercial versions are the same part. No substitution needed.

# 3. Test Equipment Required

Item | Specification | Qty | Purpose
DC Bench PSU (main) | 5V, ≥10A, adjustable current limit | 1 | System power input
Oscilloscope | ≥4 channels, ≥10 MHz bandwidth, 1 GSa/s preferred | 1 | Capture fault signals and timing
Oscilloscope probes | 1x and 10x, ground clip leads | 4 | Signal probing
Function generator / pulse generator | 0–5V output, 1 Hz to 1 MHz, pulse mode | 1 | Trigger N-FET fault injection switch
Digital multimeter | Voltage and current measurement | 1 | DC verification, threshold checks
N-channel MOSFET switch (Rails 1 & 2) | Logic-level, ≥5A — e.g. IRLZ44N or IRFZ44N | 2 | Fault load injection switch for high-current rails
N-channel MOSFET switch (Rails 3–6) | Logic-level, ≥1A — e.g. 2N7000, BS170, IRLML2502 | 4 | Fault load injection switch for low-current rails
Gate resistor | 47 Ω, 0.25W resistor | 6 | Prevent oscillation on MOSFET gate
Power resistors — see Section 5 per rail | Wirewound, rated ≥5W unless noted | 12 | Normal load + fault load per rail
Breadboard or terminal block | For assembling fault injection subcircuit | 1 | Holds load resistors and N-FETs
Alligator clip leads | Rating ≥5A for high-current rails | 10+ | Connections
10x Attenuation probe ground spring | Short ground return | 4 | Reduce oscilloscope ground loop noise

⚠ WARNING: For Rails 1 and 2, use clip leads rated ≥5A. Standard thin bench leads will introduce significant resistance and affect current measurements.

# 4. Fault Injection Circuit — Concept and Construction

## 4.1 Principle

A real latchup event is a sudden, step-change increase in rail current — not a gradual ramp. An N-channel MOSFET switched by a pulse generator replicates this step behavior. The MOSFET connects a low-resistance fault load in parallel with a steady-state normal load, causing total current to exceed the trip threshold instantaneously.

The gate of the N-FET is driven by the function generator in pulse mode: one short pulse (e.g., 100 ms wide) turns the fault load on briefly, mimicking a latchup event. The protection circuit should trip within ~20 µs, so the fault load is present for only that duration before power is cut.

## 4.2 Schematic (per rail)

Rail voltage ──┬── R_normal (always on) ──┐

│ │── to GND

└── R_fault ── NFET drain │

NFET source ────┘ NFET gate ─── 47Ω ─── FuncGen pulse

## 4.3 Construction Notes

- Build the fault injection subcircuit on a breadboard or proto-board, separate from the protection PCB.
- Keep wiring short, especially the R_fault and N-FET drain-source path — parasitic inductance will slow down the current step.
- Connect the N-FET source directly to the load ground return, not through long leads.
- Set the function generator to pulse mode: frequency 0.1 Hz (10-second period), pulse width 500 ms. This gives one fault event every 10 seconds — enough time to observe the retry cycle fully.
- The 47 Ω gate resistor prevents gate ringing. Do not omit it.

⚠ WARNING: Do not use a mechanical relay for fault injection. Relay contact bounce (10–300 µs) will look like multiple fast latchup events and confuse the retry timer. Use only MOSFET switching.

## 4.4 PSU Current Limit Setting

Set the 5V bench PSU current limit to 8–9 A. This is above the worst-case fault current seen at the 5V input (Rail 1 + 2 fault simultaneously could draw ~5–6 A at 5V input after buck conversion losses). The protection circuit trips in ~20 µs, far faster than any PSU can respond (~1–10 ms), so the PSU limit will never activate during a properly functioning fault event. Setting it too low risks the PSU entering current limiting mode during the steady-state retry cycling, which would prevent the restart test from working.

# 5. Load Resistor Values per Rail

The following values are calculated for each rail. R_normal simulates steady-state device load at approximately 70% of rated current. When R_fault is switched in parallel by the N-FET, total current exceeds the trip threshold. All values confirmed against design trip thresholds from the v3.1 schematic.

Rail | Voltage | Trip Threshold | R_normal | Normal Current | R_fault | Fault Current | R_normal Power | R_fault Power (momentary)
Rail 1 (AI Core A) | 3.3 V | 5.8 A | 1.0 Ω | 3.3 A | 1.2 Ω | 6.1 A total | 10.9 W → use 15 W | 9.1 W → use 10 W
Rail 2 (AI Core B) | 3.3 V | 5.8 A | 1.0 Ω | 3.3 A | 1.2 Ω | 6.1 A total | 10.9 W → use 15 W | 9.1 W → use 10 W
Rail 3 (1.2V CPU/RAM) | 1.2 V | 3.5 A | 0.5 Ω | 2.4 A | 1.0 Ω | 3.6 A total | 2.9 W → use 5 W | 1.4 W → use 5 W
Rail 4 (1.35V CPU) | 1.35 V | 0.5 A | 4.7 Ω | 0.29 A | 4.3 Ω | 0.60 A total | 0.39 W → use 1 W | 0.42 W → use 1 W
Rail 5 (1.8V CPU/eMMC) | 1.8 V | 2.3 A | 1.2 Ω | 1.5 A | 1.8 Ω | 2.5 A total | 2.7 W → use 5 W | 1.8 W → use 5 W
Rail 6 (2.5V CPU/RAM) | 2.5 V | 1.2 A | 3.3 Ω | 0.76 A | 4.3 Ω | 1.34 A total | 1.9 W → use 5 W | 1.5 W → use 5 W

NOTE: R_fault power ratings assume a momentary fault of <1 ms before shutdown. Even standard resistors will survive this transiently. However use the rated wattage listed above, as the retry cycle may keep triggering repeatedly.

NOTE: Rail 4 is the most sensitive rail at only 0.5 A trip. The margin between normal load (0.29 A) and trip (0.5 A) is narrow. Be precise with R_normal — a 10% resistor tolerance could matter here. Use 1% tolerance resistors on Rail 4.

# 6. Oscilloscope Setup

## 6.1 Channel Assignment

Channel | Signal | Probe Point | Scale
CH1 | 5V_OUTPUT (downstream of P-FET) | Q1 drain test point | 2 V/div
CH2 | GLOBAL_FAULT | OR gate output (U2 pin 6) | 2 V/div
CH3 | ENABLE_GLOBAL | AND gate output (U7) | 2 V/div
CH4 | FAULT_n (rail under test) | Comparator output for active rail | 2 V/div

## 6.2 Trigger Settings

- Trigger source: CH2 (GLOBAL_FAULT), falling edge — this fires the moment any fault is detected.
- Trigger level: 2.5 V (midpoint of 5V logic).
- Pre-trigger: 20% — to capture the signal state just before the fault.
- Time base: 10 µs/div for response time verification; switch to 500 ms/div for retry cycle verification.
- Acquisition mode: Normal (not Auto), so the scope waits for a real trigger event.

## 6.3 Ground Return

Use short ground spring clips on all four probes. Do NOT share a single ground point connected through a long alligator lead — at 10 µs time resolution, a 30 cm ground lead introduces ~1 µs of inductance-related error. Connect each probe ground to the board ground plane at a test point as close to the probe tip as possible.

# 7. Pre-Test Checks (Power OFF)

Before applying any power, verify the following with a multimeter:

1. Check for shorts: measure resistance between 5V input and GND. Should be >> 1 kΩ. If near zero, stop — there is a solder bridge.
2. Verify all SOIC ICs are seated correctly. Check pin 1 markers against schematic. Inspect for solder bridges on 1.27mm pitch pads under magnification.
3. Verify tantalum capacitor polarity — stripe on the capacitor body is the NEGATIVE terminal. Reversed tantalum will fail destructively within seconds of power application.
4. Verify R12 is the 10 MΩ value (1206 size). Confirm with multimeter. This sets the 1-second retry delay — a wrong value here gives wrong timing.
5. Verify D2PAK thermal vias under Q1 are present and not blocked with solder mask. These are essential for heat dissipation during repeated switching.
6. Verify all unused CD4049 and CD4000-series inputs are tied to GND or VCC as specified in the schematic. Floating CMOS inputs will cause spurious logic states.
7. Measure all R_SENSE resistors in-circuit. Values should match the table in Section 5. Kelvin sensing pads should have no shorts between Force and Sense terminals.

# 8. Per-Rail Functional Test Procedure

Perform this procedure once per rail (six times total). Each test is independent. Test rails one at a time — connect the fault injection circuit only to the rail under test. All other rails carry only their steady-state normal load resistors.

⚠ WARNING: During testing, the protection circuit will repeatedly cut power to the entire system (all six rails) every time a fault is detected on any rail. This is expected behavior — the system has no per-rail isolation. All rails lose power on any single fault.

## 8.1 Setup for Each Rail

8. Power OFF. Connect R_normal for the rail under test between the rail output pad and GND.
9. Connect R_fault in series with the N-FET drain-source path, also between rail output and GND (in parallel with R_normal).
10. Connect the function generator output (0–5V, pulse mode, 0.1 Hz, 500 ms pulse) to the N-FET gate through the 47 Ω gate resistor.
11. Connect steady-state normal loads (R_normal only, no fault injection) to the other five rails.
12. Set oscilloscope: CH1 to 5V_OUTPUT, CH2 to GLOBAL_FAULT, CH3 to ENABLE_GLOBAL, CH4 to FAULT_n for the rail under test.
13. Set time base to 10 µs/div. Trigger: CH2 falling edge, 2.5 V, 20% pre-trigger.

## 8.2 Test A — Steady-State Normal Operation (No Fault)

Confirm the system runs without false trips under normal load.

14. Power ON at 5V. Do not trigger the function generator yet.
15. Observe the startup sequence: after PMIC_PGOOD asserts, wait 300 ms for the startup delay RC (R11/C5). ENABLE_GLOBAL should go HIGH after this delay.
16. Measure 5V_OUTPUT — should be 5V stable (ripple < 50 mV).
17. Measure each rail output voltage with multimeter: 3.3V, 3.3V, 1.2V, 1.35V, 1.8V, 2.5V ±5%.
18. Verify GLOBAL_FAULT is HIGH (no fault). Verify ENABLE_GLOBAL is HIGH.
19. Run for 60 seconds without triggering any fault. Confirm no spurious trips.

Pass criteria: No trips, all rails within ±5%, FAULT_n signals all HIGH.

## 8.3 Test B — Overcurrent Trip Response

Confirm the system detects overcurrent on the rail under test and shuts down.

20. System running normally from Test A. Arm the oscilloscope (Normal trigger mode).
21. Trigger the function generator to send one pulse (or manually pulse the gate high for ~500 ms).
22. The N-FET turns ON, switching in R_fault. Total rail current should exceed the trip threshold from the table in Section 5.
23. Capture oscilloscope trace.

Expected waveform sequence:

- FAULT_n (CH4): Goes LOW (fault asserted) within ~5–8 µs of N-FET turn-on.
- GLOBAL_FAULT (CH2): Goes LOW within ~1 µs of FAULT_n going LOW (OR gate propagation).
- ENABLE_GLOBAL (CH3): Goes LOW within ~2 µs of GLOBAL_FAULT going LOW (AND gate + logic chain).
- 5V_OUTPUT (CH1): Begins to fall within ~10 µs of ENABLE_GLOBAL going LOW (P-FET gate RC).
- Total response time from N-FET turn-on to 5V_OUTPUT dropping below 4.5V: should be ≤ 20 µs.

Pass criteria: Total response time ≤ 20 µs. All signal transitions observed in correct sequence.

⚠ WARNING: If response time exceeds 20 µs, check: (1) gate resistor R2 on Q1 — should be 100 Ω, (2) C2 gate snubber — should be 100 nF, (3) op-amp gain stage — measure V_AMP signal at comparator input to confirm it crossed V_REF before FAULT_n fired.

## 8.4 Test C — Retry Delay Timing

Confirm the 1-second retry delay is correct.

24. Switch oscilloscope time base to 500 ms/div.
25. Set trigger to CH1 (5V_OUTPUT) rising edge — this captures the restart attempt.
26. Trigger one fault event as in Test B.
27. Observe the waveform: after 5V_OUTPUT drops, it should remain LOW for approximately 1.0 second, then attempt to rise again.
28. Measure the duration from 5V_OUTPUT falling to 5V_OUTPUT next rising edge. Should be 1.0 s ± 10% (0.9–1.1 s).

Pass criteria: Retry delay between 0.9 s and 1.1 s.

NOTE: The 1-second delay is set by R12 (10 MΩ) and C6 (100 nF): t = 1.1 × R × C = 1.1 s. Component tolerances (R ±5%, C ±10%) can give up to ±15% variation, so 0.85–1.25 s is the component-tolerance range. The ±10% pass window is tighter than this — if the board fails on timing, measure R12 and C6 values individually.

## 8.5 Test D — Recovery After Transient Fault

Confirm the system recovers to normal operation when the fault condition clears.

29. Set function generator to generate one 50 ms pulse (shorter than the retry delay, fault clears before restart).
30. Trigger the fault. The system shuts down. After 1 second, the system restarts. Since the N-FET gate pulse has expired and R_fault is no longer active, the restart should succeed.
31. Observe: after 1-second delay, 5V_OUTPUT rises, PMIC_PGOOD asserts, startup delay fires (300 ms), ENABLE_GLOBAL goes HIGH, system runs normally.
32. Verify all rail voltages return to correct values after restart.
33. Verify no further trips occur (no false triggers from inrush at startup).

Pass criteria: System recovers to full normal operation after one transient fault. No false trips during startup inrush.

⚠ WARNING: Inrush current during restart could trip a sensitive rail (especially Rail 4 at 0.5 A). If false trips occur consistently on restart, the startup delay (300 ms) may need to be increased. Check whether FAULT_n is going LOW during the startup transient — if so, this is a false trip from inrush, not a real fault.

## 8.6 Test E — Infinite Retry Under Persistent Fault

Confirm the system retries indefinitely when the fault does not clear.

34. Connect R_fault permanently (bypass the N-FET — wire R_fault directly in parallel with R_normal). This simulates a component that has latched permanently.
35. Power ON. System will detect overcurrent immediately after startup delay, trip, wait 1 second, attempt restart, trip again, and repeat.
36. Let the system cycle for at least 60 seconds. Count cycles manually or use oscilloscope persistence to confirm regular cycling.
37. Verify the cycle period is approximately 1.36 s: 1.0 s OFF + ~360 ms ON before trip.
38. Verify the system never enters a state where it stops trying (no permanent lockout).

Pass criteria: System cycles continuously, never permanently latches off, approximately 1.36 s per cycle.

## 8.7 Test F — OBC Power Cutoff Simulation

Simulate what the OBC would do in a stuck retry loop: manually remove 5V input.

39. With persistent fault condition from Test E running, wait 10 retry cycles.
40. Manually switch OFF the 5V bench PSU (or disconnect the 5V input).
41. Verify all outputs immediately go to 0V. Verify no residual voltage on any rail after 5 seconds (bulk capacitors should discharge).
42. Power the 5V input back ON. With fault condition still present, verify system resumes retry cycling (does not require any manual reset to the protection circuit itself).

Pass criteria: Clean shutdown on power removal. System resumes cycling automatically on power restore.

# 9. Pass/Fail Checklist Summary

Complete this checklist for all six rails. A single FAIL in any row is a blocking issue requiring schematic or component review before proceeding.

Test | Rail 1 3.3V AI-A | Rail 2 3.3V AI-B | Rail 3 1.2V CPU | Rail 4 1.35V CPU | Rail 5 1.8V CPU | Rail 6 2.5V CPU
A: Normal operation, no false trips (60s) | Pass/Fail | Pass/Fail | Pass/Fail | Pass/Fail | Pass/Fail | Pass/Fail
B: Trip response ≤ 20 µs | Pass/Fail | Pass/Fail | Pass/Fail | Pass/Fail | Pass/Fail | Pass/Fail
B: Correct signal sequence observed | Pass/Fail | Pass/Fail | Pass/Fail | Pass/Fail | Pass/Fail | Pass/Fail
C: Retry delay 0.9–1.1 s | Pass/Fail | Pass/Fail | Pass/Fail | Pass/Fail | Pass/Fail | Pass/Fail
D: Recovery after transient fault | Pass/Fail | Pass/Fail | Pass/Fail | Pass/Fail | Pass/Fail | Pass/Fail
E: Infinite retry under persistent fault | Pass/Fail | Pass/Fail | Pass/Fail | Pass/Fail | Pass/Fail | Pass/Fail
F: Clean shutdown on PSU removal | Pass/Fail | Pass/Fail | Pass/Fail | Pass/Fail | Pass/Fail | Pass/Fail
Measured trip threshold (record actual A) | __A | __A | __A | __A | __A | __A
Measured retry delay (record actual s) | __s | __s | __s | __s | __s | __s

# 10. Known Issues and Failure Mode Guide

Symptom | Likely Cause | Action
System never enables after power-on (ENABLE_GLOBAL stays LOW) | Startup delay RC not charging — check R11 (1 MΩ), C5 (330 nF), or PMIC_PGOOD signal not arriving | Probe DELAY_NODE — if not rising to ~2.5V after 300ms, check R11/C5 values and PMIC_PGOOD source
False trips immediately after startup — trips on inrush | Startup delay too short for PMIC soft-start current, or R_normal too low causing inrush to exceed trip threshold | Increase C5 to 470–680 nF to extend startup delay. Verify inrush at startup with oscilloscope.
Response time >> 20 µs | R2 (gate resistor) or C2 (gate snubber) wrong value, or op-amp output not reaching V_REF fast enough | Probe V_AMP node on comparator input — check if it exceeds V_REF within 5 µs of fault. Check R2 = 100 Ω
System trips but does not retry (stays off) | R12 is wrong value (not 10 MΩ), or 555 timer not functioning. Or LM555 RESET pin (pin 4) not tied to VCC | Measure R12 in-circuit. Check LM555 pin 4 connection. Probe RETRY_PULSE (pin 3 of U4)
Retry delay much shorter or longer than 1 s | R12 or C6 tolerance issue. Check: t = 1.1 × R12 × C6 | Measure R12 and C6 actual values, recalculate expected t
One rail does not trip when expected | V_REF divider wrong values (R7/R8), or op-amp gain resistor wrong (R6 should be 200 kΩ), or R_SENSE wrong value | Probe V_AMP node — does it exceed V_REF at fault current? If not, check gain resistors. Measure V_REF with DMM.
All rails trip simultaneously with no fault injected | Floating input on one of the CD4000-series ICs pulling GLOBAL_FAULT LOW spuriously | Check all unused gate inputs on CD4072, CD4093, CD4081, CD4049 are tied to VCC or GND per schematic
Rail 4 (1.35V) false trips on startup | Narrowest margin rail (0.5A trip, 0.29A normal) — inrush during PMIC startup likely exceeds 0.5A briefly | Scope FAULT_4 during startup. If tripping on inrush, extend startup delay or increase R_normal for Rail 4 during test to reduce sensitivity during validation

# 11. Critical Supply Chain Risk Items

Two components are flagged as procurement risks that should be actioned in parallel with functional testing. These are not needed for the consumer-grade prototype but are critical for the flight board.

Component | Flight Part | Risk | Action Required
Timer IC | SE555-SP (Texas Instruments Space Products) | Listed as active product but stock availability on distributor sites is inconsistent. TI Space Products typically quotes 26–52 week lead times. No known equivalent SE555 with equivalent space qualification from another manufacturer. | 1. Submit a formal purchase request to TI Space Products directly (not via distributor) to get an official lead time commitment. 2. Ask for last-time buy terms if the product is at end of active procurement. 3. If lead time > 12 months, evaluate whether the timer function can be redesigned using an available rad-hard equivalent (e.g., CD4093-based RC oscillator, though this changes the logic).
Master P-FET | IRHLUC7970Z4 (Infineon / International Rectifier, D2PAK) | Sales contact initiated but no response yet. The IRHLUC7970Z4 is a specific radiation-hardened P-channel MOSFET. No confirmed direct drop-in replacement with equivalent TID + SEL immunity is identified. | 1. Escalate from manufacturer sales to distributor (e.g., Sager, Arrow, Digi-Key space components team) — distributors often have faster responses for stocking inquiries. 2. If part is confirmed active, place a non-binding demand signal immediately. 3. If part is discontinued or on excessive lead time, evaluate the IRF9P04 SMD (less common) or reconsider whether a different rad-hard P-FET with similar Rds(on) and Vgs(th) can be qualified.

⚠ WARNING: Do not wait until functional testing is complete to resolve these supply chain issues. Lead times of 6–12 months are realistic. If you finish testing in 4 weeks and then discover the SE555-SP has a 52-week lead time, your flight board schedule slips by a year.

# 12. After Functional Testing — Next Steps

- If all tests PASS: proceed to flight-grade component sourcing using /883B and /883C parts, then build a second board with space-grade components and repeat this test plan to confirm equivalence.
- If tests reveal a design issue: update schematic, revise the plan document to v3.2, rebuild prototype with corrected components, and re-run all affected tests.
- After a flight-grade build passes this test plan: the design is ready for radiation testing (heavy-ion or proton beam). Functional testing does not validate radiation tolerance — that requires beam testing at a facility such as LBNL, TAMU, or UCDavis.
- OBC integration: the infinite retry behavior requires the OBC to cut power if the device is stuck. This software-side behavior must be implemented and tested in a separate integration test, not covered here.

— End of Test Plan —

MacroSEL Protection v3.1 | February 2026

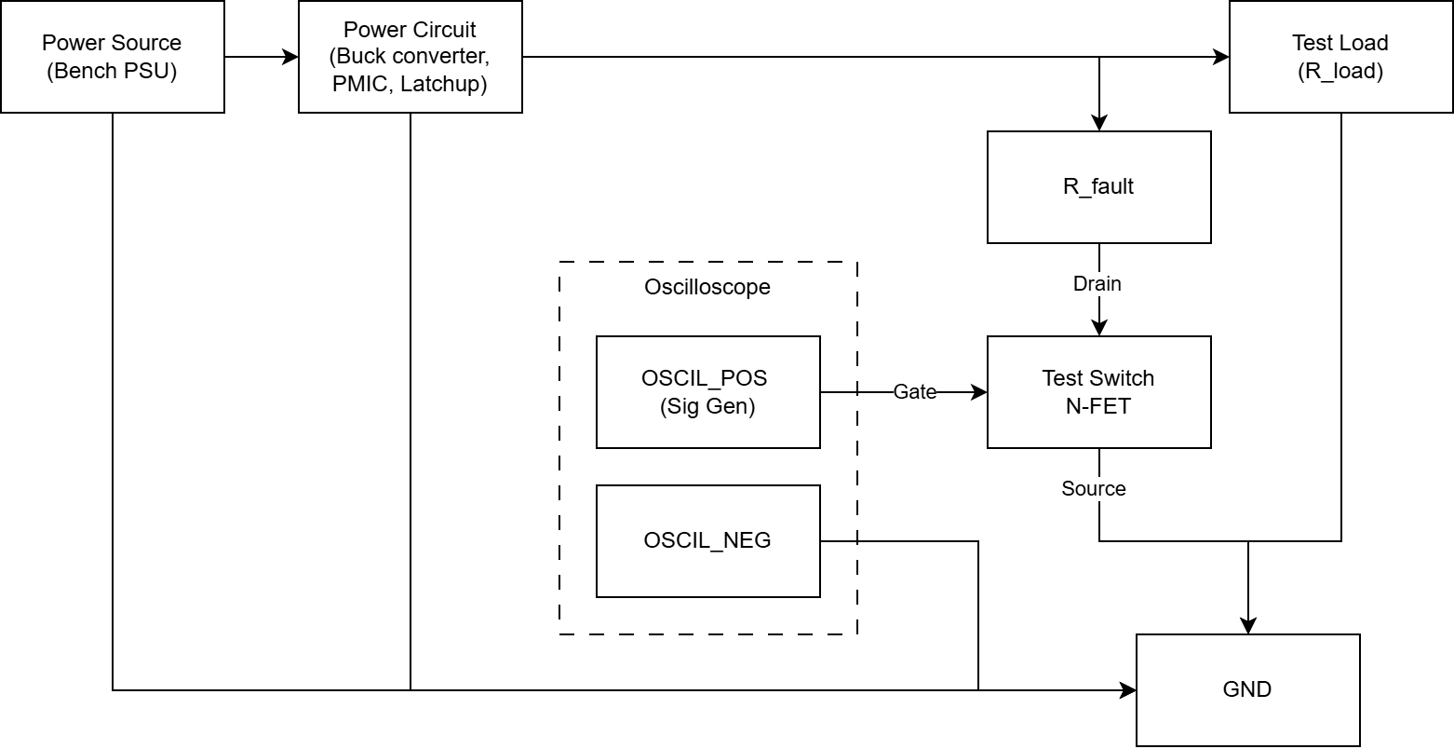
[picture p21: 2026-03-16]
latchup_detect_recover-test_bench.drawio.png

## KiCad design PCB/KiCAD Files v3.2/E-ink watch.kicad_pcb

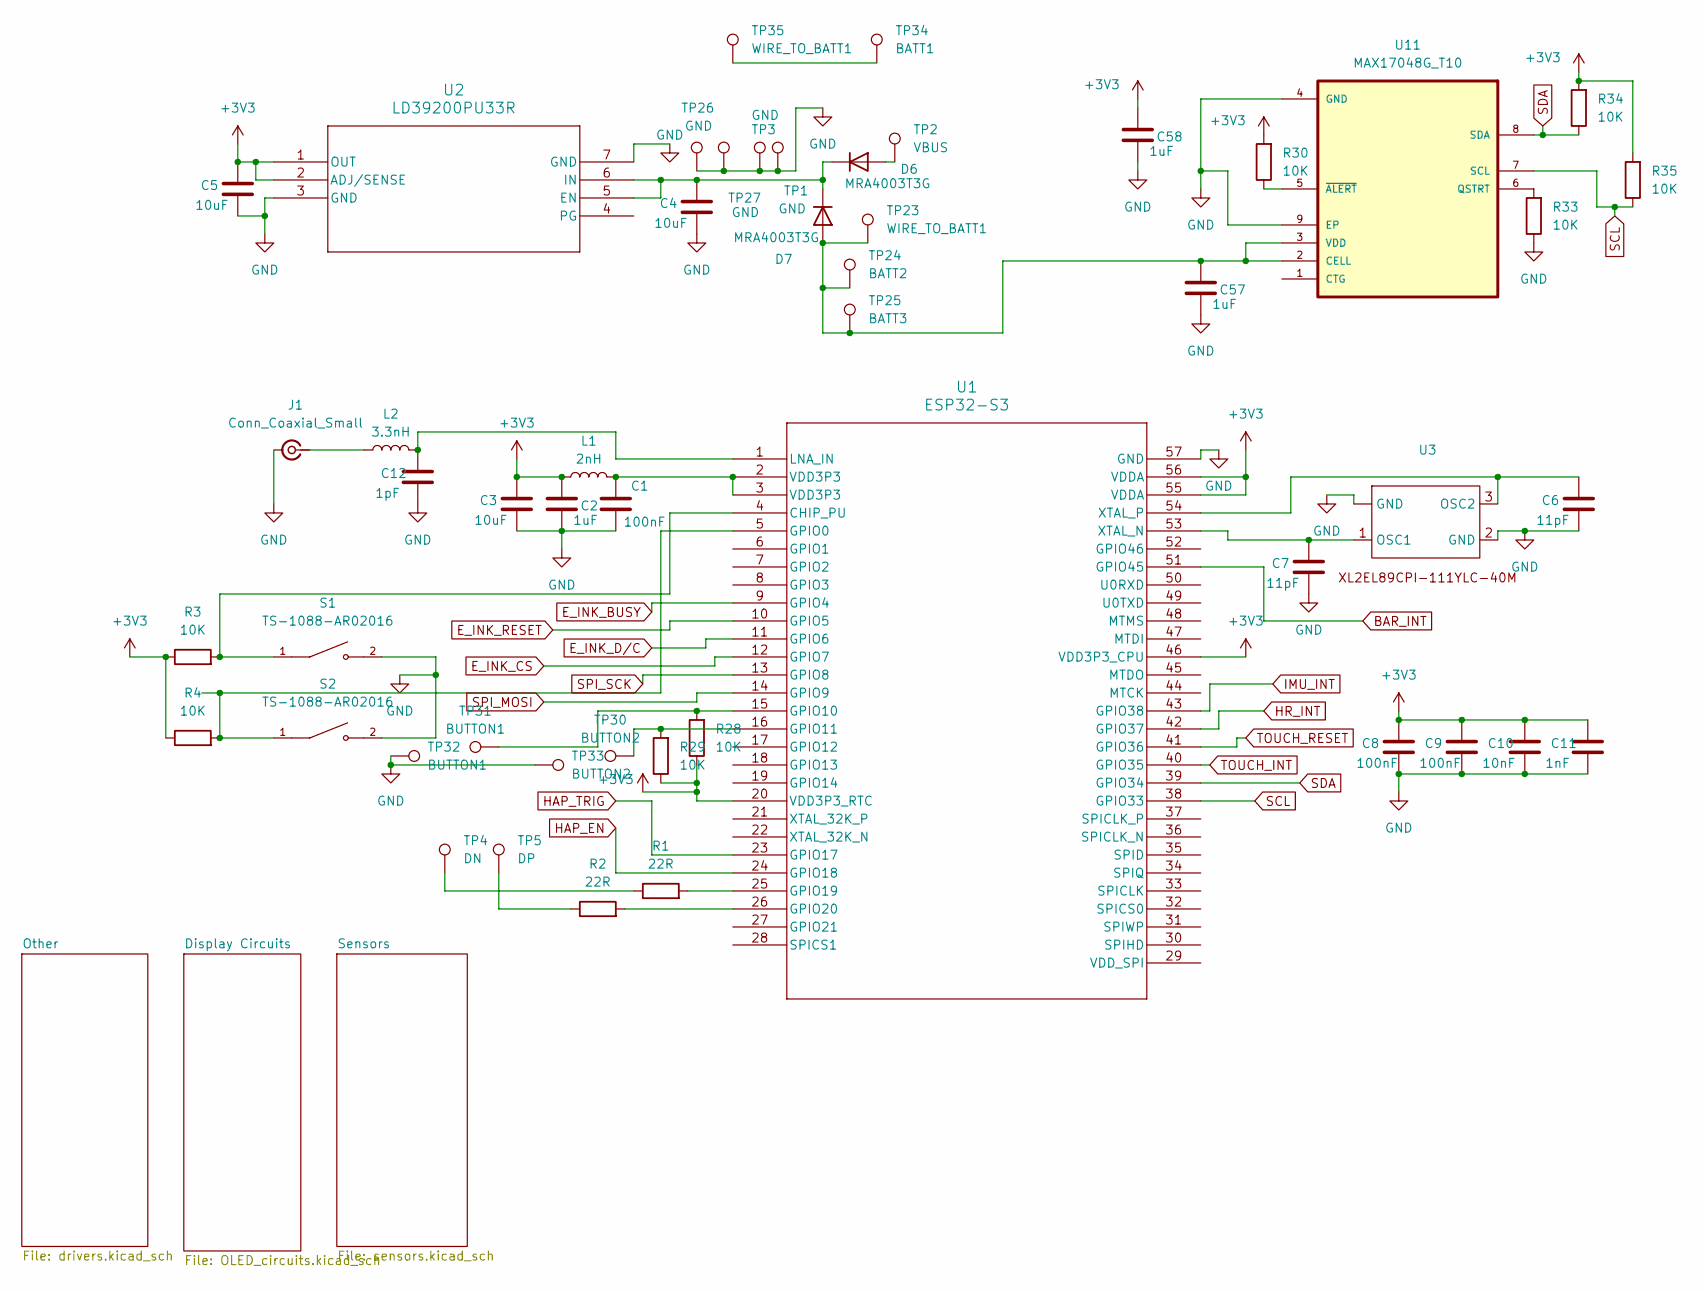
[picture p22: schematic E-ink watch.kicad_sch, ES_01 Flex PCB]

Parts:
C1, C8, C9: 100nF; C_0402_1005Metric_Pad0.74x0.62mm_HandSolder
C2, C57, C58: 1uF; C_0402_1005Metric_Pad0.74x0.62mm_HandSolder
C3, C4, C5: 10uF; C_0402_1005Metric_Pad0.74x0.62mm_HandSolder
C6, C7: 11pF; C_0402_1005Metric_Pad0.74x0.62mm_HandSolder
C10: 10nF; C_0402_1005Metric_Pad0.74x0.62mm_HandSolder
C11: 1nF; C_0402_1005Metric_Pad0.74x0.62mm_HandSolder
C12: 1pF; C_0402_1005Metric_Pad0.74x0.62mm_HandSolder
D6, D7: MRA4003T3G; D_SMA
J1: Conn_Coaxial_Small; U.FL_Hirose_U.FL-R-SMT-1_Vertical
L1: 2nH; L_0402_1005Metric_Pad0.77x0.64mm_HandSolder
L2: 3.3nH; L_0402_1005Metric_Pad0.77x0.64mm_HandSolder
R1, R2: 22R; R_0402_1005Metric_Pad0.72x0.64mm_HandSolder
R3, R4, R28, R29, R30, R33, R34, R35: 10K; R_0402_1005Metric_Pad0.72x0.64mm_HandSolder
S1, S2: TS-1088-AR02016; SW_TS-1088-AR02016; PARTREV N/A
TP1, TP3, TP26, TP27: GND; TestPoint_Pad_1.5x1.5mm
TP2: VBUS; TestPoint_Pad_1.5x1.5mm
TP4: DN; TestPoint_Pad_1.5x1.5mm
TP5: DP; TestPoint_Pad_1.5x1.5mm
TP23, TP35: WIRE_TO_BATT1; TestPoint_Pad_1.5x1.5mm
TP24: BATT2; TestPoint_Pad_1.5x1.5mm
TP25: BATT3; TestPoint_Pad_1.5x1.5mm
TP30, TP33: BUTTON2; TestPoint_Pad_1.5x1.5mm
TP31, TP32: BUTTON1; TestPoint_Pad_1.5x1.5mm
TP34: BATT1; TestPoint_Pad_1.5x1.5mm
U1: ESP32-S3; QFN56_7X7_EXP
U2: LD39200PU33R; SON_DFN6_3X3_STM
U3: Untitled
U11: MAX17048G_T10; SON50P200X200X80-9N

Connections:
+3V3: C2.1, C3.1, C5.1, C8.1, C9.1, C10.1, C11.1, C58.1, L1.1, R3.1, R4.1, R28.1, R29.1, R30.2, R34.2, R35.2, U1.20 (VDD3P3_RTC), U1.46 (VDD3P3_CPU), U1.55 (VDDA), U1.56 (VDDA), U2.1 (OUT), U2.2 (ADJ/SENSE); also elsewhere on the board
BAR_INT: U1.51 (GPIO45); also elsewhere on the board
E_INK_BUSY: U1.9 (GPIO4); also elsewhere on the board
E_INK_CS: U1.12 (GPIO7); also elsewhere on the board
E_INK_D/C: U1.11 (GPIO6); also elsewhere on the board
E_INK_RESET: U1.10 (GPIO5); also elsewhere on the board
GND: C1.2, C2.2, C3.2, C4.2, C5.2, C6.2, C7.2, C8.2, C9.2, C10.2, C11.2, C12.2, C57.2, C58.2, J1.2 (Ext), R33.1, S1.2, S2.2, TP1.1, TP3.1, TP26.1, TP27.1, TP32.1, TP33.1, U1.57 (GND), U2.3 (GND), U2.7 (GND), U3. (GND), U3.2 (GND), U11.4 (GND), U11.9 (EP); also elsewhere on the board
HAP_EN: U1.24 (GPIO18); also elsewhere on the board
HAP_TRIG: U1.23 (GPIO17); also elsewhere on the board
HR_INT: U1.42 (GPIO37); also elsewhere on the board
IMU_INT: U1.43 (GPIO38); also elsewhere on the board
unnamed: C1.1, L1.2, U1.2 (VDD3P3), U1.3 (VDD3P3)
unnamed: D6.2 (A), TP2.1
unnamed: C4.1, D6.1 (K), D7.1 (K), U2.5 (EN), U2.6 (IN)
unnamed: C57.1, D7.2 (A), TP23.1, TP24.1, TP25.1, U11.2 (CELL), U11.3 (VDD)
unnamed: J1.1 (In), L2.1
unnamed: R1.1, TP4.1
unnamed: R2.1, TP5.1
unnamed: TP34.1, TP35.1
unnamed: R3.2, S1.1, U1.4 (CHIP_PU)
unnamed: R4.2, S2.1, U1.5 (GPIO0)
unnamed: R28.2, TP31.1, U1.15 (GPIO10)
unnamed: R29.2, TP30.1, U1.16 (GPIO11)
unnamed: R1.2, U1.25 (GPIO19)
unnamed: R2.2, U1.26 (GPIO20)
unnamed: C12.1, L2.2, U1.1 (LNA_IN)
unnamed: C7.1, U1.53 (XTAL_N), U3.1 (OSC1)
unnamed: C6.1, U1.54 (XTAL_P), U3.3 (OSC2)
unnamed: R33.2, U11.6 (QSTRT)
unnamed: R30.1, U11.5 (~ALERT)
SCL: R35.1, U1.38 (GPIO33), U11.7 (SCL); also elsewhere on the board
SDA: R34.1, U1.39 (GPIO34), U11.8 (SDA); also elsewhere on the board
SPI_MOSI: U1.14 (GPIO9); also elsewhere on the board
SPI_SCK: U1.13 (GPIO8); also elsewhere on the board
TOUCH_INT: U1.40 (GPIO35); also elsewhere on the board
TOUCH_RESET: U1.41 (GPIO36); also elsewhere on the board

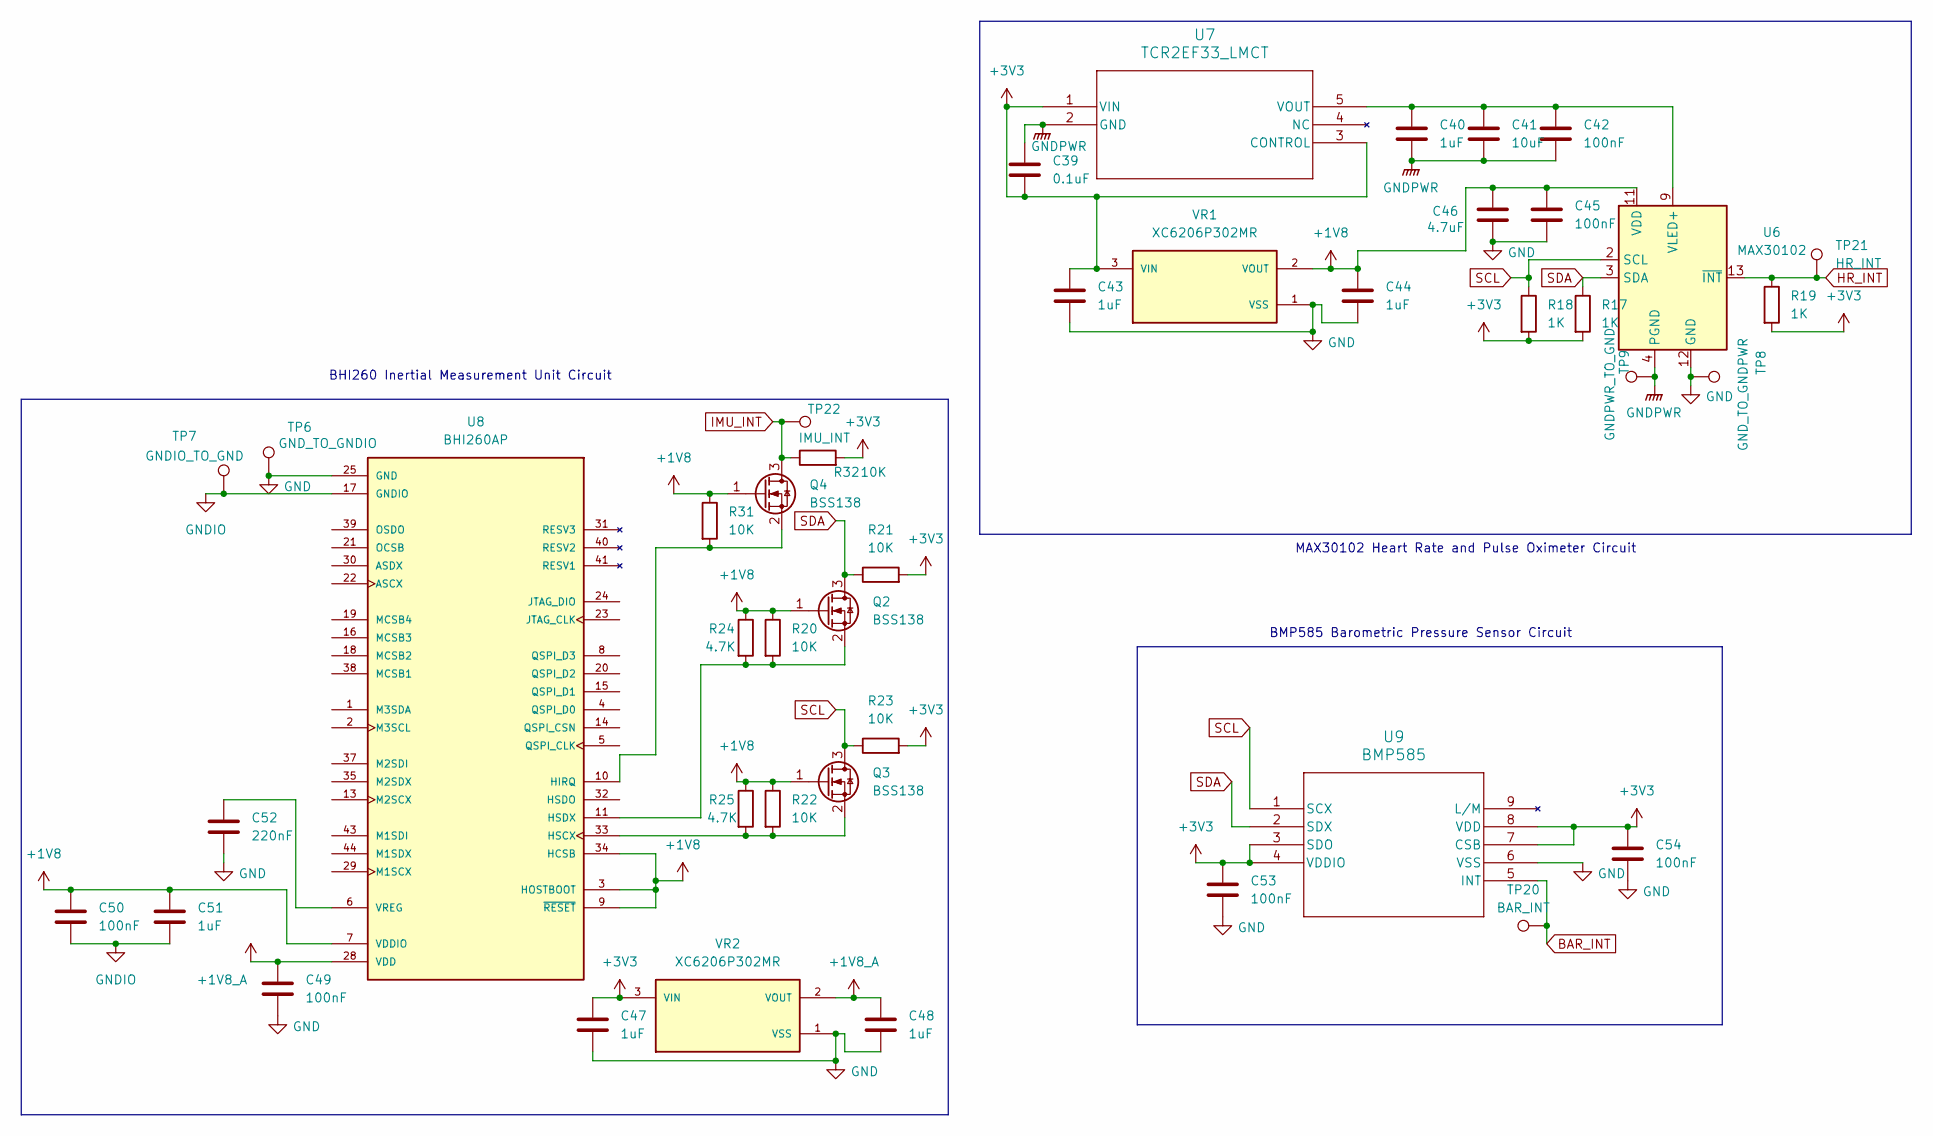
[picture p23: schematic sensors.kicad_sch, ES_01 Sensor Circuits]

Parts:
C39: 0.1uF; C_0402_1005Metric_Pad0.74x0.62mm_HandSolder
C40, C43, C44, C47, C48, C51: 1uF; C_0402_1005Metric_Pad0.74x0.62mm_HandSolder
C41: 10uF; C_0402_1005Metric_Pad0.74x0.62mm_HandSolder
C42, C45, C49, C50, C53, C54: 100nF; C_0402_1005Metric_Pad0.74x0.62mm_HandSolder
C46: 4.7uF; C_0402_1005Metric_Pad0.74x0.62mm_HandSolder
C52: 220nF; C_0402_1005Metric_Pad0.74x0.62mm_HandSolder
Q2, Q3, Q4: BSS138; SOT-23
R17, R18, R19: 1K; R_0402_1005Metric_Pad0.72x0.64mm_HandSolder
R20, R21, R22, R23, R31, R32: 10K; R_0402_1005Metric_Pad0.72x0.64mm_HandSolder
R24, R25: 4.7K; R_0402_1005Metric_Pad0.72x0.64mm_HandSolder
TP6: GND_TO_GNDIO; TestPoint_Pad_1.5x1.5mm
TP7: GNDIO_TO_GND; TestPoint_Pad_1.5x1.5mm
TP8: GND_TO_GNDPWR; TestPoint_Pad_1.5x1.5mm
TP9: GNDPWR_TO_GND; TestPoint_Pad_1.5x1.5mm
TP20: BAR_INT; TestPoint_Pad_D1.0mm
TP21: HR_INT; TestPoint_Pad_D1.0mm
TP22: IMU_INT; TestPoint_Pad_D1.0mm
U6: MAX30102; Maxim_OLGA-14_3.3x5.6mm_P0.8mm
U7: TCR2EF33_LMCT; SOT-25 SMV_TOS
U8: BHI260AP; XDCR_BHI260AP; PARTREV 1.1
U9: BMP585; LGA9_BMP585_BOS
VR1, VR2: XC6206P302MR; SOT95P280X130-3N; PARTREV N/A

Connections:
+1V8: C44.1, C45.1, C46.1, C50.1, C51.1, Q2.1 (G), Q3.1 (G), Q4.1 (G), R20.1, R22.1, R24.1, R25.1, R31.1, U6.11 (VDD), U8.3 (HOSTBOOT), U8.7 (VDDIO), U8.9 (~RESET), U8.12 (VDDIO), U8.34 (HCSB), U8.42 (VDDIO), VR1.2 (VOUT)
+1V8_A: C48.1, C49.1, U8.28 (VDD), VR2.2 (VOUT)
+3V3: C39.2, C43.1, C47.1, C53.1, C54.1, R17.2, R18.2, R19.2, R21.2, R23.2, R32.2, U7.1 (VIN), U7.3 (CONTROL), U9.3 (SDO), U9.4 (VDDIO), U9.7 (CSB), U9.8 (VDD), VR1.3 (VIN), VR2.3 (VIN); also elsewhere on the board
BAR_INT: TP20.1, U9.5 (INT); also elsewhere on the board
GND: C43.2, C44.2, C45.2, C46.2, C47.2, C48.2, C49.2, C52.2, C53.2, C54.2, TP6.1, TP8.1, U6.12 (GND), U8.25 (GND), U8.26 (GND), U8.27 (GND), U9.6 (VSS), VR1.1 (VSS), VR2.1 (VSS); also elsewhere on the board
GNDIO: C50.2, C51.2, TP7.1, U8.17 (GNDIO), U8.36 (GNDIO)
GNDPWR: C39.1, C40.2, C41.2, C42.2, TP9.1, U6.4 (PGND), U7.2 (GND)
HR_INT: R19.1, TP21.1, U6.13 (~INT); also elsewhere on the board
IMU_INT: Q4.3 (D), R32.1, TP22.1; also elsewhere on the board
unnamed: Q2.2 (S), R20.2, R24.2, U8.11 (HSDX)
unnamed: Q3.2 (S), R22.2, R25.2, U8.33 (HSCX)
unnamed: Q4.2 (S), R31.2, U8.10 (HIRQ)
unnamed: C40.1, C41.1, C42.1, U6.9 (VLED+), U6.10 (VLED+), U7.5 (VOUT)
unnamed: C52.1, U8.6 (VREG)
SCL: Q3.3 (D), R18.1, R23.1, U6.2 (SCL), U9.1 (SCX); also elsewhere on the board
SDA: Q2.3 (D), R17.1, R21.1, U6.3 (SDA), U9.2 (SDX); also elsewhere on the board

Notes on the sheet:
MAX30102 Heart Rate and Pulse Oximeter Circuit
BHI260 Inertial Measurement Unit Circuit
BMP585 Barometric Pressure Sensor Circuit

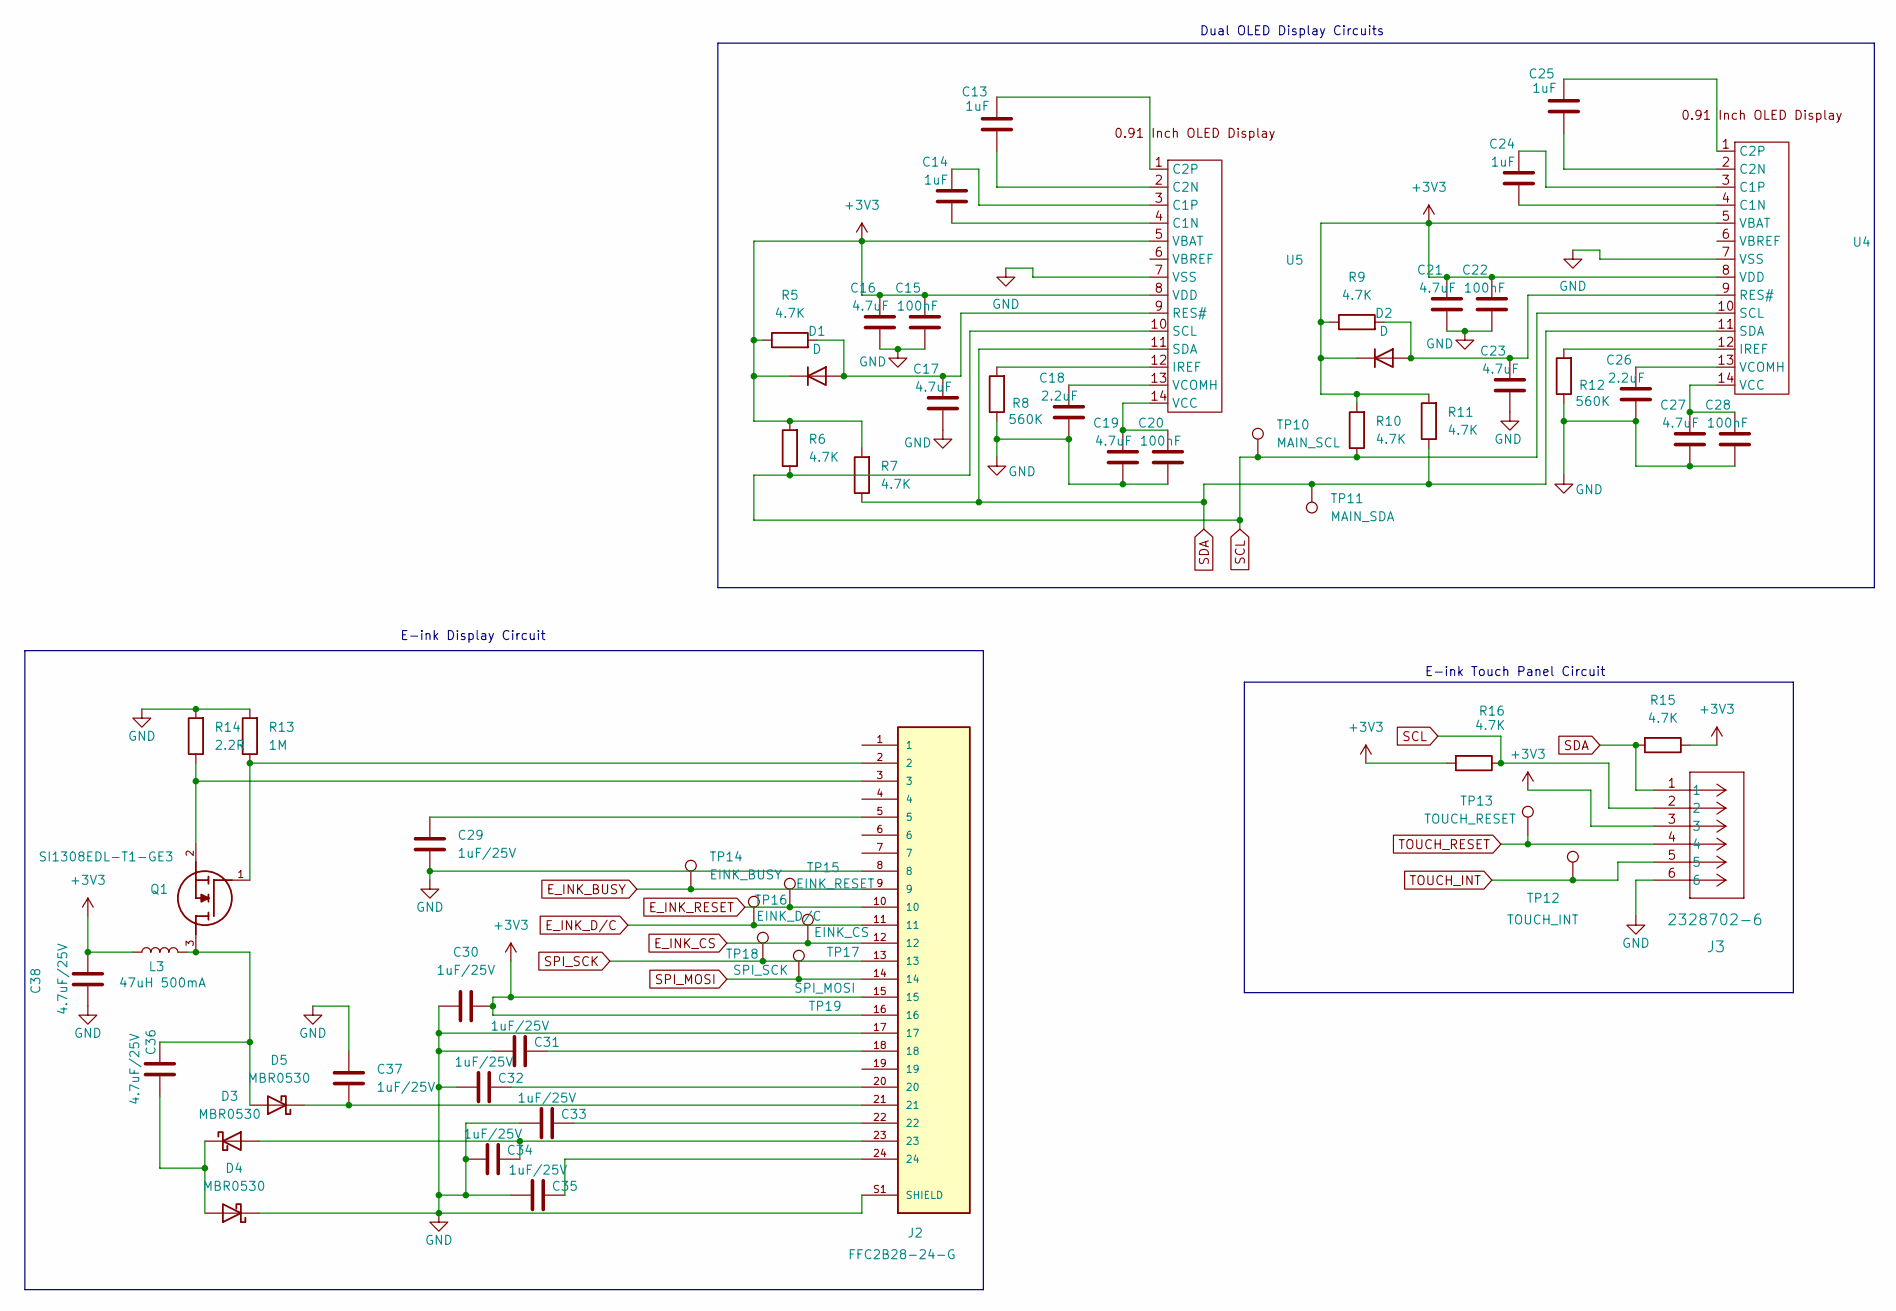
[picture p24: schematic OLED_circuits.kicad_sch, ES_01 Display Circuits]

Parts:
C13, C14, C24, C25: 1uF; C_0402_1005Metric_Pad0.74x0.62mm_HandSolder
C15, C20, C22, C28: 100nF; C_0402_1005Metric_Pad0.74x0.62mm_HandSolder
C16, C17, C19, C21, C23, C27: 4.7uF; C_0402_1005Metric_Pad0.74x0.62mm_HandSolder
C18, C26: 2.2uF; C_0402_1005Metric_Pad0.74x0.62mm_HandSolder
C29, C30, C31, C32, C33, C34, C35, C37: 1uF/25V; C_0402_1005Metric_Pad0.74x0.62mm_HandSolder
C36, C38: 4.7uF/25V; C_0402_1005Metric_Pad0.74x0.62mm_HandSolder
D1, D2: D; D_DO-35_SOD27_P7.62mm_Horizontal
D3, D4, D5: MBR0530; D_0805_2012Metric_Pad1.15x1.40mm_HandSolder
J2: FFC2B28-24-G; GCT_FFC2B28-24-G; PARTREV A
J3: 2328702-6; CONN6_2328702-6_TEC
L3: 47uH 500mA; Untitled
Q1: SI1308EDL-T1-GE3; SOT65P210X110-3N; Mouser_Part_Number 78-SI1308EDL-T1-GE3
R5, R6, R7, R9, R10, R11, R15, R16: 4.7K; R_0402_1005Metric_Pad0.72x0.64mm_HandSolder
R8, R12: 560K; R_0402_1005Metric_Pad0.72x0.64mm_HandSolder
R13: 1M; R_0402_1005Metric_Pad0.72x0.64mm_HandSolder
R14: 2.2R; R_0402_1005Metric_Pad0.72x0.64mm_HandSolder
TP10: MAIN_SCL; TestPoint_Pad_D1.0mm
TP11: MAIN_SDA; TestPoint_Pad_D1.0mm
TP12: TOUCH_INT; TestPoint_Pad_D1.0mm
TP13: TOUCH_RESET; TestPoint_Pad_D1.0mm
TP14: EINK_BUSY; TestPoint_Pad_D1.0mm
TP15: EINK_RESET; TestPoint_Pad_D1.0mm
TP16: EINK_D/C; TestPoint_Pad_D1.0mm
TP17: EINK_CS; TestPoint_Pad_D1.0mm
TP18: SPI_SCK; TestPoint_Pad_D1.0mm
TP19: SPI_MOSI; TestPoint_Pad_D1.0mm
U4, U5: Untitled

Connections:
+3V3: C15.1, C16.1, C21.1, C22.1, C30.2, C38.2, D1.1 (K), D2.1 (K), J2.15, J2.16, J3.3, L3.1, R5.1, R6.2, R7.2, R9.1, R10.2, R11.2, R15.1, R16.2, U4.5 (VBAT), U4.8 (VDD), U5.5 (VBAT), U5.8 (VDD); also elsewhere on the board
E_INK_BUSY: J2.9, TP14.1; also elsewhere on the board
E_INK_CS: J2.12, TP17.1; also elsewhere on the board
E_INK_D/C: J2.11, TP16.1; also elsewhere on the board
E_INK_RESET: J2.10, TP15.1; also elsewhere on the board
GND: C15.2, C16.2, C17.2, C18.2, C19.2, C20.2, C21.2, C22.2, C23.2, C26.2, C27.2, C28.2, C29.2, C30.1, C31.1, C32.1, C33.1, C34.1, C35.1, C37.1, C38.1, D4.1 (K), J2.8, J2.17, J2.S1 (SHIELD), J2.S2 (SHIELD), J3.6, R8.1, R12.1, R13.2, R14.2, U4.7 (VSS), U5.7 (VSS); also elsewhere on the board
unnamed: C29.1, J2.5
unnamed: C31.2, J2.18
unnamed: C32.2, J2.20
unnamed: C33.2, J2.22
unnamed: C35.2, J2.24
unnamed: C17.1, D1.2 (A), R5.2, U5.9 (RES#)
unnamed: C23.1, D2.2 (A), R9.2, U4.9 (RES#)
unnamed: C34.2, D3.2 (A), J2.23
unnamed: C36.1, D3.1 (K), D4.2 (A)
unnamed: C36.2, D5.2 (A), L3.2, Q1.3
unnamed: C37.2, D5.1 (K), J2.21
unnamed: J2.2, Q1.1, R13.1
unnamed: J2.3, Q1.2, R14.1
unnamed: C24.2, U4.4 (C1N)
unnamed: C24.1, U4.3 (C1P)
unnamed: C25.2, U4.2 (C2N)
unnamed: C25.1, U4.1 (C2P)
unnamed: R12.2, U4.12 (IREF)
unnamed: C27.1, C28.1, U4.14 (VCC)
unnamed: C26.1, U4.13 (VCOMH)
unnamed: C14.2, U5.4 (C1N)
unnamed: C14.1, U5.3 (C1P)
unnamed: C13.2, U5.2 (C2N)
unnamed: C13.1, U5.1 (C2P)
unnamed: R8.2, U5.12 (IREF)
unnamed: C19.1, C20.1, U5.14 (VCC)
unnamed: C18.1, U5.13 (VCOMH)
SCL: J3.2, R6.1, R10.1, R16.1, TP10.1, U4.10 (SCL), U5.10 (SCL); also elsewhere on the board
SDA: J3.1, R7.1, R11.1, R15.2, TP11.1, U4.11 (SDA), U5.11 (SDA); also elsewhere on the board
SPI_MOSI: J2.14, TP19.1; also elsewhere on the board
SPI_SCK: J2.13, TP18.1; also elsewhere on the board
TOUCH_INT: J3.5, TP12.1; also elsewhere on the board
TOUCH_RESET: J3.4, TP13.1; also elsewhere on the board

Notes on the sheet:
E-ink Display Circuit
Dual OLED Display Circuits
E-ink Touch Panel Circuit

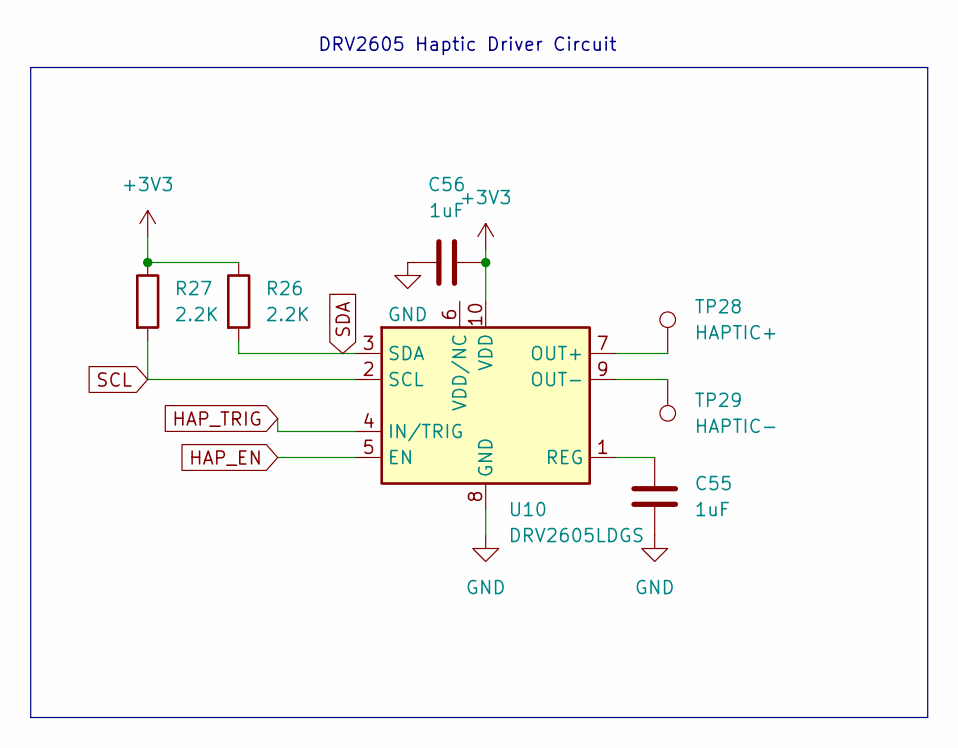
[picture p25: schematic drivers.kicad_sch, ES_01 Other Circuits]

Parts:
C55, C56: 1uF; C_0402_1005Metric_Pad0.74x0.62mm_HandSolder
R26, R27: 2.2K; R_0402_1005Metric_Pad0.72x0.64mm_HandSolder
TP28: HAPTIC+; TestPoint_Pad_1.5x1.5mm
TP29: HAPTIC-; TestPoint_Pad_1.5x1.5mm
U10: DRV2605LDGS; VSSOP-10_3x3mm_P0.5mm

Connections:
+3V3: C56.2, R26.1, R27.1, U10.10 (VDD); also elsewhere on the board
GND: C55.2, C56.1, U10.8 (GND); also elsewhere on the board
HAP_EN: U10.5 (EN); also elsewhere on the board
HAP_TRIG: U10.4 (IN/TRIG); also elsewhere on the board
unnamed: TP28.1, U10.7 (OUT+)
unnamed: TP29.1, U10.9 (OUT-)
unnamed: C55.1, U10.1 (REG)
SCL: R27.2, U10.2 (SCL); also elsewhere on the board
SDA: R26.2, U10.3 (SDA); also elsewhere on the board

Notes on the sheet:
DRV2605 Haptic Driver Circuit

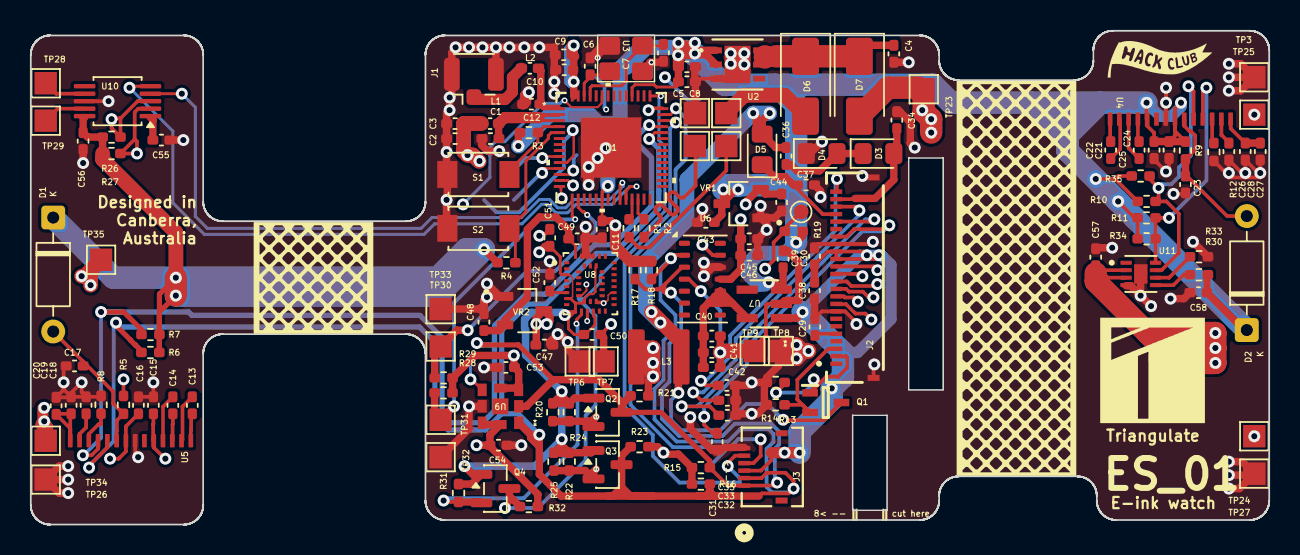
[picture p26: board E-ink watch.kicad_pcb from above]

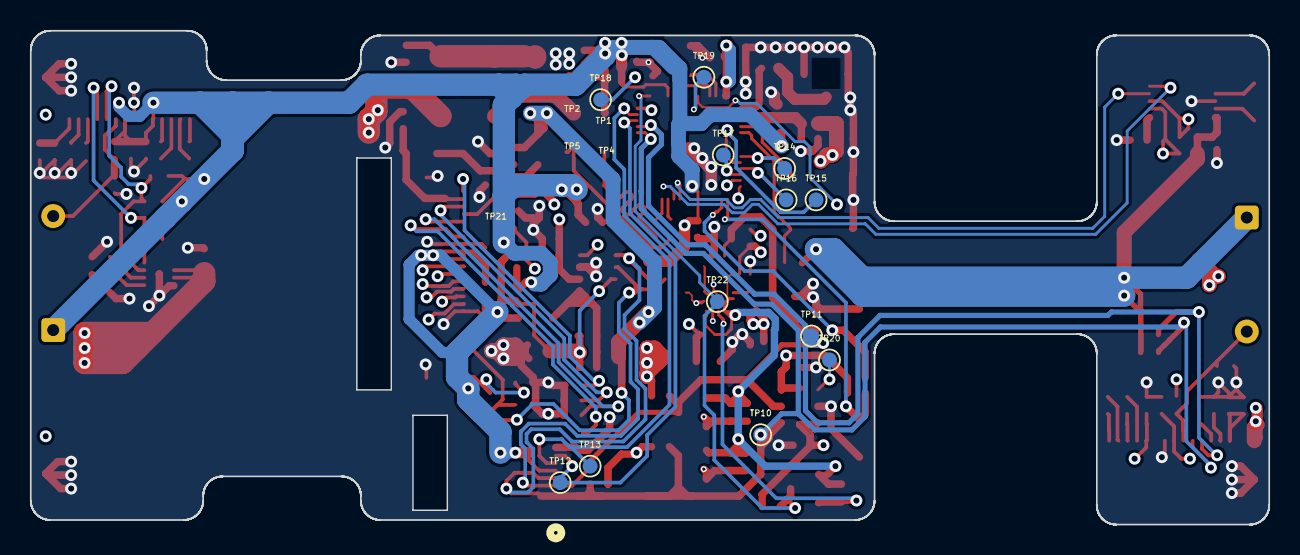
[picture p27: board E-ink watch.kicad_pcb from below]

Board: 4 copper layers, 82.8 x 33.0 mm, 160 parts (12 on the bottom side), 75 nets.

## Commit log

2026-03-17 init pcb and schematic v0.1
    [latchup_detect_recover_v0_1.kicad_pcb, latchup_detect_recover_v0_1.kicad_sch]
2026-03-18 schematic has amp and comp
    [latchup_detect_recover_v0_1.kicad_sch]
2026-03-18 import lib for or gate and shunt
    [SN74HC32N.step, SN74HC32PWR.step, latchup_detect_recover_v0_1.kicad_sch]
